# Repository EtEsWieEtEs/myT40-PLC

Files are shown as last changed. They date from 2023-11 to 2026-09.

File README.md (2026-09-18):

# myT40-PLC  (SPS) based on Teensy 4.0 (Version-5)
Hardware for PLC based on Teensy 4.0, covering all my needs. I have to replace my 30 years old PS4-141-MM1 from "Klöcker Moeller", reusing the original case of this model PS4-141-MM1.

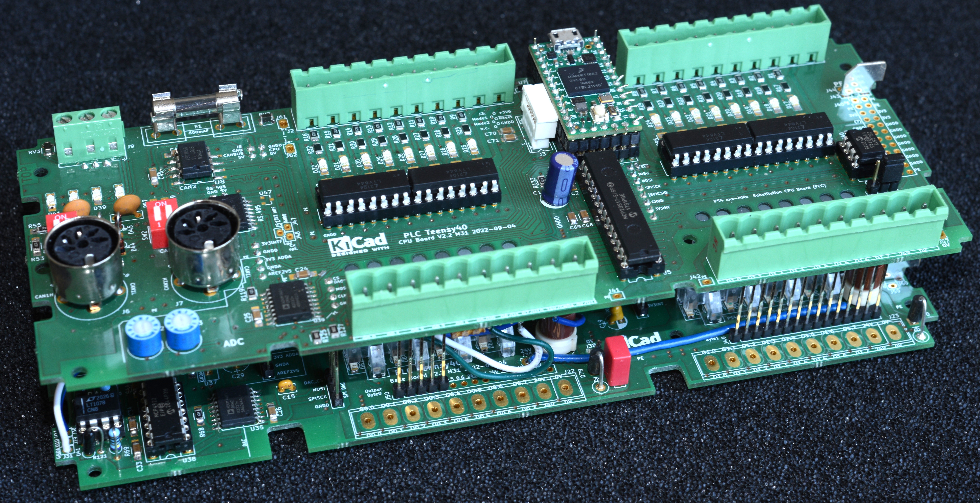
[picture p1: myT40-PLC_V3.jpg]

Picture: Prototype V3

Motivation for a “Mighty 40”
----------------------------
Since the late 1990s, I have been working with four used PS4-141s, one PS4-341, both controllers from Klöckner Moeller, and about two dozen 24V AC surge relays (unfortunately not DC), commonly known as “Eltako,” I planned and developed my “smart home” in the late ’90s and installed it in my new house in 2002. 
The bus systems for building automation that were already on the market at the time were out of the question for me due to licensing issues and costs. 
These control units are networked and seamlessly integrated into my sub-distribution panels—commonly known as “fuse boxes”—on a circuit breaker (C) rail installed at the rear, just like standard circuit breakers. Circuit protection, power, and control are clearly separated in accordance with VDE standards.

Using serial communication, the master controller can be configured during operation using a user-friendly VB program (timer functions, lighting, roller shutters, light level detection, assignment of switches to power outlets such as wall sockets or ceiling outlets for lamps, etc.).

Since these controllers or similar devices are no longer manufactured in this format, the first failures occurred after nearly 30 years of trouble-free operation, and no other manufacturer offers affordable controllers with galvanic isolation(!) in this format anymore, I decided to strip down the PS4-141 housings and develop a new circuit that handles the most important functions and fits into these very housings I have on hand, hereinafter referred to as the “original housing.”

The result is "myT40-PLC", a combination of extention slot of PS4-341 in the housing of an P4S-141.

It is not intended to create a replica of the original, nor is that the goal. Externally, the case has been noticeably modified and fitted with different connectors: the “myT40-PLC”.

Since the circuit itself might also be of interest to others, I designed the main board in two versions for J3: one with an FFC connector, the “FFC” version, for my personal replacement in the original case, and a standard version with a pin header, the “PFS” version, to inspire replicas in any case. The latter is presented here.

This pin header connector "PFS" version offers a 2x DAC option and a 2x ADC option, while allowing the use of all 32 digital I/O channels and providing Sub-D connectors for bus systems in a separate housing. This distinguishes it from the FFC version, which cannot optionally provide all outputs when the DAC and ADC are installed and connected.

A parallel project, myT41-Controller, focuses on a controller unit that provides a graphical interface, Ethernet, CAN and RS485 buses, as well as a serial OTA interface, and allows the myT40 PLC to be controlled, logged, and configured.
With appropriate programming, the myT41C controller can also be used as a protocol converter or logger on the interfaces for entirely different projects.

The software will be documented separately at a later date.
This document describes only the hardware-related port definitions that result from the circuit and are essential for programming.

Attended documents describe the "Final Version V5" as "V3.3 M44", based on experience of 4 prototypes build up in the past 5 years.

The current Version is the final one waiting to be build-up: V5.
I made a lot of changes and enhancements and transfered these features as well to the myT41-Controller.

myT40-PLC      Requirements for my new PLC
------------------------------------------
Even though the new circuit cannot meet all the requirements of the original, I still have a clear idea of what it will be capable of.
The new controller should

1. be installed in my existing original enclosures or any other enclosures,
2. be networked so it can communicate with other devices,
3. ensure isolated potentials for inputs, load circuits, bus systems, ADC/DAC, and controllers; therefore, commercially available Arduino- or Raspberry Pi-based PLCs are out of the question,
4. provide 16 digital inputs and 16 digital outputs as needed, with isolated potentials,
5. support interrupts for input bytes,
6. Provide 4 analog-to-digital converter inputs if required, two of these are fed via built-in setpoint potentiometers,
7. Provide 2 digital-to-analog converter outputs if required,
8. Process analog signals from 0..10V, ADC and DAC, with their own reference potential,
9. Support up to two CAN buses, galvanically isolated, optionally GND, PE shield via capacitor,
10. Provide an RS485 interface for 16 clients, galvanically isolated, bus termination with low-drop diodes or optionally classically with switchable terminating resistor 720/120/720 ,
11. RS485 connection corresponds to the original (V5); the DIN sockets combine CAN1/2 and RS485,
12. be based on a modern, fast processor with sufficient RAM,
13. be supported by an EEPROM/Flash memory,
14. have ICs mounted on sockets wherever possible,
15. support a mode selector switch with 3 modes, including a setting for a cold start via RESET,
16. be able to use the existing RESET button,
17. be able to trigger a RESET via software, including a choice between cold or warm start,
18. ensure local communication via SPI for the interface and function modules,
19. be energy-efficient and operate at 3.3V,
20. be programmed in C or C++,
21. allow communication with a PC or a control unit via CAN, RS485, Ethernet,
22. enable flexible programming,
23. feature a pluggable, wired 3.6V backup lithium battery with its own ADC monitoring,
24. Respond to the 24V AC “Eltako” devices present in the building’s electrical system with 5ms DC pulses (!),
25. Monitor the supply voltages of the CPU and the direct interfaces and, if necessary, perform a warm start or cold start with a reset,     
26. Control the onboard hardware watchdog and/or software watchdog in combination with the operating mode switch, or allow them to function independently.
27. Does not support flexible docking of various original expansion modules; however, a suitable connection panel for SPI and digital I/O is available, though it is incompatible with original expansion modules. Instead, equip the existing 16-channel digital output unit with a new “header board” to make	it usable.
28. No online programming or programming via network, although this might actually be possible.
29. No PWM support on the outputs or counter features on the inputs.
30. External hardware watchdog with adjustable times, including a definable delay on RESET and restart (V5),
31. Buttons for Teensy 4.0 boot/program and on/off (V5),
32. OTA option (V5).
33. F-RAM SPI Option based on SOIC-8

Current developement
---------------------
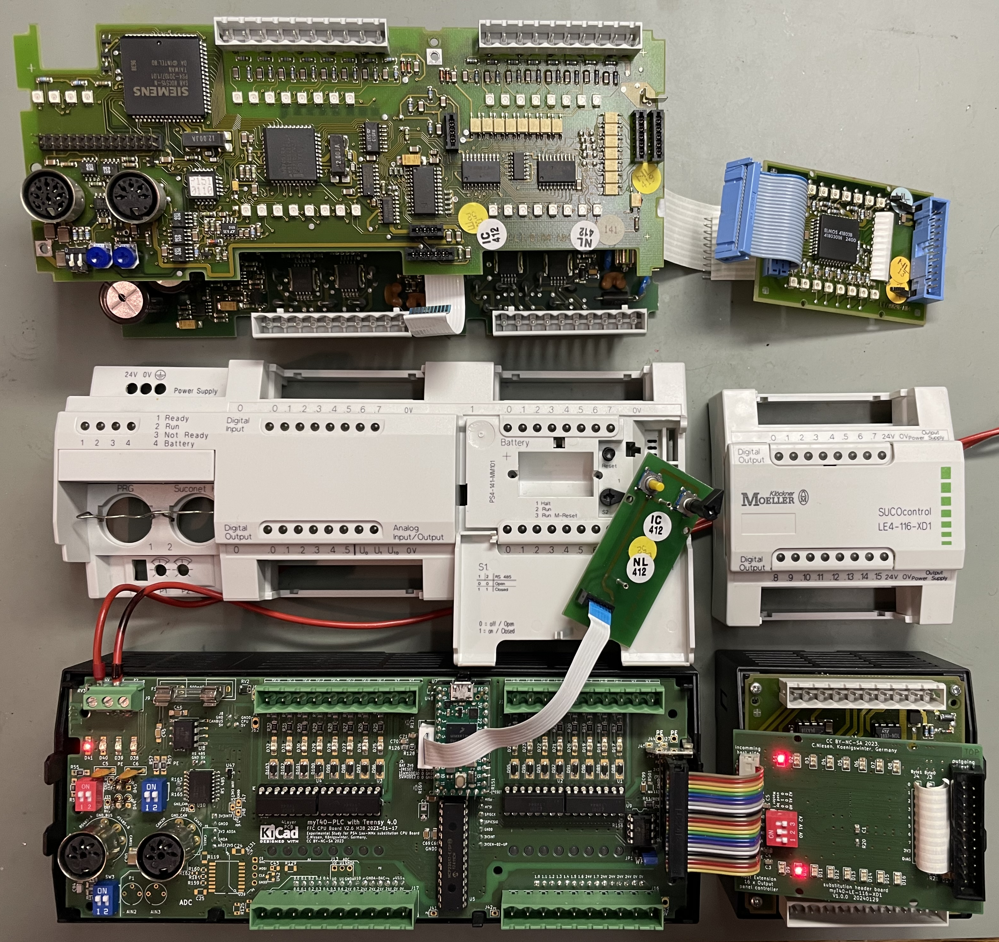
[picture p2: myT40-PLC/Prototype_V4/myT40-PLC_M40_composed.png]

Picture: Prototype V4 below, original defective pcb at top

Now that the Prototype 4 (V4) is working successfully with a 4-layer PCB, I have added an external watchdog and a delay into Version 5.

V5 offers optionally the use of OTA via one of the two serial interfaces instead of a second CAN bus.

Furthermore I think F-RAM is a good alternative for often changed written data to be stored permantly. So V5 provides a place for SOIC-8 alterntive to EEPROM in DIL-8.

However, Version 5 has not yet been built or tested. That is planned for the coming months.

There are some things to do like translation of documentation into English or Spanish, perhaps in next winter.
The current documentation is in German. 
So please be pacient, feel free and be inspired.

Licence
---------------------
This work is licensed under the Creatjve Commons Atuributjon-NonCommercial-ShareAlike 4.0 Internatjonal
License. To view a copy of this license, visit htup://creatjvecommons.org/licenses/by-nc-sa/4.0/ or send a
letuer to Creatjve Commons, PO Box 1866, Mountain View, CA 94042, USA.
This license lets others remix, adapt, and build upon your work non-commercially, as long as they credit you
and license their new creatjons under the identjcal terms.
htup://creatjvecommons.org/licenses/by-nc-sa/4.0/

  Title    myT40-PLC Documentation

  Author   Clemens Niesen, Germany, 2026

  Source   These documents

  Licence  CC-BY-NC-SA

DISCLAIMER
----------

I explicitly state that I make no representations or warranties regarding non-infringement or the absence of other defects with respect to the CC-licensed work.This means that users use the work at their own risk.

Furthermore, I point out that this project and the content of this documentation, as well as associated files, is purely a recreational project and should be understood as a case study for the reader. 

This project, these circuits are not tested or approved by official bodies. Errors can not be excluded despite all care. Whoever reproduces this project does so at his own risk and responsibility. I do not take any responsibility for damages to persons and devices, material, buildings, animals, etc..

Rebuilding is reserved exclusively for experienced people who know exactly what they are doing.  What third-party use of the control with third does and does not, lies apart from the craftsmanship of the construction also with the software, which is also beyond my responsibility. I give no guarantee and take no responsibility for the content of references, links and quotes.

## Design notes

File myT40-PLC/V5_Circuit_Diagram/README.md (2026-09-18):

# myT40-PLC Rev3.3 M44 V5

Die Version-5 (Rev3.3 M44) ist fertig.

Folgende Anpassungen wurden am Prototyp-4 vorgenommen, Ergebnis ist nun die Version-5:
			
2024-02-29	Beschriftungskorrektur FFC 4-Layer, Versionsdatum auf OP-TOP von 2023-01-17 auf 2024-01-17

2024-05-09	M40 Rev.2.8 FFC-4Layer, OP+UP Korrekturen V4 zum Kaltstart: im ausgeschalteten Zustand kein Start möglich ((DOKU FÜR ANPASSUNG VON M38-Platinen))
			- UP: U51 Verpolung von Ub an Pin-3 und Pin-5: Ist= Pin-5:GNDD 0V, Pin-3:Vcc 5V, Soll: Pin-5:Vcc 5V, Pin-3:GNDD, 2 Platinenunterbrechungen und zwei Brücken
			  Man sollte Einzelgatter nicht einfach drehen, und erwarten, dass die Spannungsversorgungsanschlüsse noch die gleiche Orientierung haben...
			- OP: Spannungsteiler R126 und R128 arbeiten nicht im Falle des Systemstarts. Off-Widerstand ist 4080 Ohm von Teensy-Pin-3 (SW_MODE_2)
			  - R126 10k ersetzt durch 220 Ohm SMD 0805  (OP)
			  - R128 16k ersetzt durch Zener-Diode ZF 3,0 Baugröße SOD80(minimelf) ((BZY55B3V0: SMD 0805 zu teuer, wenn man sie als einzige bei mouser bestellt))
			  Damit ist die UinHigh am ODER-Gatter auch größer als 2,3V bei eingesetztem Teensy40
			- RESET ähnlich: RESET=High wird nicht erzeugt, wenn Steuerung startet. Grund: R501||R50=4k76 und Innenwiderstand µC am Teensy40-Pin-4 beträgt 1,341V bei 3,3V Ub PullUp ca. 3258 Ohm. 
			  Damit ist UresetHigh=1,34V zu klein für ODER-Gatter (UinHighMin=2,1V), NE555 wird daher nicht getriggert.
			  - R501 OP) entfällt , da PullUp zu 3V3_INTERFACE , abgeschaltet durch Q2, daher unsinning
			  - R50  10k (UP) ersetzt durch 220 Ohm SMD-0805 , PullUp zu 3V3, erzeugt ein UinHigh am ODER-Gatter von 2,1V mit eingesetztem Teensy40
			  OP: U49 Mit Prototyp-4 muss hier ein Voltage-Translator verwendet werden, Ub=5V, UinA/B 3,3V Level : SN74LV1T32DBVR oder SN74LV1T32DBVRG4
			  UP: Darstellung Modell-Platinen-Aufdruck D51 gedreht, Anode jetzt auf Ub, 
			      D-Symbole in Bedruckung eingezeichnet.
			  OP: Darstellung Modell J3 korrekt gedreht
2024-06-30	Da die CPU beim Start weit über 100mA zieht, fällt die Versorgungsspannung auf 3,4V und U48 löst einen RESET=Low aus. 
			Im Falle von SW_MODE_2=Low für einen Kaltstart beduetet das eine Endlosschleife vor dem Start der CPU. U48 entfällt.
			Aus dem gleichen Grund wird C1, Glättung auf der 3,3VInterface-Schiene entfernt, 100µF sind zu groß.
			C1 bleibt erst einmal ohne Bestückung und damit optional.
	
2024-06-09	M41 Rev.2.9 FFC-4-Layer: OP+UP Verbesserung und Korrekturen von M40 eingebaut: 
			3V3 kommt über weiteren Pin (J34/J36) von UP nach OP, statt aus örtlich permanent vorhandener 5V_CPU_IN mittels Zenerdiode 3V0
			- Damit entfällt die 3V-Zener-Diode D50 von Rev_2.8_M40
			- Der Widerstand R126 wird von 2k7 auf 1k oder 220 Ohm geändert.
			
2024-08-03	M42	Rev.3.0 FFC-4-Layer: OP
			Hardware Watchdog hinzugefügt TPS3431, PullUp Diode D50 nötig, da TPS3431 einen open collector hat, muss PushPull des U49 beschnitten werden.
			Prog und OnOff auf Switches SW4 und SW5 gelegt, am Platinenrand von außen erreichbar
2024-06-10	SMD Testpoints TP1-4 für LED1(WDin), 3V3, TR, Q

2024-11-7	M43	Rev.3.1 FFC-4-Layer: OP
			Aus M39 RS485-Beschaltung übernommen: RS485 Belegung identisch zum Original, CAN1+RS485 auf J7, CAN1+CAN2 auf J6
			Jumper JP6 entscheidet ob auf J7-Pin-2 GND von CAN oder RS485 anliegt, Jumper erreichbar im Schacht
			SW2 von CAN2 und Busabschluss-Dioden RS485 haben Positionen getauscht.
			Leiterbahnführungen überarbeitet, Lage der GND-Potentiale auf den den Signalen gegenüberliegenden Layern korrigiert
			Kompatibilität zu M42 bleibt erhalten
			
2025-04-06	M43 Konvertierung nach KiCad6 und KiCad7
			UP von HomeTeensy40_PFS-4_3.0_M42, kompatibel zu OP M38 und OP M43
			OP von HomeTeensy40_FFC-4_3.0_M42-RS485-Sond als HomeTeensy40_FFC-4_3.0_M42-RS485-Sond_K7
			Diverse Leiterbahn-Optimierungen

2025-05-03	M43	Rev.3.1 FFC-4-Layer: OP
			///TPS3890 Delay bei Kaltstart für Watchdog von 16s, als Idee skizziert
			Watchdog-Zeiten festgelegt: 1.6s, 3,6s, 11s, 20s
			Kompatibilität zu M42 bleibt erhalten

2025-07-08	M43	Rev.3.1 FFC-4-Layer: OP
			///U52 NE555-CMOS Delay bei Kaltstart für Watchdog bei jedem RESET von 1,6-12,7sec, als Idee skizziert
			///U53 Inverter CMOS, invertiert Ausgang NE555 , um eine Einschaltverzögerung zu bekommen.
			///RESET steuert U52, damit beginnt der Delay für den WD bei Kalt- und Warmstart.

2025-08-14	M43	
			Delay bei Kaltstart für Watchdog: U52 kein NE555 und kein TPS3890 sondern ein S-80929CNMC 
			( HIGH-PRECISION VOLTAGE DETECTOR WITH DELAY CIRCUIT (EXTERNAL DELAY TIME SETTING))
			steuert EN_WD am HW-WD an und verzögert dessen Aktivierung, wenn TR_U50 wieder High wurde, bzw bei KaltStart mit C106=3µ3 für 18sec
			U53 Buffer-Inv für LED D123/R175 auf EN_WD  , On wenn EN_WD=Low
			U54 Buffer-Inv für LED D123/R175 auf TR_U50 , On wenn TR_U50=Low
			
2025-10-05	M43 FFC für J3 mit PFS erzeugt. Abschluss als V3.1

2025-12-31	M43 FFC + PFS V3.1
			OP : Vertauschen von CAN1 und CAN2 am Teensy. Das ermöglicht die optionale Nutzung der Seriellen Schnittstelle RX1/TX1 alternativ zu CRX1/CTX1 für ein OTA-Modul
			Dabei steht CAN2 auf beiden DIN-Buchsen zur Verfügung, parallel zu RS485.

2026-05-17	M43 FFC + PFS V3.2 , OP & UP   --> V5
			U40 und R50 auf die OP. U40 mit Reset-Ausgang auf TR-U50, R50 als Pull-UP für RESET.
			Das hat den Vorteil, dass ein Spannungsabfall unter die Schwelle von U40, CPU und Interfaces abschaltet.

FFC only:
========================

2026-05-26	M43 FFC V3.2 , OP & UP   --> V5
			Modifikation der PE-Flächen-Abstände zu anderen Potentialen auf mindestens 1mm in allen Lagen
			OP in PFS noch nicht angepasst.
			LED1 Leiterbahn verlegt, da zu nah an PE
			Alternative zu ISO1050 ist der ADM3050E, der einen vertauschten Anschluss für TXD und RXD hat.
			Um für deren eventuelle Verwendung einen Leiterbahnpatch zu ermöglichen, wurden die Endstücke der CAN1RX/CAN2TX vom inneren Layer 
			IN1 auf B-Layer per Via gelegt. Siehe B-Silk-Markierungen "X" bei "*3" unter der Teensy CPU. Das gleiche ist am ISO1050 für beide
			Busse möglich.
			PE-Optimierung im DIN-Anschluss-Feld

2026-05-31	M43 FFC V3.2 , OP & UP   --> V5
			Komplett-Modifikation Potential-Abstände OP und UP in Version FFC
			J8/J21, J36/J34 neu geteilt und auf mehr Abstand GNDD zu GND_CAN
			J25/J24 geteilt und zu J33/J47 auf mehr Abstand für GNDD und GNDA
			PE und LED1,2,3 Leitungsführung optimiert. Ub_CAN geändert.
			RV4, RV5, RV6 Isolierte GND_*-Potentiale mit 46VAC gegen PE abgesichert
			CANRX/CANTX Leitungen getauscht um PROG- und ONOFF-Switch unter die CPU verlagern zu können, damit Abstand von GNDD-bezogenen
			Potentialen zu PE und 24V-Input vergrößert werden kann.
			Mindest-Abstand überall mindestens 1,1mm.

(2026-07-25)	M43 FFC V3.2 , OP        --> V5
			U55 SOIC-8 Alternativer Foodprint zu DIL-8 von U9, z.B. auch für FM-25er SPI-FM-RAM
			CS für U55 kann durch auftrennen auch separat angesteuert werden (Fädeldraht von anderem ungenutzten CS-Signal).
			Damit waren zwei Speicherbausteine ansprechbar, einer in DIL-8 und ein zweiter mit SOIC-8.

2026-07-25	M44 FFC V3.3 , OP & UP   --> V5
			OP: U55 SOIC-8 Alternativer Foodprint zu DIL-8 von U9, z.B. auch für FM-25er SPI-FM-RAM
			    CS für U55 kann durch auftrennen auch separat angesteuert werden (Fädeldraht von anderem ungenutzten CS-Signal).
			    Damit waren zwei Speicherbausteine ansprechbar, einer in DIL-8 und ein zweiter mit SOIC-8.
			    R172 versetzt, war zu dicht an J3
			UP: Output-LED intern angesteuert. Es entfallen die Bauteile R102-R109, D106-D113, R110-R117, D114-D121
			OP: R173 und D52, beide optional sind entfallen, da eine Kombination mit einer UP V4 nicht mehr möglich ist, wegen der
			    Verschiebung der Potentiale an den Verbindungen zwischen OP und UP.
20260904	M44 PFS V3.3, OP + UP    --> V5 
			Variante PFS bereitgestellt.

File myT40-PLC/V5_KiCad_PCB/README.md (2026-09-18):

KiCad 9.0.7

myT40-PLC Rev3.3 M44 V5 PFS

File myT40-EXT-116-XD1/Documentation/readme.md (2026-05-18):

Modification of existing original local extension unit LE-116-XD1.

Documentation found in document for myT40-PLC chapter 14.

Keep in mind, that this reflects a modification of an original LE-116-XD1 module.
This is the description how to connect this 16-Output module to myT40-PLC using the modified extension slot.
To make this possible, the existing header PCB must be exchanged by this one decribed here.

Original extention modules must not connect to myT40-PLC, due to different and unknown protocol and connectivity.

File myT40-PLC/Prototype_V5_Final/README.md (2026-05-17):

Final Version V5 has not been build yet.

You see here KiCad Views only.

Production is planned for next months.

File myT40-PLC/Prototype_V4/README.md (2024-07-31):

You see here myT40-PLC and a modified 16 channel digital IO fitted to myT40-PLC.

- myT40-PLC V4 below mounted in open original case,
- top part of original case in the middle,
- removed original innards on top

I did not mount the parts for ADC nor DAC, because I won't used it in the role as master-PLC for my home automation project.
Next I will build up 5 other myT40-PLCs in different component compositions.

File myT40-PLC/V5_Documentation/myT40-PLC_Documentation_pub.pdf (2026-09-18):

# myT40-PLC

### Neue PLC im alten Gewand – Eine Studie

Upcycling einer defekten KlöcknerMoeller SPS PS4-1x1

Rev3.3 - *nale Version 5 - PFS/FFC
Ein An1depressivum aus Corona-Zeiten

Clemens Niesen
2020-2026

myT40-PLC | Historie
Version 0.0 | ab Mai 2018 | Gedankenspiele mit Arduino Due
Ausprobieren von KiCad 4.x
Version-0 | 1.12.2020 | Steckbre%-Au&auten mit Teensy 4.0 und 4.1
Version-1 | 22.4.2021 | PLC HT40 | M00 | V1.2.1 (Prototyp1)
Version-2 | 16.01.2022 | PLC HT40 | M16 | V1.5 | (Prototyp2) | (Titelbild¹ )
Version-3 | 04.09.2022 | PLC HT40 | M31 | V2.2 | (Prototyp3)

Projekt umbenannt in myT40-... im August 2023

Version-4 | 23.11.2023 | myT40-PLC | M38 | V2.6 | (Prototyp4)
17.01.2024 | myT40-PLC | Modi4ka5onen & 4-Layer für OP
Version-5 | 31.08.2024 | myT40-PLC | M42 | V3.0 | (Version nal PFS)
Modi4ka5onen OP/UP
External HW-Watchdog
Bu%ons OnO@/Prog
Version-5 | 11.08.2025 | myT40-PLC | M43 | V3.1 | (Version nal FFC+PFS)
FFC-Version: RS485 PS4-like Watchdog-Start-Delay
Update auf KiCad_V9
Version-5 | 31.12.2025 | myT40-PLC | M43 | V3.2 | (Version nal FFC+PFS)
OTA Op5on: CAN1 <-> CAN2 Tausch größere Poten5al-Abstände bei Verbindungen OP ↔ UP
Version-5 | 25.07.2026 | myT40-PLC | M44 | V3.3 | (Version nal FFC+PFS)
UP: Output-LED wieder intern angesteuert Sta5sches F-RAM im SOIC-8
Zuletzt edi5ert am 18.09.2026 | Dokumenta5on der Änderungen,
| | | | | siehe Kapitel 11

### 1 Titel-Foto: Es zeigt die Version V2 für ein beliebiges Gehäuse aus 2022

ii

### Licence

Dieses Werk ist unter einer Crea5ve Commons Lizenz vom Typ „Namensnennung - Nicht-kommerziell -Weitergabe unter gleichen Bedingungen 4.0 Interna)onal“ zugänglich. Um eine Kopie dieser Lizenz einzusehen, konsul5eren Sie h%p://crea5vecommons.org/licenses/by-nc-sa/4.0/ oder wenden Sie sich brieRich an Crea5ve Commons, PosSach 1866, Mountain View, California, 94042, USA.

Title | myT40-PLC Documenta)on
Author | Clemens Niesen, Germany, 2021-2026
Source | This document, and related ones
Licence | CC-BY-NC-SA

This work is licensed under the Crea5ve Commons „A2ribu)on-NonCommercial-ShareAlike 4.0 Interna)onal License“. To view a copy of this license, visit
h%p://crea5vecommons.org/licenses/by-nc-sa/4.0/
or send a le%er to Crea5ve Commons, PO Box 1866, Mountain View, CA 94042, USA.

This license lets others remix, adapt, and build upon your work non-commercially, as long as they credit you and license their new crea5ons under the iden5cal terms. h%p://crea5vecommons.org/licenses/by-nc-sa/4.0/

myT40-PLC C.Niesen CC-BY-NC-SA 2026 | iii

### Ha8ungsausschluss

Ausdrücklich weise ich darauf hin, dass ich keine Zusicherungen oder Garan)en hinsichtlich der Nichtverletzung von Rechten oder des Fehlens anderer Mängel in Bezug auf das CC-lizenzierte Werk gebe. Das bedeutet, dass die Nutzer das Werk auf eigenes Risiko nutzen.

Ferner weise ich darauf hin, dass dieses Projekt und der Inhalt dieser Dokumenta)on, sowie zugehöriger Dateien ein reines Freizeitprojekt und für den Leser als Fallstudie zu verstehen ist. Dieses Projekt, diese Schaltungen sind nicht durch o=zielle Stellen geprü> oder abgenommen. Fehler sind trotz aller Umsicht nicht auszuschließen. Wer dieses Projekt nachbaut, tut dies auf eigene Gefahr und Verantwortung. Für Schäden an Personen und Geräten, Material, Gebäuden, Tieren, etc. übernehme ich keinerlei Verantwortung. Der Nachbau ist ausschließlich versierten Menschen, die genau wissen was sie tun, vorbehalten. Was eine Verwendung der Steuerung bei Dri2en tut und was nicht, liegt neben der handwerklichen Ausführung des AuAaus auch an der So>ware, die sich ebenfalls meiner Verantwortung entzieht.

Ich gebe keine Gewähr und übernehme keine Verantwortung für den Inhalt von Verweisen, Links und Zitaten.

### DISCLAIMER

I explicitly state that I make no representa5ons or warran5es regarding non-infringement or the absence of other defects
with | respect | to | the | CC-licensed | work.This | means | that | users | use | the | work | at | their | own | risk.
Furthermore, I point out that this project and the content of this documenta5on, as well as associated 4les, is purely a recrea5onal project and should be understood as a case study for the reader. This project, these circuits are not tested or approved by oTcial bodies. Errors can not be excluded despite all care. Whoever reproduces this project does so at his own risk and responsibility. I do not take any responsibility for damages to persons and devices, material, buildings, animals, etc.. Rebuilding is reserved exclusively for experienced people who know exactly what they are doing. What third-party use of the control with third does and does not, lies apart from the craUsmanship of the construc5on also with the soUware, which is also beyond my responsibility. I give no guarantee and take no responsibility for the content of references, links and quotes.

Dieses Projekt widme ich meinem alten Freund Norbert Schulz aus Berlin Kreuzberg. Wir haben zusammen in den 70ern in Berlin-Tiergarten am Canis die Schulbank gedrückt.
Er hat mir zu meinen ersten Elektronik-Erfahrungen verholfen und eine bis heute anhaltende Begeisterung für dieses Thema geweckt.
Leider haben wir uns in den 80ern aus den Augen verloren.

Clemens Niesen

iv | myT40-PLC C.Niesen CC-BY-NC-SA 2026

## Inhalt

myT40-PLC C.Niesen CC-BY-NC-SA 2026 | v

vi | myT40-PLC C.Niesen CC-BY-NC-SA 2026

### 9.9 Berechnung Netzwerk digitale Ausgänge | 59 9.10 Berechnung Netzwerk Analoge Eingänge | 60 9.11 Hinweis Eingangs-Terminals „0V“ | 60 9.12 SPI-Serien-Widerstände | 60 9.13 Bezug DIN-5 Pol -Buchse | 60

### 10 So>ware myT40-PLC | 61

### 10.1 Prinzipieller Programmablauf und Kon4gura5on | 61

### 10.1.1 Port-De4ni5on der myT40-PLC | 62

### 11 Release Notes der Publika)on | 63

### 11.1 myT40-PLC | 63

11.1.1 V2.6 M36 Version-4 (PFS) erstmalig publiziert im August 2023 | 63 11.1.2 V2.6 M37 Version-4 (PFS) 23.11.2023 | 63 11.1.3 V2.6 M38 Version-4 (PFS) 17.01.2024 Pre-Final Prototype, produziert | 63 11.1.4 V3.0 M42 Version-5 (PFS+FFC) 03.08.2024 | 64 11.1.5 V3.2 M43 Version-5 (FFC) 17.05.2026 4nal version V5 | 64 11.1.6 V3.3 M44 Version-5 25.07.2026 4nal version V5 | 64

### 12 Stückliste Rev3.3 M44 V5, Variante PFS, Vollbestückung | 65

### 13 Erweiterungsmodul für 16 Ausgänge | 77

### 13.1 Die Schaltung des myT40-116-XD1 | 77 13.2 Schaltplan Lokale Erweiterung myT40-116-XD1 | 78 13.3 Pla5nenlayout myT40-116-XD1 | 79

### 14 Verwendete So>ware für dieses Projekt | 82

### 14.1 KiCad | 82 14.2 Arduino | 82 14.3 Teensyduino | 82 14.4 MicrosoU Visual Studio Code (VSC) | 83

### 14.4.1 VSC-Extension „C/C++ for Visual Studio Code“ | 83 14.4.2 VSC-Extension „C++ Intellisense“ | 83 14.4.3 VSC-Extension „German Language Pack for Visual Studio Code“ | 83 14.4.4 VSC-Extension „GitLens — Git supercharged“ | 83 14.4.5 VSC-Extension „PlaSormIO IDE“ alias PIO | 83

### 14.5 PIO - PlaSom IDE für Teensy | 83 14.6 PIO Libraries für Teensy / Arduino | 83

### 14.6.1 MCP_DAC by Rob Tillaart V 0.1.6 | 83 14.6.2 Mcp320x by Patrick Rogalla 1.4.2 | 83 14.6.3 GUIslice by Calvin Hass 0.16.0 / 0.17.x | 83 14.6.4 Hotboards_eeprom by Hotboards MX | 84 14.6.5 ACAN_T4 by Pierre Molinaro | 84 14.6.6 Teensy 4.x | 84

### 15 Datenaustausch myT41C-Controller mit myT40-PLC-Nodes | 85

myT40-PLC C.Niesen CC-BY-NC-SA 2026 | vii

## Abbildungsverzeichnis

Abbildung 3: Die Variante OP-PFS mit Pfostenstecker 2x4 Pin-Header für J3, einige Bauteile hier nicht

Abbildung 6: Prinzipschaltbild Kaltstart, Reset-Logik und Hardware-Watchdog mit Delay (ab V5 M43)

x | myT40-PLC C.Niesen CC-BY-NC-SA 2026

Abbildung 42: Final Prototype-5 Rev3.3 M44 V5: OP Layer : TOP, IN1, IN2 | 43
Abbildung 43: Alterna5ve Status-LED Verdrahtung FFC/PFS Rev-3.3 M44 V5 | 49
Abbildung 44: Ground für RS485- oder CAN-Bus | 53
Abbildung 45: Extension-Slot | 53
Abbildung 46: myT40-LE-116-XD1 Erweiterung für myT40 16 Digital Out, 500mA 24V | 78
Abbildung 47: myT40-116-XD1 Oberseite | 79
Abbildung 48: myT40-116-XD1 Unterseite | 79
Abbildung 49: Prototyp-V2 M16 in Eigenbaugehäuse aus 5mm Plexiglas | 104
Abbildung 50: Prototyp-V2 M16, Seitenansicht | 104
Abbildung 51: Die fer5g zusammengesteckten Pla5nen Rev2.2 M31, Prototyp-3, bestückt mit
ADC+DAC und 5 Ausgängen auf Byte-0, sowie drei Status-LED und 5 Ausgängen auf Byte-0 | 111
Abbildung 52: myT40-PLC Rev2.6 M38 V4 FFC Oberpla5ne Oberseite | 112
Abbildung 53: myT40-PLC Rev2.6 M38 V4 FFC Oberpla5ne Unterseite | 113
Abbildung 54: Prototyp-V4Rev2.8 M38 mit allen weiteren Korrekturen bis M40 und lau@ähigem
Kaltstart, sowie einer modi4zierten lokalen Erweiterung, beides im Originalgehäuse | 118
Abbildung 55: myT40-PLC Rev3.3 M44 V5 PFS Oberpla5ne Oberseite | 119
Abbildung 56: myT40-PLC Rev3.3 M44 V5 PFS Oberpla5ne Unterseite | 119
Abbildung 57: myT40-PLC Rev3.3 M44 V5 FFC Oberpla5ne Oberseite | 120
Abbildung 58: myT40-PLC Rev3.3 M44 V5 FFC Oberpla5ne Unterseite | 120
Abbildung 59: myT40-PLC Rev3.3 M44 V5 Unterpla5ne Oberseite | 121
Abbildung 60: myT40-PLC Rev3.3 M44 V5 Unterpla5ne Unterseite | 121
Abbildung 61: myT41C V1 Schaltplan | 123
Abbildung 62: myT41C Contoller V1 Rev1.0.2: Störungen auf T_IRQ, aufgestecktes Display nicht
dargestellt | 124
Abbildung 63: myT41C V1 : Einbau R-C-Glied in T_IRQ-Leitung | 124
Abbildung 64: myT41C Rev1.0.2 V1 Unterseite bestückt | 125
Abbildung 65: myT41C Rev1.0.2 V1, Unterseite THT unbestückt | 125
Abbildung 66: myT41C V2 Schaltplan Rev3.1 M10 , CPU und Peripherie | 126
Abbildung 67: myT41C V2 Schaltplan Rev3.1 M10 , Watchdog , Delay , Abschaltung | 127
Abbildung 68: myT41C Rev3.1 M10 , Oberseite ohne Display | 128
Abbildung 69: myT41C Rev3.1 M10 , Unterseite ohne THT Bestückung | 129
Abbildung 70: myT41C Rev3.1 M10 , Unterseite bestückt | 129
myT40-PLC C.Niesen CC-BY-NC-SA 2026 | xi

xii | myT40-PLC C.Niesen CC-BY-NC-SA 2026

myT40-PLC Documenta5on

## 1 Mo1va1on für einen „mighty 40“

Seit Ende der 90er Jahre habe ich mit vier gebrauchten PS4-141, einer PS4-341, beide Steuerungen der Fa. Klöckner Moeller, und rund zwei Dutzend 24V-AC-Stromstoß-Relais (nicht DC²
), landläu4g „Eltako“ genannt, mein „Smart-Home“ Ende der 90er geplant, entwickelt und 2002 in meinem Neubau installiert. Damals schon am Markt be4ndliche Installa5ons-Bus-Systeme kamen für mich wegen Lizenzen und Kosten nicht in Frage.

Diese Steuerungen sind vernetzt und in meinen Unterverteilungen, landläu4g „Sicherungskästen“ genannt, auf einer nach hinten verlegten Automaten-(C-)Schiene nahtlos wie normale Sicherungsautomaten
eingebaut. | Leitungsschutz, | Leistung | und | Steuerung | sind | VDE-konform | sauber | getrennt.
Mi%els serieller Kommunika5on kann der Master der Steuerungen mit einem komfortablen VB-Programm im laufenden Betrieb parametriert werden (ZeitschalSunk5onen, Licht, Rollladen, Helligkeitsauswertung, Zuordnung von Schaltern zu Verbrauchsstellen, wie Steckdosen oder Deckenauslässe für Lampen, etc).

Da diese Steuerungen oder vergleichbare Geräte in diesem Format nicht mehr gebaut werden, es nach fast 30 Jahren problemlosen Betriebes erste Ausfälle gab und auch kein anderer Hersteller bezahlbare Steuerungen mit Poten5al-Trennungen(!) in diesem Format mehr anbietet, habe ich beschlossen, die PS4-141er- Gehäuse zu entkernen und eine neue Schaltung zu entwickeln, die die wich5gsten Funk5onen übernimmt und in eben diesen, mir vorliegenden Gehäusen ihren Platz 4ndet, im weiteren Verlauf „Originalgehäuse“ genannt. Ein Nachbau des Originals ist nicht gewollt und auch nicht der Anspruch. Von außen wurde das Gehäuse erkennbar modi4ziert und mit anderen Anschlüssen versehen: der „myT40-PLC“.

Weil die reine Schaltung vielleicht auch für Dri%e interessant sein könnte, habe ich die Oberpla5ne in zwei Versionen für J3, eine mit FFC-Stecker, Version „FFC“, für meinen privaten Ersatz im PS4-Originalgehäuse und eine freie Version mit Pfostenstecker „PFS“ zur Anregung für Nachbauten in beliebigen Gehäusen konzipiert. Letztere soll hier vorgestellt werden.

Diese „Pfostenstecker“-PFS-Version bietet 2*DAC-Op5on und 2*ADC-Op5on und erlaubt gleichzei5g alle 32 digitalen I/O nutzen zu können, sowie die Möglichkeit Sub-D-Buchsen für die Bus-Systeme in einem anderen Gehäuse bereitzustellen. Darin unterscheidet sie sich von der FFC-Version, die op5onal nicht alle Ausgänge bereitstellen kann, wenn DAC und ADC bestückt und angeschlossen sind.

Dieses Projekt hat mich während der Corona-Pandemie mo5viert und über Wasser gehalten. Bis heute.

C.Niesen, Juni 2026

Anmerkung
Ein Parallelprojekt myT40C beschäUigt sich mit einer Controller-Einheit, die ein gra4sches Interface, Ethernet, CAN- und RS485-Bus, sowie ein serielle OTA-Interface bereitstellt und es erlaubt, die myT40-PLC zu steuern, zu protokollieren und zu parametrieren.

Der Controller myT41C lässt sich durch entsprechende Programmierung auch als Protokollkonverter oder Logger auf den Interfaces für ganz andere Projekte verwenden.

Die SoUware wird später separat dokumen5ert.
In diesem Dokument werden nur die hardwarenahen Port-De4ni5onen beschrieben, die sich aus der Schaltung ergeben und für eine Programmierung wesentlich sind.

2 AC-Eltakos haben den Vorteil, dass man die Steuerung wieder enSernen und alle Licht-Taster mit einem 24V Klingeltrafo betreiben kann. In der Tat habe ich alle Schalter/Taster separat in die Unterverteilungen verdrahtet.

myT40-PLC C.Niesen CC-BY-NC-SA 2026 | 1

myT40-PLC Anforderungen an die neue SPS

## 2 myT40-PLC Anforderungen an die neue SPS

Auch wenn die neue Schaltung nicht alle Funk5onen des Originals erfüllen kann, habe ich folgende Anforderungen de4niert.

Die neue Steuerung soll

1) in den meinen vorhandenen Originalgehäusen und beliebigen anderen eingebaut werden,
2) vernetzt sein, um mit weiteren Geräten kommunizieren zu können,
3) getrennte Poten5ale für Eingänge, Last-Stromkreise, Bussysteme, ADC/DAC und Controller gewährleisten, daher kommen erhältliche PLC auf Arduino- oder Raspberry-PI Basis nicht in Frage,
4) bei Bedarf 16 digitale Eingänge und 16 digitale Ausgänge bereitstellen, Poten5al-getrennt,
5) InterrupSähigkeit der Eingangsbytes,
6) bei Bedarf 4 Analog-Digital-Konverter Eingänge,
davon 2 über eingebaute Sollwert-Poten5ometer zugeführt,
7) bei Bedarf 2 Digital-Analog-Konverter Ausgänge bereitstellen,
8) analoge Signale von 0..10V verarbeiten, ADC und DAC, mit eigenem Bezugspoten5al,
9) bis zu zwei CAN-Busse bedienen, Poten5al-getrennt, op5onal GND, PE Schirm via Kondensator,
10) eine RS485-Schni%stelle für 16 Clients vorsehen, Poten5al-getrennt, Busabschluss mit Low-Drop-Dioden oder op5onal klassisch mit zuschaltbarem Abschlusswiderstand 720/120/720 Ω,
11) RS485-Anschluss entspricht dem Original (V5), die DIN-Buchsen kombinieren CAN1/2 und RS485,
12) auf einem modernen schnellen Prozessor mit hinreichend RAM basieren,
13) von einem EEPROM/Flash unterstützt werden,
14) soweit möglich ICs auf Sockeln mon5ert haben,
15) den Betriebsarten-Schalter mit 3 Modi unterstützen, eine Stellung für Kaltstart durch RESET,
16) den vorhandenen RESET-Taster nutzen können,
17) einen RESET per SoUware auslösen können, HW-Vorgabe Kalt- oder Warmstart,
18) für die Interface- und Funk5ons-Bausteine die lokale Kommunika5on mit SPI sicherstellen,
19) Strom sparend mit 3,3V betrieben werden,
20) in C, C++ programmiert werden,
21) Kommunika5on mit einem PC oder einer Bedieneinheit via CAN, RS485, Ethernet erlauben,
22) Rexible Programmierung ermöglichen,
23) steckbare, bedrahtete 3V6 Backup-Lithium Ba%erie, mit eigenem ADC-Monitoring,
24) die in der Hausinstalla5on vorhandenen 24V AC-„Eltako“ mit 5ms-DC-Impulsen (!) ansprechen,
25) Versorgungsspannungen der CPU und der direkten Interfaces überwachen und ggf. mit einem Reset einen Warmstart oder Kaltstart ausführen, BOR (Brownout Reset),
26) Onboard-Hardware-Watchdog und/oder SoUware Watchdog in Kombina5on mit Betriebsarten-Schalter steuern, oder agieren lassen können.
27) Verzicht auf Rexibles Andocken von diversen Original-Erweiterungsmodulen, aber ein passendes Anschlussfeld für SPI und Digital-I/O ist vorhanden, jedoch inkompa5bel zu Originalerweiterungsmodulen. Sta% dessen für vorhandene 16-fach Digital-Ausgabe-Einheit mit neuer „Kopfpla5ne“ versehen und nutzbar machen.
28) Verzicht auf Online-Programmierung und Programmierung über Netzwerk, obwohl das vielleicht sogar per OTA möglich wäre.
29) Verzicht auf PWM Unterstützung an den Ausgängen oder Counter-EigenschaUen an den Eingängen.
30) ext. Hardware Watchdog mit einstellbaren Zeiten, inklusive de4nierbarem Delay bei RESET/Restart
31) Bu%ons für Teensy 4.0 Boot/Prog und On/O@ (V5),
32) OTA Op5on (V5).
33) F-RAM per SPI bereitstellen, Alterna5v oder zusätzlich zum EEPROM

### 2 myT40-PLC C.Niesen CC-BY-NC-SA 2026

myT40-PLC Documenta5on

## 3 Die Hardware

### 3.1 Allgemeiner Überblick

Das Originalgehäuse einer PS4-141 enthält zwei beidsei5g bestückte Pla5nen. Ausgangs-Poten5ale und deren Terminals sowie Spannungsversorgungen sind auf der unteren Pla5ne angeordnet, ebenso der DAC. Die Ausgangsklemmen werden über eine 30mm hohe „stacked“ Variante der normalen Kontaktleiste auf die Höhe der oberen Pla5ne in passende Ausbrüche verlegt.

Das Original der oberen Pla5ne enthält die CPU, RAM und Interface-Bausteine, sowie Optokoppler für Einund Ausgänge, die Fassung für das Memory-Modul und alle weiteren Anschlüsse.

Diese Konstruk5on habe ich in Ermangelung von Spezialbauteilen, wie den 30mm stacked Terminals, oder den VN330SP³
Ausgangstreibern nicht übernommen. Auch habe ich bis zur Version-3 auf die Verwendung von 4-Lagen-Mul5layer-Pla5nen verzichtet und versucht mit 2 Lagen auszukommen, allerdings auf Kosten der Signaltreue⁴
, ab V4 besitzt die OP mit 4 Lagen eine bessere GND/PE De4ni5on. Ein weiteres Problem ist die Bescha@ung der 5-Pol-DIN-Winkel-Stecker des Originals in ihrer kompakten Form, sie sind am freien Markt nicht zu 4nden.

Meine Konstruk5on enthält auf der oberen Pla5ne (OP) das CPU-Modul Teensy-4.0, die Optokoppler und die Terminals für die Eingänge, den ADC und seinen Isolator, die lokale Erweiterungssteckleiste, zwei ISO CAN-Busse und einen RS485-Bus mit Isolator, sowie ein EEPROM, externem Watchdog plus Delay. Es gibt noch einen ungenutzten Connector für Teensy-4.0 spezi4sche Signale (OnO@,Programm, 3V3 und 0V GNDD). Version-5 (V5) legt „On/O@“ und „Programm“ auf zwei am Pla5nenrand verbaute ver5kale Taster.

Außerdem lässt sich über J3 eine Ba%erie (3,6V Lithium oder 3V-Knopfzelle), der RESET-Taster und der Mode-Wahlschalter anschließen. Die Oberpla5ne gibt es mit diesem J3 in zwei Varianten, einmal mit FFC 6pol RM1.25mm für den Einbau in meine Originalgehäuse, und einmal für Pfostenstecker (PFS) als 8-Pin-Header 2x4 RM2,54mm für den Einbau in beliebige andere Gehäuse.

Auf der oberen Pla5ne (OP) sitzen die Ausgangs-Terminals, die mit der unteren Pla5ne über eine weitere nach unten gerichtete Steckverbindung verbunden sind, sowie ein Reset-Generator (POR). Dieser dient als Power-On-Reset für den RS485-Baustein und verhindert ungewollten Betrieb am Bus während der Einschaltphase. Hier be4ndet sich auch der externe Hardware-Watchdog mit seinem Delay-IC.

Auf der Unterseite der Oberpla5ne be4ndet sich zudem eine Kaltstart-Logik, verknüpU mit SW_MODE_2 (Originalgehäuse Betriebsarten-Mode-Schalter in Posi5on-0) und dem Reset-Signal zur CPU und den Interface-Bausteinen. Die Spannungsversorgungen und andere Verbindungen werden über Stapelleisten-Buchsen zwischen den Pla5nen übertragen. Hier be4ndet sich auch ein 3V3-Monitor mit RESET als BOR.

Auf der Unterpla5ne (UP) werden die Ausgänge über Stapelleisten auf die Oberpla5ne (OP) geführt. Diese werden auf der UP eingelötet, nachdem der untere Pin-Spreader soweit nach innen verschoben wurde, dass die resul5erende Länge mit ihrem Gegenstück für das Originalgehäuse einen Abstand der beiden Pla5nen zueinander von 29mm erlaubt. Es be4nden sich dort die Leistungsschalter der digitalen Ausgänge, alle Spannungsversorgungsbauteile, der DAC mit Isolator, der Interfacebaustein zur Ansteuerung der Ausgänge und die zugehörigen Optokoppler nebst Kontroll-LEDs der Ausgänge.

Da die LED der Ausgänge auf der unteren Pla5ne sitzen, wird ihr Licht durch passende Lichtleiter bis zu den Bohrungen in der darüberliegenden Oberpla5ne geleitet und dort von den im Originalgehäuse vorhandenen Gehäuse-Lichtleitern bis nach außen sichtbar gemacht.

3 Die aktuelle Version ist „VN330SP-E“ ist z.B. bei Mouser lieferbar, bei ADC-Bestückung sind jedoch nur 5 Powerswitches nö5g.

4 Prototyp-4 V(2.8) und die Finale Version (V2.9) nutzen oben eine 4-Lagen-Multlayer-Pla5ne, unten 2-Layer.

myT40-PLC C.Niesen CC-BY-NC-SA 2026 | 3

Die Hardware

Die Bestückung basiert zu großen Teilen auf SMD-Bauteilen. Daher ist ein HeißluUlötgerät und die Verwendung von Lötpaste mit No-Clean und geringer Schmelztemperatur unerlässlich, denn es werden sowohl Pads ohne „*_Handsoldering“ genutzt, als auch einige Bauteile in „0805“-Größe. Ab V2.5 kommen noch „0603“-er Serienwiderstände treibersei5g auf den SPI-Leitungen und Entkoppelkondensatoren dazu. Wo es noch möglich oder sinnvoll ist, werden bedrahtete Elemente verbaut und ICs gesockelt. Da beide Pla5nenseiten mit SMD-Bauteilen bestückt sind, muss man sich entscheiden, welche Seite man im ReRow-Ofen „backen“ möchte.

Weil strickt auf Poten5altrennung geachtet wird, stellt die untere Pla5ne (UP) insgesamt 7, teils von einander isolierte Spannungspoten5ale bereit.

Weitere vier Poten5ale sind die je Eingangs- und Ausgangsbyte getrennten 0V und 24V Poten5ale, deren Quellen von außen zugeführt werden, sowie die separate 24V Versorgungsspannung der Steuerung für CPU und Interfaces. In der Regel werden deren GND(D)...-Poten5ale außerhalb der SPS an einem einzelnen Sternpunkt zusammengeführt, aber getrennte Verwendung ist ebenfalls möglich, solange die Poten5aldi@erenz zu den Leiterbahnabständen passt (i.d.R. <50V).

Verbaut man die Pla5nen (OP-PFS + UP) in einem alterna5ven Gehäuse, kann die Verbindung für die Ausgänge zwischen den Pla5nen auch enSallen. Die Unterpla5ne hält dafür im gleichen Raster und Abstand Bohrungen und Lötpads für vergleichbare winkelige Terminals bereit. In diesem Fall kann auf der Oberpla5ne das Terminal für Out-Byte-1 enSallen, auf dem Terminal von Out-Byte-0 liegen dann nur noch die Signale für ADC und DAC mit eigenem GNDA als Bezugspoten5al an.

Mehr zu den Varianten im Kapitel 8.1 ab Seite 44.

Die Oberpla5ne in der Variante PFS (OP-PFS) stellt einen 2x4 RM2.54mm Pfostenstecker sta% des 6-poligen FFC in der Oberpla5nenvariante (OP-FFC) für das Originalgehäuse bereit, und bietet damit zusätzlich beide SW_MODE_x - Eingänge gleichzei5g auf Low setzen zu können. Gegenüber dem Originalgehäuse kann man dann damit eine Betriebsart mehr kodieren.

Die Planung des Layouts und der Bauteilanordnung auf den Pla5nen wird durch meine private Verwendung von „Originalgehäusen“ vorgegeben und schlägt sich daher 1:1 in der zweiten Variante mit Pfostenstecker (PFS) für J3 nieder, in welcher ein paar Bauteile um J3 herum anders geroutet werden.

Daher sitzen alle LEDs, die DIN-Buchsen, die Terminals, der Erweiterungsheader, die PE-Fahnen, die Analog-Sollwert-Po5s und der op5onale RS485-Busabschluss genau an den durch das Originalgehäuse vorgegebenen Stellen.

Man kann beliebige Blöcke unbestückt lassen, wie entweder CAN-Bus-1/-2 oder RS485, DAC und ADC, alles nebst zugehöriger Versorgungsspannungserzeugung, den Erweiterungsheader, sogar die DIN-Buchsen, die bei einem beliebigen Gehäuse nur noch als Lötstelle für Kabel auf Sub-D-Buchsen dienen mögen. Wer den Kaltstart, Watchdog, WD-Delay oder die Reset-erzeugenden Spannungsüberwachungen nicht mag, kann auch diese unbestückt lassen. Die SoUware dahinter ist in jedem Fall individuell.

Und wer meint, ohne die aufwändigen Eingangsschutzbeschaltungen auskommen zu können, kann auch hier sparen.
SW_MODE_1/2 ermöglicht per SoUware die De4ni5on verschiedenen Verhaltens beim Booten (z.B. OTA-Update) und nach Anlaufen der Steuerung die Umschaltung auf Kalt/Warmstart bei RESET (manuell oder per SoUware).
Die Hardware unterscheidet hier im Betrieb zwischen Warm- und Kalt-Start, siehe Kapitel 4.1.5.

### 4 myT40-PLC C.Niesen CC-BY-NC-SA 2026

myT40-PLC Documenta5on

### 3.2 Poten1ale

Die benö5gten Poten5ale bei Vollausbau sind folgende:

- Versorgungsspannung Steuerung 24V, 0V, PE, 100mA-180mA
- daraus direkt erzeugt:
- 5V, 0V GNDD für das CPU-Modul Teensy 4.0
- und daraus
- 3.3V, 0V GNDD für Interface-Ansteuerung mit Spannungsüberwachung
- daraus jeweils galvanisch getrennt erzeugt:
- | 5V und 0V_RS485 | für RS485-Bus
- | 5V und 0V_CAN | für CAN-Bus 1 und 2
- | 15V und 0V_GNDA | für Analog-Sek5on, ADC und DAC
- daraus erzeugt
- | 3,3V und 0V_GNDA | für DAC und ADC Converter
- | 2,5V und 0V_GNDA | Referenz-Spannung DAC und ADC
- 0..10V am DAC-Ausgang
- Eingangspoten5al Eingangsbyte-0 mit 24V, 0V
- Eingangspoten5al Eingangsbyte-1 mit 24V, 0V
- Ausgangspoten5al Ausgangsbyte-0 mit 24V, 0V, maximal 5..8*500mA
- Ausgangspoten5al Ausgangsbyte-1 mit 24V, 0V, maximal 8*500mA

Die Versorgungsspannung der CPU wird direkt aus 24V an den Versorgungsspannungs-Anschlussklemmen J9 der PLC ohne galvanische Trennung erzeugt. Daher sollte zum Erhalt der Reinheit der Versorgungsspannung der CPU ein gutes (lineares), eigenes 24V/0,5..1A Netzteil verwendet werden, 0V-PLC (GNDD) kann bei Bedarf mit 0V der Eingänge und 0V der Ausgänge auf gleiches Poten5al an einem gemeinsamen Sternpunkt (!) außerhalb der SPS bei den Spannungsquellen zusammengeführt werden. Der gemeinsame Sternpunkt dient der Minimierung von Störsignalen. An diesem Sternpunkt wird VDE-konform auch zentral der PE angeschlossen.

Am Versorgungsspannungs-Eingang J9 der Steuerung 4ltert eine Drossel L1 höherfrequente Anteile, und Varistoren RN1-3 bieten Schutz gegen Transienten.

Bei Anschluss nicht-ohmscher Lasten an den Ausgängen, müssen deren Spannungs- und Stromspitzen zusätzlich durch Freilaufdioden, RC-Glieder oder Varistoren, direkt am jeweiligen Verbraucher eliminiert werden, u.a. auch zur Vermeidung von Störübertragung auf parallel verlaufender Verkabelung.

Für die Leistungsseite ist ein maximaler Ausgangstrom von 500mA je Ausgang wie beim Original möglich. Aus Sicherheitsgründen sollte dieses zweite Netzteil Kurzschluss- und Überlast-sicher ausgelegt sein. Dieses Netzteil versorgt sowohl die Eingänge, als auch die Ausgänge.

Die Aus- und Eingänge sind gegen Verpolung der Versorgungs- bzw. Eingangsspannungen geschützt.

Bei gemeinsamer Speisung sind die 0V-Anschlüsse der beiden Ausgangs- und Eingangs-Bytes zusammenzuschalten. Das kann auch intern durch eine Kabel-Brücke mit 1,5mm² realisiert werden. Sofern keine ADC/DAC-Op5on verbaut ist, emp4ehlt sich eine externe Brücke.

Die Möglichkeit der internen Poten5altrennung der beiden Ausgangsbytes für 0V und 24V geht in jedem Fall verloren, wenn auf dem Terminal des ersten Ausgangsbytes (Byte-0) op5onal die Eingänge des ADC, und/oder die Ausgänge des DAC bestückt werden. In diesem Fall stehen maximal drei Ausgänge, Bit-5 bis
-Bit7 | und | der | 0V/24V | Speise-Eingang | für | die | Schaltausgänge | nicht | zur | Verfügung.
myT40-PLC C.Niesen CC-BY-NC-SA 2026 | 5

Die Hardware

Am Anschluss „0.5/0.6“ be4nden sich „U0/U1“ (ADC), für den DAC belegt „U10“ den „0.7“, „U11“ liegt auf „0V“ und auf „24V“ ist mit dem analogen Ground GNDA belegt.

„0V“ und „24V“ für Ausgangs-Byte-0 Bits0..5 müssen somit intern auf UP gebrückt werden.

Details dazu im Kapitel 8.1.2 „5+8 Ausgänge, 2x8 Eingänge, mit ADC , mit DAC“ auf Seite 45.

Op5onal lassen sich in diesem Fall die LED der nicht nutzbaren Ausgänge Bit-5 bis Bit-7 als separate Statusanzeigen nutzen, idealerweise durch eine andere LED-Farbe, wie orange sta% rot.

Details dazu, wie die Anpassung der Bestückung, im Anhang 9.1 Op5onale Nutzung von Q0.5, Q0.6 und Q0.7 als Status-LED auf Seite 49.

Ich habe auf rote LED zurückgegri@en, weil diese mit nur 2mA oder 3mA immer noch intensiv leuchten aber deutlich weniger Strom verbrauchen. Werden hier Änderungen vorgenommen, muss das Eingangs-Netzwerk zwingend neu berechnet werden, siehe Kapitel 9.8.

### 3.3 Abkürzungen

Hier eine Liste häu4g verwendeter Abkürzungen.

OP | Obere Pla5ne
UP | Untere Pla5ne
FFC | Oberpla5ne mit J3 als FFC-Anschluss, gedacht für den Einbau in Originalgehäuse. Version 3.3 M44 mit Originaler Posi5on RS485 und Watchdog mit Start-Delay
PFS | Oberpla5ne mit J3 in Version mit Pfostenstecker,gedacht für Nachbauten in beliebigen Gehäusen. Version 3.3 M44 mit Originaler Posi5on RS485 und Watchdog mit Start-Delay
Mnn | nn mit zweistelliger Zahl, fasst die Veränderungen der jeweiligen Entwicklungsphasen von Prototyp zu Prototyp zusammen.
TOP | Engl. Kennzeichnung auf jeder Pla5ne für „Oberseite“ für Pla5nen-Hersteller
BOT | Engl. Kennzeichnung auf jeder Pla5ne für „Unterseite“ für Pla5nen-Hersteller

### 6 myT40-PLC C.Niesen CC-BY-NC-SA 2026

myT40-PLC Documenta5on

## 4 Die Hardware - AuBau der Oberpla1ne (OP)

### 4.1 Komponenten der oberen Pla1ne „OP“

Die obere Pla5ne „OP“, trägt die Komponenten der CPU, die Terminals, das Netzwerk der digitalen Eingänge, die Interfaces und ihre Bausteine, sowie den ADC mit 4 Kanälen und den externen Watchdog und Delay. Seit Version-4 (M38) ist die Oberpla5ne ist eine Mul5-Layer-Pla5ne mit 4 Layern.

### 4.1.1 CPU

Das CPU-Modul ist ein Teensy 4.0. Es ist ausreichend Speicher vorhanden, ebenso alle denkbaren Interfaces, wie 2*SPI, I2C, 3*CAN, 5*RX/TX, analoge und digitale Pins. Um es vorwegzunehmen: Mein Entwurf nutzt kein PWM, da alle PLC-Aus-/Eingänge an einem Mul5plexer per SPI-Bus hängen.

Ein o@ensichtlich weiterer Nachteil sei nicht verschwiegen: einen Standard-Teensy 4.0 kann man nicht hardware-debuggen. Das erschwert die Entwicklung einer passenden SoUware. Da es bislang keine Alterna5ve gibt, die so kompakt und leistungsfähig ist, wird dieser Nachteil in Kauf genommen.

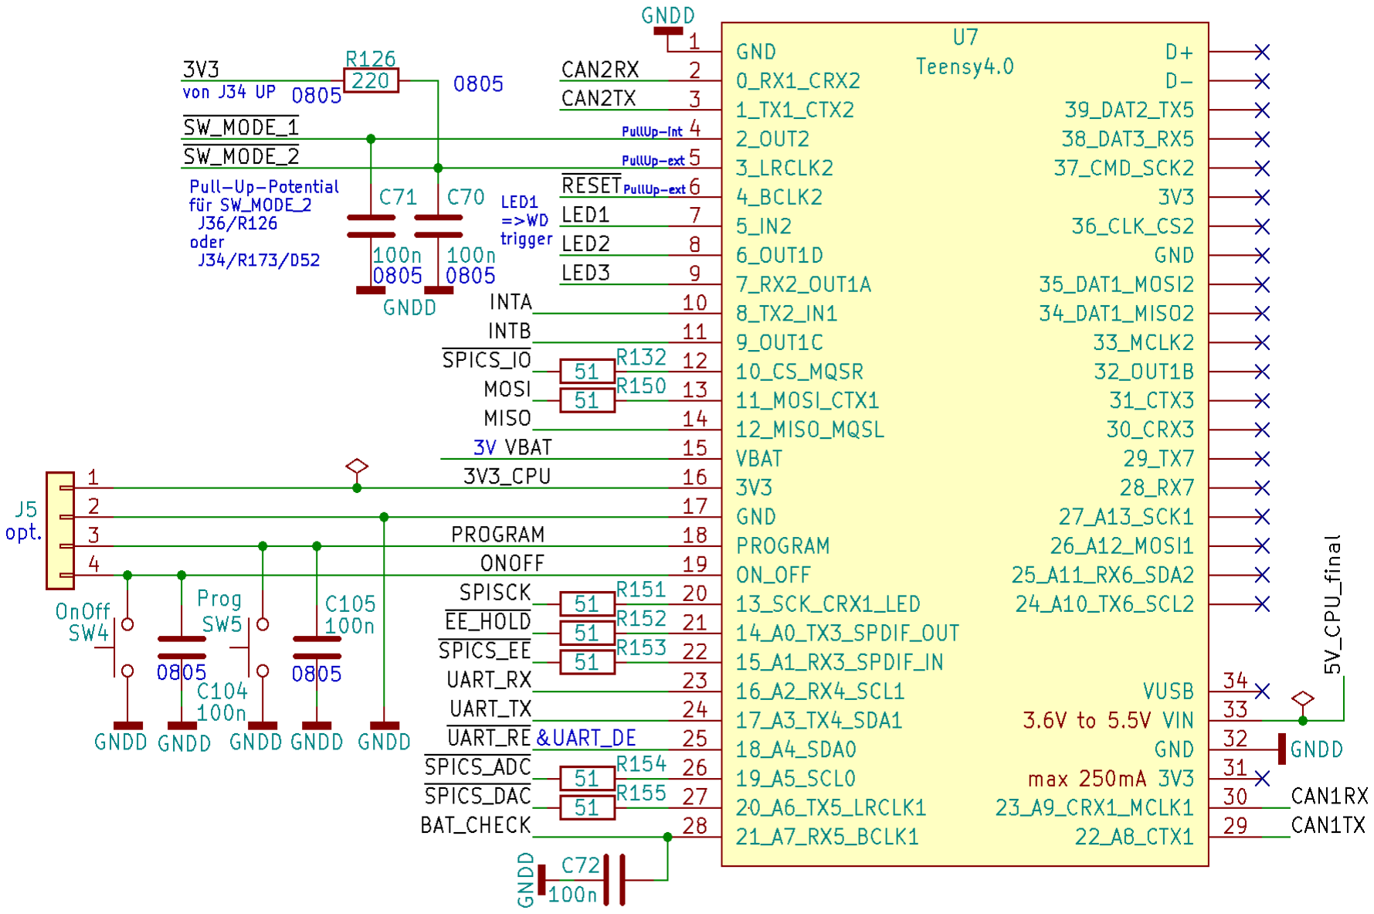
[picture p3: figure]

Das CPU-Modul besitzt eine eigene, abschaltbare 5V Versorgung (5V_CPU_4nal), die sich mit der separaten 3,3V (3V3_INT) für alle Peripheriebausteine den gemeinsamen Ground GNDD teilt.

Ab V2.5 sind die Serienwiderstände von 51Ω, Baugröße 0603, in allen SPI- und Select-Leitungen, jeweils auf der Treiberseite, hinzugekommen. Damit bleibt das Rechtecksignal beim Empfänger etwas sauberer, d.h. freier von Oberwellen. Das Internet gibt AuskunU mit: „Wie hoch muss der SPI-Leiterbahn-Widerstandswert sein?“ Oder: „Gibt es eine Anforderung für den SPI-Leiterbahn-Widerstandswert?“. Damit diese leichter gegen einen anderen Wert getauscht werden können, sind die meisten gut zugänglich eingebaut.

myT40-PLC C.Niesen CC-BY-NC-SA 2026 | 7

Abbildung 1: CPU mit allen Signalen

Die Hardware - Au&au der Oberpla5ne (OP)

Das CPU-Modul wertet auch die Stellung des Betriebsmodus-Schalters des Originalgehäuses an J3 in FFC-Variante aus : SW_MODE_2 /_1 = „0|1“, „1|1“, „1|0“ (Posi5onen: Oben, Mi%e, Unten). In einem Alterna5vgehäuse mit 8-poligem Pfostenstecker J3 (Variante „PFS“) ist auch die Kombina5on „0| 0“ z.B. per Jumper möglich (beide SW_MODE_X per Jumper auf Low, s.u.).

Der RESET-Taster ist im Originalgehäuse ebenfalls angeschlossen. Normalerweise als Eingang am CPU-Modul mit Interrupterkennung geschaltet, kann der zugehörige CPU-PIN per SoUware auch als ak5ver Ausgang einen RESET für die Interfacebausteine erzeugen, ein externer Pull-Up (R50 auf UP) zieht ihn gegen 3.3V (3V3). Daher muss der an der Reset-Leitung liegende Reset-Generator in der Variante ADM-803x mit open collector verwendet werden. Das ermöglicht einen durch SoUware ini5ierten Warm-/Kaltstart.

R126 ist rela5v klein für einen PullUp Widerstand. Benö5gt wird ein Minimalpegel von 2.1V für „High“ an SW_MODE_2 in der Kaltstart-Phase. Ein interner rela&v niedriger Widerstand am Teensy-Pin macht externe 220 Ohm nö&g. Warum der interne Widerstand so gering ist, ist noch unklar. Der Pin ist mit „INPUT“ ini5alisiert.

Erst wenn die CPU gebootet hat und das Setup den Eingang 4 (Pin-6) auf internen Pull-Up kon4guriert, liegt hier ein de4nierter Pegel an. Die Kaltstartlogik kann jedoch die 5V für die CPU unterbrechen. Daher muss SW_MODE_2 zwingend mit einem externen Pull-Up >= 2.1V erreichen können. Zum Kaltstart siehe auch Kapitel 4.1.5.

Ab M42 wird auch die 3V3 Spannung vor Q2 auf der OP über J36 zur Verfügung gestellt. Diese 3,3V (3V3) sind als Pull-Up auf SW_MODE_2 nö5g, damit die Kaltstartlogik beim Booten nicht in einer Endlosschleife verharrt.

Seit Version-5 versorgt J36 mit 3V3 auch den HW-Watchdog nebst Delay auf der OP. Mit V5 ist die Spannungsüberwachung U40 für 3V3 auf die Oberpla5ne verschoben worden.

### 4.1.2 Teensy 4.0 USB Spannungsversorgung unterbrechen

Nach einer ersten Test-Programmierung eines frischen Teensy 4.0 muss die Versorgungsspannungsbrücke auf der Teensy-Pla)ne zwischen VIN und VUSB vor Anlöten der Pin-Header und vor dem Einsetzen in die Schaltung unterbrochen werden. Andernfalls speist die USB-Verbindung vom programmierenden Rechner den Teensy in der Schaltung. Das hat mindestens den unerwünschten E@ekt eines nicht funk5onierenden Kaltstarts. Sicherheitshalber sollte vor dem Cut der Teensy einmal zur Probe programmiert werden. Die Teensy-Dokumenta5on gibt dazu detailliert Hinweise.

Anmerkung: Solange die Speisung der CPU durch den USB-Anschluss gewährleistet bleibt, können die drei Status-LED (4.1.8) auch dann genutzt werden, wenn keine Versorgungsspannung an J9 angeschlossen ist.

Verzichtet man auf den Kaltstart und überbrückt Q1 und Q2, stehen auch die 3,3V als „3V3“ dauerhaU für die Interfaces bereit.

Wie dem auch sei, es wird empfohlen, diese Verbindung aufzutrennen.

### 8 myT40-PLC C.Niesen CC-BY-NC-SA 2026

myT40-PLC Documenta5on

### 4.1.3 Pin-Header J3 an CPU in FFC-Variante für Originalgehäuse

Wird die CPU mit 3V aus einer 3,6V Lithium Ba%erie gepu@ert, muss deren Spannung mit D33 (1N4448 SMD oder 1N4007 SMD) um 0,6V auf 3V reduziert werden. Sie dient auch zum Schutz vor Verpolung.

Mit Ba%erie ist der dauerhaUe Betrieb der Real-Time-Clock des Teensy4.0 (RTC) gewährleistet. R51 (680k) begrenzt den Teensy-Stromhunger am A7-Eingang (BAT_CHK) und R123 (680k) sorgt für de4nierten Pegel ohne Ba%erie. D33 reduziert die 3V6 auf zulässige 3V und bietet gleich noch einen Verpolungsschutz. Diese Lösung wurde gewählt, weil das Originalgehäuse einen von außen zugänglichen Slot für 3,6V-Lötdraht-Li5um-Ba%erien besitzt.

Die Nutzung von SW4 OnOP setzt den Einsatz einer Ba%erie voraus.

J5 ist op5onal an der Unterseite der OP und führt die Teensy spezi4schen Signale “Programm” und “OnO@”, sowie 3,3V und 0V GNDD heraus. Siehe Kapitel 9.7. Ab M42 (V5) werden die Signale für Prog und OnOP an den Pla5nenrand geführt und erlauben die Bestückung mit horizontalen Tastern SW4 und SW5. Dafür benö5gt das (Original-) Gehäuse entsprechende Ö@nungen.

* C1 ha%e ursprünglich 100µF/6V3 und sorgte damit in der Kaltstartphase für einen kurzzei5gen Einbruch der Versorgungsspannung, welcher von der Spannungsüberwachung U40 für die 3.3V-Schiene auf der UP mit einem RESET quihert wurde. Das führte in eine Endloschleife von Restarts. Daher wird C1 derzeit nicht bestückt, nur falls erforderlich mit einem sehr niedrigen Wert von evt. 1µF.

Aus dem gleichen Grund wurde eine separate 5V-Spannungsüberwachung enSernt, die verbliebene U40 auf der OP reicht aus, da die 3V3 aus den 5V erzeugt werden.

J36 (OP), auf UP mit J34 verbunden, liefert 3V3 vor Q2 an die OP, damit SW_MODE_2 auch in der Kaltstart-Phase einen validen Pull-Up erhält. Zudem wird der Hardwarewatchdog und sein Delay-Timer mit diesen 3V3 betrieben.

myT40-PLC C.Niesen CC-BY-NC-SA 2026 | 9

Abbildung 2: Variante FFC für das Originalgehäuse

Die Hardware - Au&au der Oberpla5ne (OP)

### 4.1.4 Pin-Header J3 an CPU in Variante PFS für beliebige Gehäuse

Für J3 gibt es die Oberpla5ne (OP) in einer Variante mit einem 2x4 Pin-Header RM2,54 für Pfostenstecker. Diese Variante ist zur freien Verwendung in beliebigen Gehäusen gedacht.

Bei dieser Verwendung lassen sich alle 16 Ausgänge, sowie alle ADC-Eingänge und alle DAC-Ausgänge nutzen. Ein für diesen Fall verwendetes Gehäuse stellt entweder zusätzliche Terminals für die analogen Signale bereit, oder nutzt die Einbaumöglichkeit der Ausgangsterminals direkt auf der Unterpla5ne. Hier
kann | auch | die | Diode | D33 | enSallen, | eine | 3V | Knopfzelle | verwendet | wird.
Mit dem EnSall von D33 enSällt aber auch der Verpolungs-Schutz. Es emp4ehlt sich eine Diode mit geringem Uf, bzw. Spannungsabfall in Durchlassrichtung, zu verwenden.

In dieser Variante können außerdem alle vier Kombina5onen der SW_Mode_1/2 in der SoUware genutzt werden.

Mit der Bestückung von Terminals für die Ausgänge auf der unteren Pla5ne UP kann das Ausgangsterminal „Byte-0“ auf der OP seine Anschlüsse für ADC/DAC bereitstellen, während das Terminal für Byte-1 auf der oberen Pla5ne (OP) ganz enSallen kann. Siehe Varianten im Kapitel 8.2 , Seite 46.

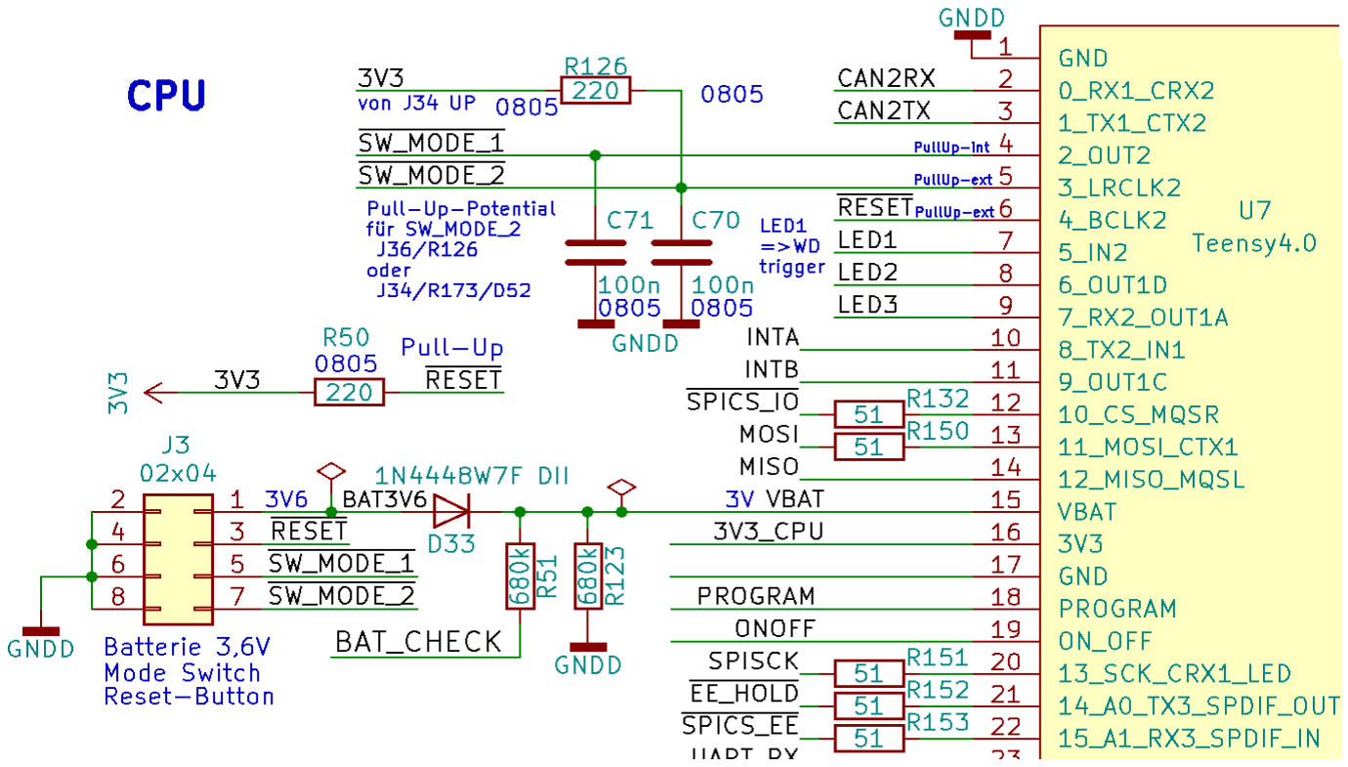
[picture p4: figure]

Allgemein gilt: SW_MODE_1 wird per SoUwarekon4gura5on des Pins 4 (2_Out2) des Teensy4.0-Moduls auf Pull-Up-intern eingestellt. SW_MODE_2 muss dagegen auf Pull-Up-extern eingestellt werden, weil an dieser Leitung auch die Kaltstart-Logik hängt, die mit SW_MODE_2=Low ak5viert und bei zusätzlichen RESET=Low ausgelöst wird. Eine Kon4gura5on des Teensy 4.0 Pins 5 (3_LRCLK2) als Ausgang mit internem Pull-Up ist nicht möglich, weil die Kon4gura5on per SoUware erst nach dem Booten beginnt. Liegt nicht wenigstens eine Leitung von beiden auf High, bleibt die CPU ohne Versorgungsspannung.

Per SoUware lässt sich ein Kaltstart auslösen, wenn SW_MODE_2 Low ist und der RESET-Eingang, normalerweise als Interrupt-Eingang kon4guriert, temporär als Ausgang mit „OUTPUT_OPENDRAIN“ geschaltet und auf Low gesetzt wird. Der zugehörige Pull-Up R50 sitzt seit V5 auf der OP. Ein manueller Kaltstart wird per RESET-Bu%on an J3 ausgelöst. Mit SW_MODE_2=High ist ein soUwaresei5ger Warmstart

### 10 myT40-PLC C.Niesen CC-BY-NC-SA 2026

Abbildung 3: Die Variante OP-PFS mit Pfostenstecker 2x4 Pin-Header für J3, einige Bauteile hier nicht dargestellt.

myT40-PLC Documenta5on

per Interrupt realisierbar. Mit jedem RESET=Low werden auch die Interface-Bausteine zurückgesetzt und müssen neu ini5alisiert werden, insbesondere bei Warmstart. Der Kaltstart bootet komple% neu.

### 4.1.5 Reset und Kaltstart

Für myT40 wurde eine Kaltstartop5on vorgesehen, die manuell, bei Spannungsüberwachungsfehlern, durch den externen HW-Watchdog (s.u.) oder per SoUware, in Abhängigkeit von SW_MODE_2, durch einen RESET ausgelöst werden kann.

Die 3,3V der Interfacebausteine, erzeugt aus der 5V-Versorgungsspannung der CPU, wird von einem Reset-Generator ADM-803R (U40) auf OP überwacht. Er zieht die Reset-Leitung auf Low, setzt damit die Peripherie zurück und signalisiert der CPU per Interrupt diesen Umstand, falls diese noch reagieren kann. Mit dem RESET werden die Ein- und Ausgangs-Bausteine auf Standard-Input gesetzt.

Der Kaltstart

Das Gate von Q1 liegt per Pull-Up R124 auf Source-Poten5al, somit sperrt der P-Kanal-MOSFET. Nach Anlegen der Versorgungsspannung liegt der Ausgang Q des NE555 (U50) auf Low. Q1 leitet und die CPU bootet. U40 (UP) hält seinen RESET-Ausgang für 240ms auf Low.

In die Kaltstart-Logik greiU der Mode-Switch_2 (z.B. Originalgehäuse) ein. In Posi5on-1 ist SW_MODE_1=Low, in Posi5on-2 beide High, in Posi5on-3 ist SW_MODE_2=Low.

Der Kaltstart wird bei RESET=Low ausgelöst, wenn SW_MODE_2 ebenfalls Low ist. Das OR-Ga%er U49 legt dann seinen Ausgang auf Low und triggert (TR) damit U50 (NE555), der im monostabilen Modus läuU. Der Ausgang von U50 Ausgang, normalerweise Low, wird für R133*C76=T=2,5sec High. Q1 trennt damit die CPU von ihrer 5V-Versorgungsspannung und mit Q2 die Peripherie von 3,3Vint. Solange der Trigger-Eingang TR von U50 Low ist, bleibt der Ausgang Q von U50 High. Wenn der Eingang TR wieder High ist, läuU noch die Zeit T ab. Danach schaltet U50 den Ausgang Q wieder Low, Q1 leitet wieder und die CPU bootet neu und die Peripherie wird mit 3,3Vint versorgt. Dem Reset unterliegen auch die Interfacebausteine für Ein- und Ausgänge. Bei einem Reset werden alle Ausgänge abgeschaltet, die MCP23S17 werden auf Standard-Input kon4guriert. Ist die 3,3Vint aus der 5V-Versorgungsspannung zu niedrig hält U40 den RESET aufrecht, im SW_Mode_2=Low bootet die CPU dann nicht mehr, solange das Problem mit der Versorgungsspannung besteht. Für andere Kombina5onen von SW_MODE_X muss RESET per SoUware im Setup auf Low geprüU werden (Warmstart).

Per SoUware lässt sich der RESET-Eingang der CPU Input-4 (Pin-6) temporär als Ausgang im Modus openCollector auf Low schalten und ein Kaltstart auf SW_MODE_2 per Programm erzwingen, oder Warmstart bei anderen Modi, je nach SoUware.

myT40-PLC C.Niesen CC-BY-NC-SA 2026 | 11

Abbildung 4: Schaltung für den Kaltstart

Die Hardware - Au&au der Oberpla5ne (OP)

Für das OR-Gate U49 ist unbedingt die Level-ShiU-Variante auf 5V zu wählen, da die High-Pegel von RESET und SW_MODE_2 bei etwa 2,1V liegen (3,3V Betriebsspannung CPU).

Im Testbetrieb von V3 wurde deutlich, dass neben der Abschaltung der CPU-Spannung zusätzlich auch die 3,3V Interface-Versorgungsspannung mit Q2 auf der UP abgeschaltet werden muss, sonst wird der Teensy4.0 nicht vollständig spannungsfrei geschaltet.

Die Kombina5on D50 und R128 können enSallen, wenn der externe HW-Watchdog U48, s.u., nicht bestückt wird. D50 muss dann durch einen Null-Ohm-Widerstand bzw. Brücke ersetzt werden.

### 4.1.6 Hardware Watchdog

Der externe Watchdog ist notwendig, weil die SoUware in manchen Fehlerfällen den Teensy4.0 in den Bootmodus versetzt. Der Teensy4.0-interne HW- , oder auch der SW-Watchdog, funk5oniert dann nicht mehr.

Im Rahmen der Anpassungen von Prototyp V4 auf die 4nale Version V5 wurden viele Signale vom TOP-Layer der OP auf den IN1-Layer verlegt. Der gewonnene Platz auf der OP wird nun von den Bauteilen des externen Hardware-Watchdogs U48 genutzt. Verwendet wird ein TPS3431, dessen WDO-Pin als Stromsenke mit Open-Collector (OC) ausgeprägt ist. Daher wird R128 als Pull-Up in die nun geteilte Triggerleitung für den NE555 eingefügt. Weil U49 über einen Push-Pull-Ausgang verfügt, muss dieser OCkompa5bel umgestaltet werden. D50 trennt den Push-Anteil der 5V vom U49-Ausgang für den Trigger-Eingang des NE555 ab und simuliert so einen OC-Ausgang für U49. Der TPS3431 wird dagegen mit 3,3V über J36 versorgt, weil das WDI-Signal direkt von der CPU kommt (LED1).

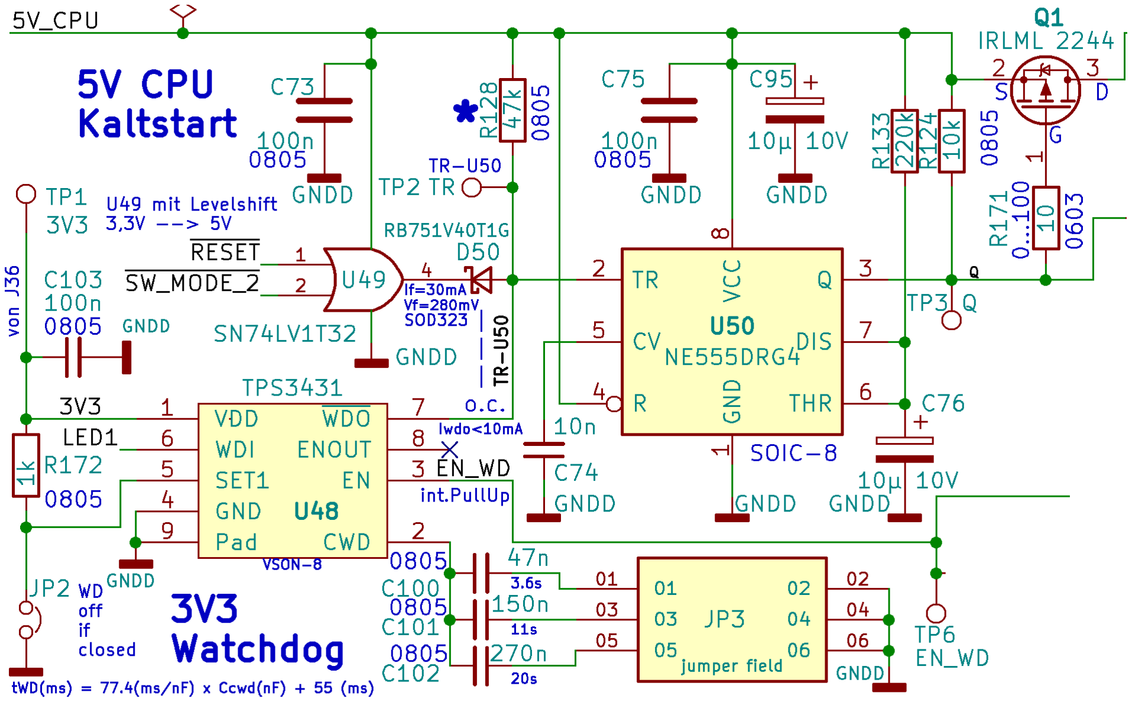
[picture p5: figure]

Der Ausgang WDO kann einen Strom von maximal 10mA aufnehmen.

Der HW-Watchdog wird bei o@enem Jumper JP2 ak5viert. Seine Timeouts lassen sich per JP3 auf 3.6 sec, 11sec, 20sec oder Summen davon einstellen. Bleiben alle Jumper o@en, greiU ein Timeout von 1600ms. C100, C101, C102 bes5mmen mit JP3 den Timeout.

### 12 myT40-PLC C.Niesen CC-BY-NC-SA 2026

Abbildung 5: Kaltstart mit Hardware Watchdog (PFS M43)

myT40-PLC Documenta5on

Der CPU-Ausgang zur Ansteuerung von LED1 ist als Heartbeat fest verdrahtet. Er stellt das periodische Timer-Reset-Signal für den HW-Watchdog am Pin WDI bereit. Bleibt die periodische, fallende Flanke aus, wird mi%els NE555 ein Kaltstart ausgelöst, unabhängig von SW_MODE_2 oder RESET.

Hier noch einmal zur Verdeutlichung das Prinzip-Schaltbild der Komponenten für den Kaltstart und die RESET-Logik:

Alle weiteren notwendigen Bauteile sind der Übersichtlichkeit wegen weggelassen. Die einzelnen Komponenten verteilen sich auf der OP und UP. Bei inak5vem MonoRop des NE555 (U50) sorgt ein Q=Low an den Gates für leitende Q1 und Q2.

Ist der NE555-Ausgang Q=High, stehen an den beiden Gates von Q1 und Q2 +5V an, die Gates sind gegenüber ihren Source-Anschlüssen nicht mehr nega5v, beide sperren und schalten CPU und Interfaces ab.
Sollte die Versorgungsspannung 3V3 wider Erwarten unter 2,93V fallen, wird TR-U50 durch U40 ausgelöst und die Versorgungsspannung für CPU und Interfaces abgeschaltet. In der Versionen V3 und V4 zog U40 RESET auf Low, was sich als nicht prak5kabel herausgestellt hat.
myT40-PLC C.Niesen CC-BY-NC-SA 2026 | 13

Abbildung 6: Prinzipschaltbild Kaltstart, Reset-Logik und Hardware-Watchdog mit Delay (ab V5 M43)

Die Hardware - Au&au der Oberpla5ne (OP)

### 4.1.7 Hardware Watchdog-Delay

Im Unterschied zu V4 ist die Version V5 mit M44 um einen Delay bei Startup erweitert. Ein S-80929CNMC (U52) prüU die Versorgungsspannung von 3V3_INT (Q2 leitet) und startet nach Überschreiten von 2,9V ein internes Zeitglied (Tdelay=5,7ms/nF*C[nF]), de4niert von C106. Nach Ablauf der durch C106 de4nierten Zeit schaltet der Ausgang OUT von U52 auf High und gibt über den EN-Eingang den WatchDog U48 frei.

Mit C106=2µ2 wird der Watchdog bei einem Kaltstart erst nach 12sec ak5viert. Die Delay-Time entspricht ungefähr 5,7msec je nF für C106. Nach dieser Zeit geht der Reset-Ausgang von U52 auf High und steuert den EN-Eingang des Watchdog U48 an und schaltet diesen frei. U52 wird durch 3V3int versorgt und angesteuert und damit ist bei jedem Kaltstart ein Delay garan5ert. Bei einem Warmstart läuU auch der Watchdog ohne Delay durch.

R176 als Pull-Up für EN_WD ist op5onal, da U48 einen internen Pull-Up an EN besitzt.

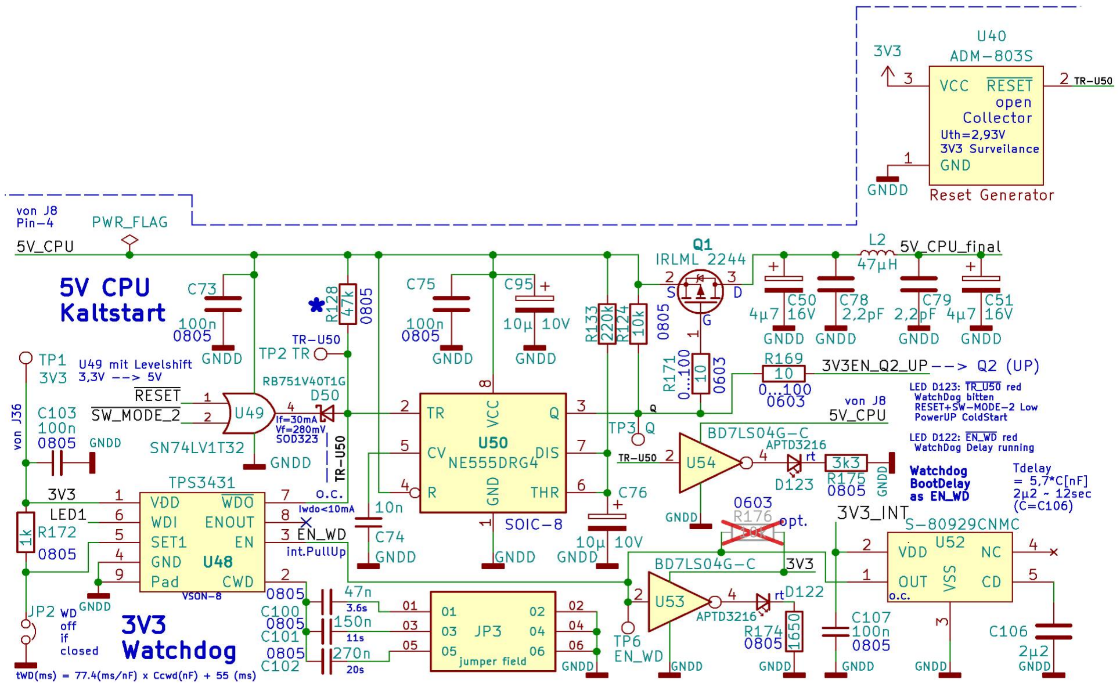
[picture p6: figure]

LED D123 zeigt den vorhandenen Trigger (TR_50=Low) für NE555 (U50) in rot an. Solange die LED leuchtet sind die Versorgungsspannungen der CPU und der Interfaces abgeschaltet.

LED D122 zeigt einen nicht vorhandenen EN_WD in rot an. Solange die LED leuchtet ist der Watchdog gesperrt und WDO ist hochohmig, und durch den Pull-Up R128 High, solange U49 nicht Low (RESET=Low bei SW_MODE_2=Low) ist.

C106 sollte einen geringen Leckstrom haben, da er von U52 mit 100nA geladen wird. Elektrolyt-Kondensatoren sind damit ungeeignet.

In Abb.7 sieht man auch U40, der die Spannungsversorgung für CPU und Interfaces vor Q1 und Q2 überwacht und bei Unterschreitung den Trigger von U50 auf Low zieht und damit CPU und Interfaces abschaltet. LED D40 (LED1) zeigt den WDI an, LED D41 (3V3_INT) zeigt vorhandene CPU und Interface-Versorgungsspannung nach Q1 und Q2 an.

### 14 myT40-PLC C.Niesen CC-BY-NC-SA 2026

Abbildung 7: Kaltstart mit Hardware Watchdog und Start-Delay (M43)

myT40-PLC Documenta5on

### 4.1.8 Status LED

Von der CPU werden 3 Status-LEDs angesteuert. LED1, LED2, LED3 sind frei programmierbar.

Allerdings ist zu beachten, dass LED1 das WDI-Signal für den Hardware-Watchdog generieren muss, die fallende Flanke setzt seinen internen Counter zurück. Bleibt die Flanke aus, werden die CPU und alle Interfaces abgeschaltet, sofern JP2 o@en ist (Watchdog U48 ak5viert).

D41 ist dauerhaU mit 3V3int der Betriebsspannung der Interfaces verbunden. Liegt hier Spannung an, ist die CPU auch versorgt (5V_CPU_Final).

### 4.1.9 EEPROM

Das EEPROM 25LC512 im DIL-8 Gehäuse ist gesockelt und ermöglicht einen einfachen Austausch. Andere Speichergrößen oder Flash sind denkbar. Die Kommunika5on erfolgt über den SPI-Bus. Mit JP1 kann ein Schreibschutz ak5viert werden.

HOLD liegt per Pull-Up auf High und muss passend bei Bedarf angesteuert werden.

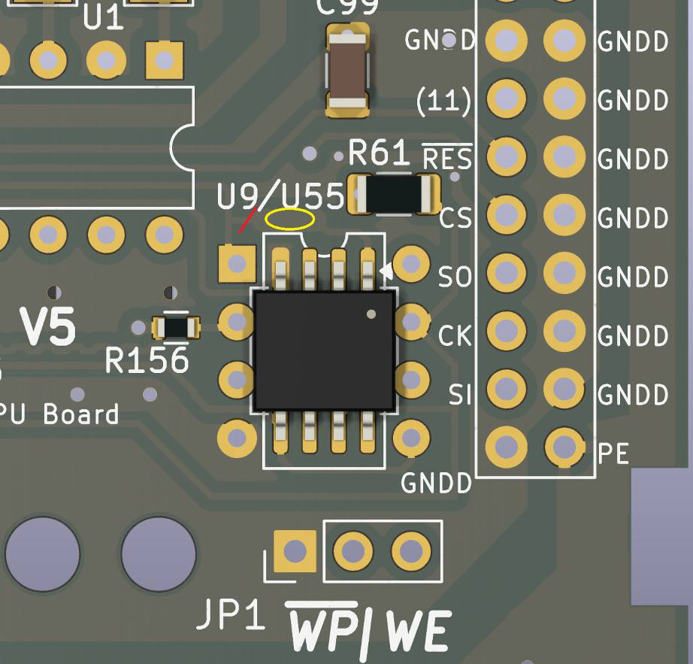
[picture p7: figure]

### 4.1.10 Alterna1ves Gehäuse EEPROM

Sta% eines DIL-8 EEPROM (U9) kann auch eines mit SOIC-8-Gehäuse (U55) verbaut werden. Für U55 muss C108 sta% C9 verwendet werden.

In diesem Format werden ebenfalls F-RAM-Bausteine mit SPI Pin-kompa5bel angeboten.

Wird z.B. ein DAC oder ADC nicht bestückt, kann man unterhalb der „9“ von U9 die Select-Leitung durchtrennen und per Fädeldraht (gelbe Markierung unter „U55“) eine freie Select-Leitung anlöten. Das ermöglicht sowohl ein EEPROM im DIL-8, als auch ein F-RAM oder zweites EEPROM parallel nutzen. JP1 „WP/WE“ ist nur für U9 verwendbar.

myT40-PLC C.Niesen CC-BY-NC-SA 2026 | 15

Abbildung 8: PLC Status LED

Abbildung 9: EEPROM

Abbildung 10: U55: Alterna&ves oder zusätzliches EEPROM oder F-RAM

Die Hardware - Au&au der Oberpla5ne (OP)

### 4.1.11 CAN-Bus und Busverbindungen

Die beiden Schni%stellenbausteine ISO1050DUB gewährleisten Isola5on und sind als DIL-8-SMD aufgelötet und mit HeißluU leicht zu tauschen. Die Terminierung wird über jeweils zuschaltbare Abschlusswiderstände gewährleistet und ist zur Signalverbesserung in einer gespli%eten Variante realisiert.

PE für den Schirm wird auf das Gehäuse der 5-Pol-DIN-Buchsen per 220n/250V geführt. CAN1 ist auf beiden DIN-Buchsen J6 und J7 verfügbar, CAN2 nur auf J6.

JP6 stellt wahlweise GND_CAN oder GND_RS485 an DIN-5-Pin-2 für J7 bereit. J6 ist an Pin-2 immer mit GND_CAN belegt. J28 führt GND_CAN und J37 führt GND_RS485.

Ende 2025 wurde die gesamte Kaltstart-Logik mit Watchdog und Delay auch für den myT41Controller übernommen und gleichzei5g eine Integra5onsmöglichkeit für OTA via HC-05 gescha@en. Damit das gleiche evt. auch für die myT40PLC möglich werden kann, wurde für V5 CAN1 und CAN2 vertauscht, damit CAN2 nicht an beiden DIN-5-Buchsen enSällt. Jetzt steht CAN1 an beiden Buchsen bereit und CAN2 könnte zugunsten einer Ansteuerung eines HC-05-Moduls enSallen, da der CRX2/CTX2 an den gleichen Pins auch RX1/TX1 bereitstellt. Diese Anpassung wurde für beide Varianten FFC und PFS umgesetzt.

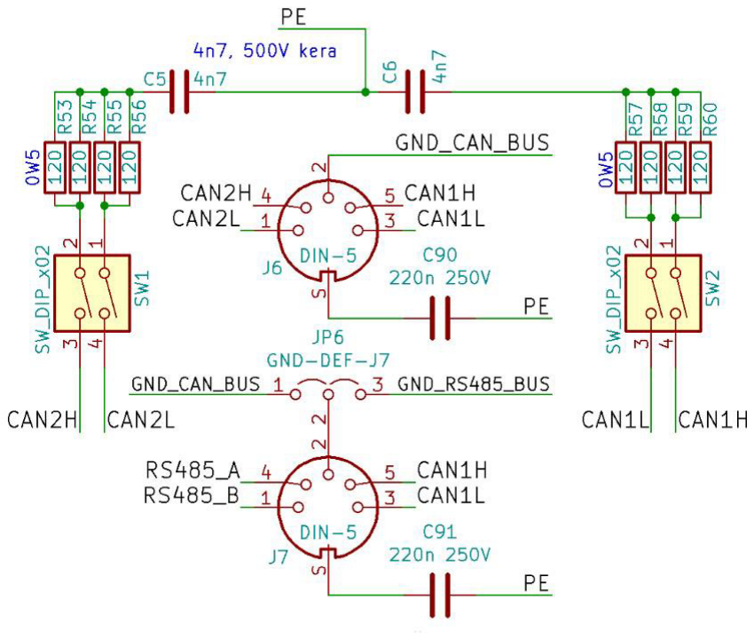
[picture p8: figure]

Dem CAN-Bus wurde Vorrang eingeräumt, weil es zwei Jahre lang keine isolierenden RS485-Bausteine zu kaufen⁵ gab. Zudem unterstützt die CAN-Hardware etwas intelligenter die Kommunika5on. Stehen mehr als zwei zu verbindende Steuerungen zu weit auseinander, kann die mi%lere über den zweiten CAN-Bus als Repeater arbeiten. Der Interface-Baustein für CAN-1 ist auf der Unterseite der OP platziert, der für CAN-2 be4ndet sich auf der Oberseite der OP.

Mit V5 wurde die Belegung für RS485 dem Original angelehnt, was sie Integra5on in meine bestehende Verkabelung vereinfacht. Ground für RS485 oder CAN kann mit JP6 an DIN-Buchse J7-Pin2 per Jumper de4niert werden.

5 Eine Bestellung bei einem namhaUen Distributor von Anfang 2021 war im März 2022 abermals auf August 2023 verschoben worden, im Februar 2023 dann doch schon eingetro@en. Man muss also auch warten können.

### 16 myT40-PLC C.Niesen CC-BY-NC-SA 2026

Abbildung 12: Busabschluss FFC M43

Abbildung 11: ISO CAN Bus

myT40-PLC Documenta5on

### 4.1.12 Verbindungen der Spannungsversorgung von UP zu OP

J8 stellt von der UP kommend die 5V für die
CPU vor der Kaltstartlogik bereit, ebenso
die poten5alfreie Spannung für die beiden
CAN-Busse.
J11 überträgt von der UP die potentalfreie Spannung für den RS485-Bus.
J25 übernimmt von der UP 3V3_INT, von der CPU abgeleitet, für Interfaces und die potentalfreie Spannung für DAC/ADC, sowie deren Referenzspannung 2V5.

J36 (OP) nimmt von J34 (UP) die 5V_CPU und 3.3V entgegen, siehe Kapitel 4.1.3 und 4.1.4.

### 4.1.13 RS485-Bus

Der Schni%stellenbaustein ADM2483xRW gewährleistet Poten5altrennung zwischen RS485-Bus und CPU. Er steht nur als SMD-Baustein zur Verfügung und war leider auf dem Markt lange Zeit nicht verfügbar. Die Terminierung wird über 0,25V-
Sho%ky-Dioden | dauerhaU
realisiert. Die Grundidee dazu ist in
einem Ar5kel beschrieben : “Trim the fat o@ RS-485 designs“, verö@entlicht auf „EE|Times“. Hintergrund ist die Vermeidung dauerhaUer Verlustleistung an den Terminierungs-Widerständen. Die Terminierung mit den Dioden D44-D47 ist dauerhaU auf jedem Busteilnehmer ak5v. Allerdings ist die Foreward Voltage Vf kri5sch, diese sollte so klein wie irgend möglich sein. Für eine BAT46 liegt sie bei sehr niedrigen 0,25V.

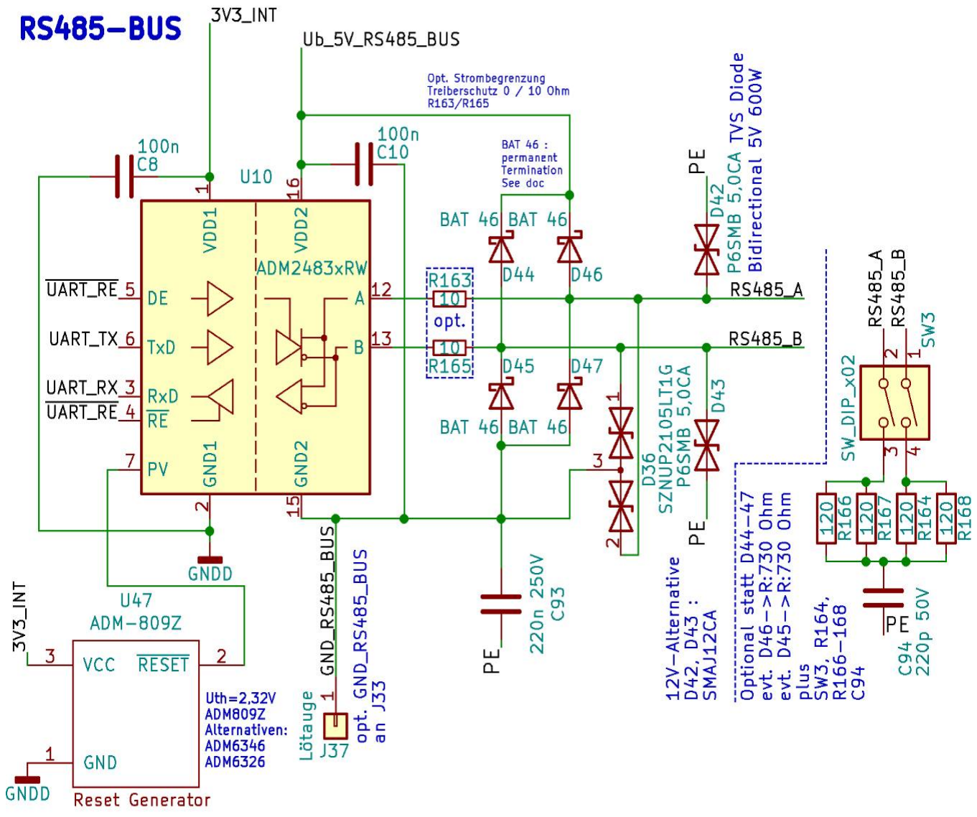
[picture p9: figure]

Der RS485-Bus liegt nur auf einer der beiden 5-Pol-DIN-Buchsen J7
an, | und | entspricht | so
näherungsweise dem Original.

Der ADM809Z hat hier die Funk5on eines Power-On-Reset für den RS485-Baustein und verhindert empfangene Signale in der Einschaltphase. Im Gegensatz zu ADM803* hat der ADM809 keinen Open-
Collector. | D42, | D43 | leiten | Überspannungen | >>5V | von | den | Bus-Leitung | nach | PE | ab.
RS485 mit 12V ist nicht vorgesehen.

D36 begrenzt die Spannungen von A und B gegen GND_RS485.

myT40-PLC C.Niesen CC-BY-NC-SA 2026 | 17

Abbildung 14: RS485 Bus

Abbildung 13: Versorgungsspannungen von UP nach OP

Die Hardware - Au&au der Oberpla5ne (OP)

Seit Version V4 kann man alterna5v an Stelle des Diodenabschlusses D44-D47 einen 120Ω Widerstand per DIP-Switch zuschalten. Die Dioden D44-D47 können dann enSallen. Da 120Ω mit 1% leichter zu bescha@en sind, werden die zwei 60Ω für die spli%ed Variante durch Parallelschaltung erreicht. Zusätzliche 720Ω Widerstände von A oder B auf die Versorgungsspannung Ub_5V_RS485_BUS und GND_RS485_BUS sind nicht vorgesehen. Hier wäre der 4xe Einsatz von 720 Ohm an Stelle der D45/D46 als THT-Bauteil möglich.

J37 liefert op5onal GND_RS485-Poten5al. J28 liefert op5onal GND_CAN-Poten5al.

### 4.1.14 Analog Digital Converter ADC

Der ADC MCP3204 ist ein Standard-ADC mit 4 Kanälen und 12 Bit AuRösung im DIL-14 Gehäuse, der von einem Schni%stellenbaustein ADuM1401xRW zur Ansteuerung von der CPU isoliert wird. Die Kommunika5on erfolgt über den SPI-Bus mit maximal 1,3 MHz TakSrequenz.

Es steht eine Referenzspannungen von 2,5V bereit. Das Eingangsnetzwerk schützt gegen Überspannung bis 30V und hält am ADC die Spannung zwischen 0V und 10V.

Zwei der vier Analog-Eingänge liegen auf dem Terminal vom Ausgangsbyte-0. Die beiden anderen sind mit je einem Poten5ometer zur Sollwert-Eingabe verdrahtet.

Die analogen Eingänge J13 der analogen Baugruppe werden an Stelle der digitalen Ausgänge Q0.5, Q0.6, Q0.7 im Ausgangsbyte-0 auf die Terminal-Anschlüsse J14 der OP verdrahtet, siehe Kapitel 4.1.19. In diesem Fall besitzen das Ausgangsbyte-1 und die restlichen Ausgangs-Bits vom Ausgangsbyte-0 durch eine intern notwendige Kabelbrücke das gleiche 0V-Poten5al, weil die „24V“ und „0V“ der Ausgänge auf dem Terminal Byte-0 von GNDA und einem Analogausgang genutzt werden. Auf der OP stehen für die „24V“- und „0V“-Poten5albrücken passende Lötpads zur Versorgung der Ausgangsbits Q0.0 bis Q0.4 bereit.

C43 und C77 halten störende HF-Signale vom Eingang fern.

Das Eingangsnetzwerk R129/R125 und R130/R127 viertelt die maximale Eingangsspannung von 10V auf 2,5V, die der Referenz-spannung AREF_2V5 entspricht. Der DC Eingangswiderstand beträgt 120kΩ. Man kann jede andere Kombina5on 3/1 mit geringer Toleranz verwenden.

U42 und U43 sind Präzisions-Referenzen und begrenzen die ADC Eingangsspannung wirksam auf 2,5V, bzw. minus 0,4V bei Verpolung.

### 18 myT40-PLC C.Niesen CC-BY-NC-SA 2026

Abbildung 15: Analog Digital Converter

myT40-PLC Documenta5on

In der SoUware ist zu berücksich5gen, dass die SPI-CLK-Frequenz für diesen ADC maximal 1,3MHz betragen darf, sonst werden die resul5erenden Werte verfälscht.

Der DAC be4ndet sich auf der Unterpla5ne und wird dort besprochen.

### 4.1.15 Digitale Eingänge

Die digitalen Eingänge sind gegen Überspannung geschützt, eine „P6SMB5,0CA“ begrenzt die Eingangsspannung an jedem Eingang bipolar. Das Widerstandsnetzwerk betreibt den Optokoppler LTV-488 mit der in Serie liegenden 3mm LED bei 3mA.

Das Eingangsnetzwerk schützt vor Spannungen bis etwa 50V. Die größte Verlustleistung fällt am ersten Serienwiderstand R1...R16 an, dieser ist mit 500mW zu bemessen, 250mW sind für Eingangsspannungen nur wenig höher als 24V nicht ausreichend.

Die Dioden D88...D103 schützen die LED vor nega5ver Eingangsspannung und heben zusammen mit dem Widerstand von 1100Ω bei 3mA und der LED und dem Optokoppler den Spannungspegel bei Überspannung am Eingang (ab ca. 28V) über UBR=6,4V...7V der Schutzdiode P6SMB5.0CA, die daraulin leitend wird.

Bei weiter steigender Eingangsspannung bleibt der Strom durch den Optokoppler konstant, erzeugt aber einen steigenden Spannungsabfall an R1...R16. Bis 50V reicht deren 500mW zulässige Verlustleistung aus.

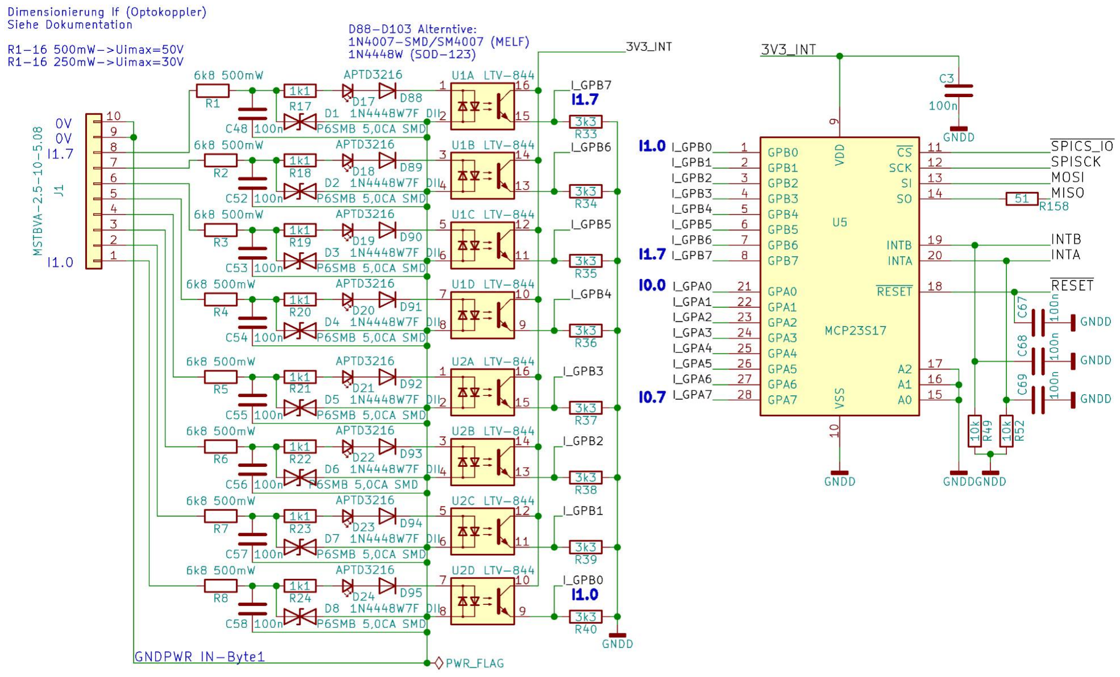
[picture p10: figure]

Die Optokoppler geben die Signale an einen IO-Expander MCP23S17 weiter. Der Anschluss an die CPU erfolgt per SPI-Bus. Per SoUware werden die Eingänge zyklisch abgetastet oder wahlweise ihre Zustände per Interrupt gelesen.

Je Byte ist ein separater Interrupt-Ausgang vorhanden. Beide werden dem CPU-Modul bereitgestellt.

Die Dioden D88-D103 können mit 1N4007 SMD (MELF) oder kleineren 1N 4448W7F DII (SOD-123) bestückt werden. Das Eingangsnetzwerk ist im Anhang detailliert beschrieben (Kapitel 9.8, Seite 57).

myT40-PLC C.Niesen CC-BY-NC-SA 2026 | 19

Abbildung 16: Eingänge für Byte-1

Die Hardware - Au&au der Oberpla5ne (OP)

### 4.1.16 Digitale Eingänge Terminals

Passend zu meinem Original werden die Terminal-Steckbuchsen für J1 , J2 (Eingänge) und
J16 | und | J17 | (Ausgänge) | verwendet.
Beide Eingangsbytes können mit separatem Poten5al beschaltet werden, die 0V-Anschlüsse von Byte-0 sind isoliert von denen des Byte-1.

Bei Bedarf kann intern auf der Pla5ne 0V und 24V zwischen Byte0 und Byte1 verbunden werden.

In myT40-PLC sind die Eingangs-Pins 9 und 10 beide mit 0V ihres Bytes verbunden, im Original ist der Pin-9 unbeschaltet.

### 4.1.17 Versorgungsspannung der CPU und Peripherie-Bausteine

Das Versorgungsspannungs-Terminal J9 nimmt 0V, 24V und PE für die Versorgung von CPU und Interfaces entgegen. Die Anschlüsse werden unmi%elbar auf die untere Pla5ne durchgereicht.

PE ist auf beiden Pla5nen als zusätzliche Abtrennung zwischen den Poten5alen der Steuerung und den Einbzw. Ausgängen verlegt. Im Originalgehäuse stellen Flachstecker-Messer eine Verbindung zwischen PE der Pla5nen und der Automatenschiene her. In anderen
Gehäusen kann mit einem Flachstecker die PE-Verbindung nach außen hergestellt werden. Als interne⁶
Alterna5ve schließt eine Lötbrücke (auf OP und UP) die PE-Verbindung zum Versorgungsspannungsterminal J9 (OP: J61 <-> J62, UP: J63 <-> J64).

Es darf entweder nur die externe oder nur die interne Alterna)ve verwendet werden, um PE-Ausgleichsströme über die Pla)ne und den daraus resul)erenden Störungen zu vermeiden!

Auf der Unterseite der oberen Pla5ne be4nden sich exakt
über den Sandwich-Pin-Leisten der unteren Pla5ne
entsprechende Pin-Buchsen. So kann die obere Pla5ne
einfach auf die untere aufgesteckt werden. Das gilt für alle Verbindungen ab V2 mit Ausnahme der DAC-Signale. Diese werden per abgeschirmtem Kabel mit OP verbunden. Der Schirm sollte wie üblicherweise nur einsei5g an PE (J41 OP) aufgelegt werden. F1 und RV1...RV3 schützen nur CPU und Interfacebausteine sowie das EEPROM.

6 Im Falle der Ausgänge steht damit nur eine Steckverbindung von der UP über J9 zu PE zur Verfügung. Besser ist immer der Anschluss per Flachstecker J44 im beliebigen Gehäuse oder J45 im Originalgehäuse.

### 20 myT40-PLC C.Niesen CC-BY-NC-SA 2026

Abbildung 18: Versorgungsspannung CPU und Peripherie

Abbildung 17: Eingänge Byte-0

myT40-PLC Documenta5on

### 4.1.18 Terminals Digitale Ausgänge

Auf der Oberpla5ne sitzen die beiden Terminals J16 und J17 für die digitalen Ausgänge. Bei Bedarf werden auf J14/J17 die Eingänge des ADC, sowie den Ausgänge des DAC, nebst eigenem analogen Ground GNDA beschaltet.

Die ADC-Eingänge stehen an J13
bereit und werden direkt auf der
Oberpla5ne | nach | J14 | gepatcht
(6,7,8), während die Signale des DAC von der Unterpla5ne über Kabel und den Pfostenstecker J14 an die Oberpla5ne J14(9,10..13,14..15) angeschlossen werden.

Die Ausgänge der UP werden über 15-polige Stapelleisten J49 und J50 auf 15-polige Buchsen J12 und J14 der OP verbunden. Da jeder Ausgang 500mA schalten können soll, gibt es 5 Pins, die „24V“ führen. Zusätzlich verwende ich die vergoldeten Varianten der Stapelleisten. Dagegen genügen zwei Pins für „0V“ als Bezugspoten5al für Optokoppler und BSP-452.

Werden die Signale und Poten5ale der ADC (U0/U1/GNDA) und DAC (U10 /U11/GNDA) auf J14 aufgelegt, reduziert sich die Anzahl der digitalen Ausgänge im Byte-0 von 8 auf 5, und zusätzlich wird eine
Zusammenlegung | von | „0V“ | bzw. | „24V“ | der | Digitalausgang-Bytes | notwendig.
Dafür gibt es Lötaugen: J32—J35 (24V) und J38—J39 (0V).

Details siehe Kapitel 8.1 „Verdrahtung möglicher Varianten zur Nutzung wie im Originalgehäuse, V5 M44 (FFC)“ Seite 44. Die Stapelleiste von J50 (UP) auf J14 (OP) für das Ausgangsbyte-0 verkürzt sich in diesem Falle auf 5 Pins.

### 4.1.19 Verbindung der ADC-Signale auf Ausgangs-Terminal Byte-0

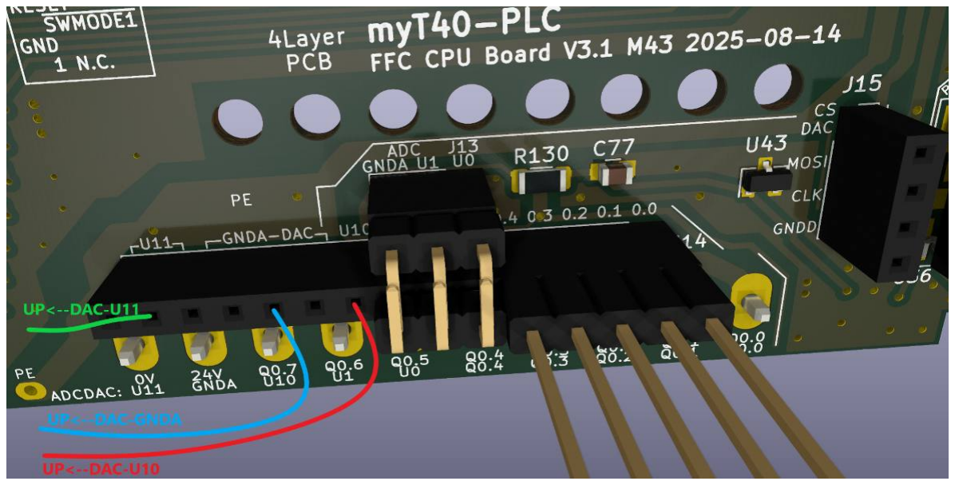
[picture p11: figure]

Zum Patchen der ADC-Signale von J13
auf J14 bieten sich zwei 90°-Pinheader
im Raster 2,54 mit je 3 Pins an. Damit
werden U0/U1/GNDA auf J14 gelegt. Der DAC stellt per Kabel seine Ausgänge auf J14 von der UP kommend bereit. Der Schirm wird einsei5g auf PE gelegt.
Die Poten5ale 0V und 24V der
verbleibenden | digitalen | Ausgänge
werden von Byte1 auf Byte0 gebrückt.

Am Terminal Byte-0 können so
folgende Signale anliegen:
Mit ADC/DAC: | Q0, Q1, Q2, Q3, Q4, ADC-U0, ADC-U1, DAC-U10, GNDA 0V, DAC-U11 (von oben)
Ohne ADC/DAC: | Q0, Q1, Q2, Q3, Q4, Q5 | , Q6 | , Q7 | , 24V | , 0V | (von oben)
myT40-PLC C.Niesen CC-BY-NC-SA 2026 | 21

Abbildung 21: ADC+DAC Patch auf Ausgangs Terminal Byte-0 von unten gesehen

Abbildung 20:
Terminal Ausgang Byte-1 Abbildung 19: Terminal Ausgang Byte-0

Die Hardware - Au&au der Oberpla5ne (OP)

### 4.1.20 Verbindung der SPI-Signale von OP zu UP

Der SPI-Bus reicht vom Extension-Port über das EEPROM zur CPU mit S5chleitungen zu den Expandern von OP zu UP (J4,J19), und auf UP weiter zum DAC (UP) mit Überleitung zum ADC auf OP (J15, J26).

Ab V4 leitet der Pin-8 von J4 das Steuersignal an Q2 zur Abschaltung der 3,3V-Versorgungsspannung der Interfacebausteine zur UP durch.

### 4.1.21 Der op1onale Port für Lokale Erweiterung

Diese S5Uleiste J40 (RM 2,54mm) erlaubt im Originalgehäuse den Anschluss einer lokalen Erweiterung.
Aktuell ist nur das CS-Signal für die digitalen Ein/Ausgänge aufgelegt, sowie alle SPI relevanten Signale. Zusätzlich sind 3,3V und 0V GND, RESET, sowie PE auf dem Terminal vorhanden.

Die Erweiterungen werden über die Adress-Eingänge A0, A1, A2 der MCP23S17 lokal auf eine bes5mmte Adresse gelegt. Adresse 0 und 1 sind genutzt, 2-7 sind noch frei. Zwei Pins (7/11) des Erweiterungsterminals sind nicht verdrahtet. Die Anpassung der lokalen Erweiterungen, siehe Kapitel 13 . Original-lokale Erweiterungen sind nicht verwendbar!

Sollten Erweiterungen gebaut und angeschlossen werden, ist darauf zu achten, dass jeder SPI-Treiber unmi%elbar an seinem Ausgang für MISO einen Serienwiderstand , z.B. 51 Ohm, erhält.

Eine originale lokale 16-fach digitale Ausgangserweiterung kann nach einem passenden Umbau für myT40-PLC verwendet werden. Dazu wird die Kopfpla5ne für die Kommunika5on gegen eine neue Pla5ne ausgetauscht. Diese wird in Kapitel 13 auf Seite 77 beschrieben. Pin7 und Pin11 sind auf dieser Pla5ne als Reserve (z.B. SPI-Chip-Selec5on) durchgeleitet.

### 22 myT40-PLC C.Niesen CC-BY-NC-SA 2026

Abbildung | 22: | SPI | Verbindungen
zwischen oberer und unterer Pla&ne

Abbildung 23: Exten&on Port op&onal

### 4.2 Schaltplan Oberpla1ne (OP) Variante PFS und FFC

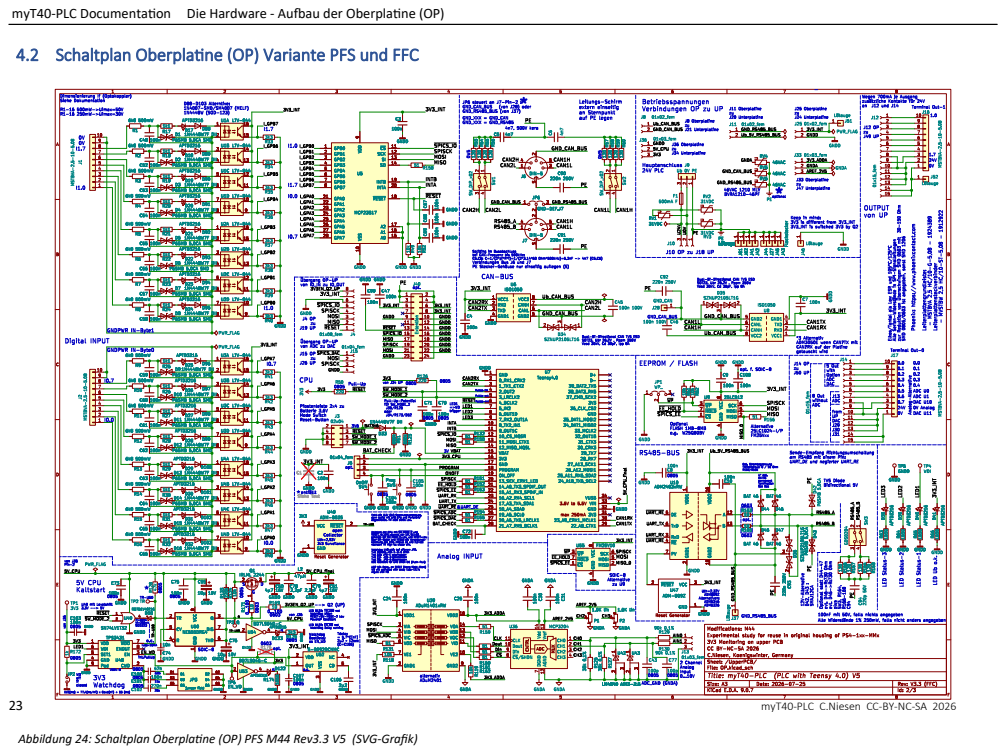
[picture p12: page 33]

myT40-PLC Documenta5on Die Hardware - Au&au der Oberpla5ne (OP)

23 myT40-PLC C.Niesen CC-BY-NC-SA 2026

Abbildung 24: Schaltplan Oberpla&ne (OP) PFS M44 Rev3.3 V5 (SVG-GraEk)

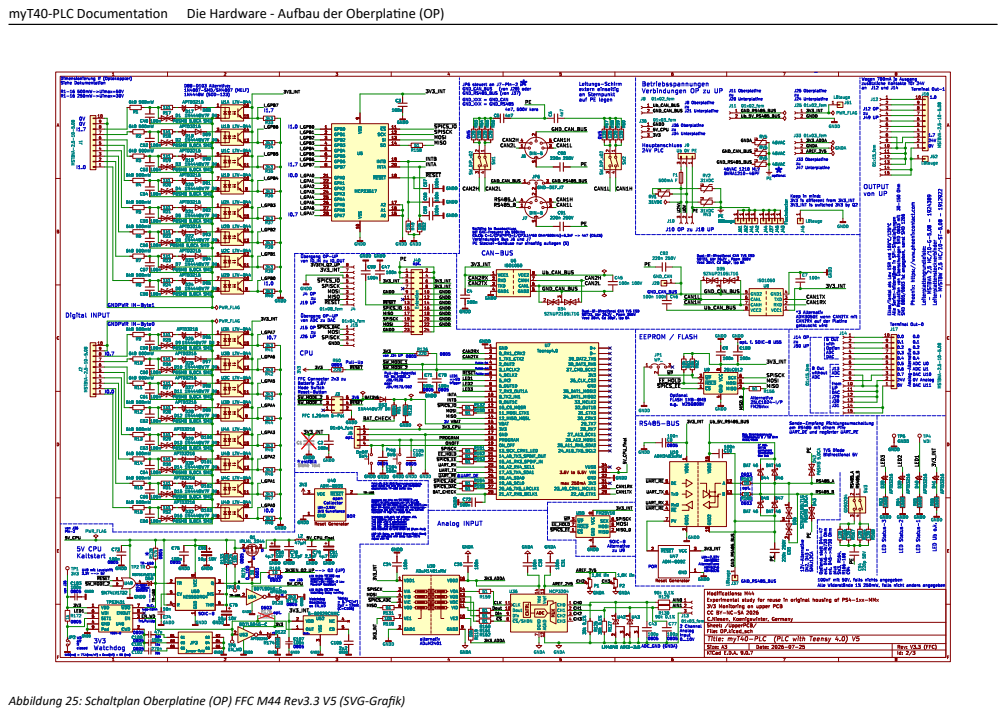
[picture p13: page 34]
myT40-PLC Documenta5on; Die Hardware - Au&au der Oberpla5ne (OP)

24 myT40-PLC C.Niesen CC-BY-NC-SA 2026 Abbildung 25: Schaltplan Oberpla&ne (OP) FFC M44 Rev3.3 V5 (SVG-GraEk)

myT40-PLC Documenta5on

## 5 Die Hardware - AuBau der Unterpla1ne (UP)

Die untere Pla5ne (UP) ist so konzipiert, dass sie mit der Oberpla5ne in das Originalgehäuse passt. Wie die Oberpla5ne enthält sie passend übereinander liegende 3,05mm Bohrungen für Abstandsbolzen zur Montage in einem beliebigen anderen Gehäuse oder Modulträger.

Die UP stellt alle Versorgungsspannungen bereit und versorgt damit beide Varianten FFC und PFS der OP über Stapelleisten. Der Abstand der Oberpla5ne zur Unterpla5ne beträgt 29 mm im Originalgehäuse. In einem Alterna5vgehäuse ist der Abstand freier gestaltbar.

Die Unterpla5ne ist eine Mul5-Layer-Pla5ne mit 2 Layern.

### 5.1 Komponenten der unteren Pla1ne (UP): Base-Modul

### 5.1.1 Digitale Ausgänge

Die Ausgänge sind bipolar gegen Überspannung geschützt, je eine P6KE33CA begrenzt die Spannung auf ca. 33V an jedem Ausgang und am Versorgungsspannungseingang „24V“.

Als Treiber wird je Ausgang der Baustein BSP-452 verwendet. Er kann maximal 700mA schalten, ist überspannungsfest und kurzschlusssicher und verfügt über eine interne Freilaufdiode. Er verträgt maximal 40V. Die Alterna5ve BTS4141N verträgt eine noch etwas höhere Spannung.

Auf Grund der kleinen KühlRäche=KupferRäche auf der Pla5ne, sollte ein dauerhaUer Strom 500mA nicht übersteigen, das entspricht der Spezi4ka5on des Originals.

Trotz aller Schutzmaßnahmen innerhalb des BSP-452 gilt grundsätzlich:

Jeder nicht-ohmsche Verbraucher muss vor Ort (!) seine eigene passende Schutzbeschaltung besitzen, denn
Störungen und Spannungsspitzen | sollen | dort eliminiert werden, wo sie auUreten!
Zwar sind die Eingänge von myT40-PLC doppelt geschützt, aber die zu steuernden Elemente beeinRussen u.U. andere Geräte über parallel liegende Verkabelung, S5chwort EMV(Elektromagne5sche Verträglichkeit).

Die 24V werden von außen über die Terminals getrennt je Byte hereingeführt, auch das 0V Bezugspoten5al ist je Byte vorgesehen, op5onal kann intern beides auf der UP gebrückt werden:

0V: J38 – J39 , 24V: J35 - J32

Nur wenn ADC oder/und DAC vorhanden und in ein Originalgehäuse eingebaut sind, enSällt diese Trennung, da dann intern in jedem Fall gebrückt werden muss. Mehr dazu unten in Kapitel 8.1.

Die 24V-Schiene ist je Ausgangsbyte mit 4A bis 5,6A mi%elträgen Kleinstsicherungen abgesichert. Bei Einsatz mit ADC und/oder DAC wird die Absicherung für das Ausgangsbyte-0 auf 2,0 bis 3,15A träge reduziert.

Natürlich hä%e ich auch den VN330 aus dem Original in seiner neusten Variante verwenden können. Für eine ADC/DAC-Variante im Originalgehäuse von Byte-0 mit 5 Ausgängen bedient dieser Baustein nur 4 Ausgänge. Der 5. wäre dann abweichend mit BTS4141 oder BSP452 zu bestücken. Das Original bietet in dieser Variante nur einen DAC und hat damit Platz für 6 digitale Ausgänge, weshalb dann „nur“ 2 Linien eines zweiten VN330 ungenutzt blieben.

Mit der Möglichkeit aus ungenutzten Ausgängen wenigstens Status-LEDs zu machen, ist mein Ansatz Rexibler, auch was Reparaturen angeht, siehe Kapitel 22.3.5.

myT40-PLC C.Niesen CC-BY-NC-SA 2026 | 25

Die Hardware - Au&au der Unterpla5ne (UP)

Die Ausgänge werden in einem Originalgehäuse über Stapelleisten auf die Unterseite der Oberpla5ne verbunden. Ausgangs-Byte-1:

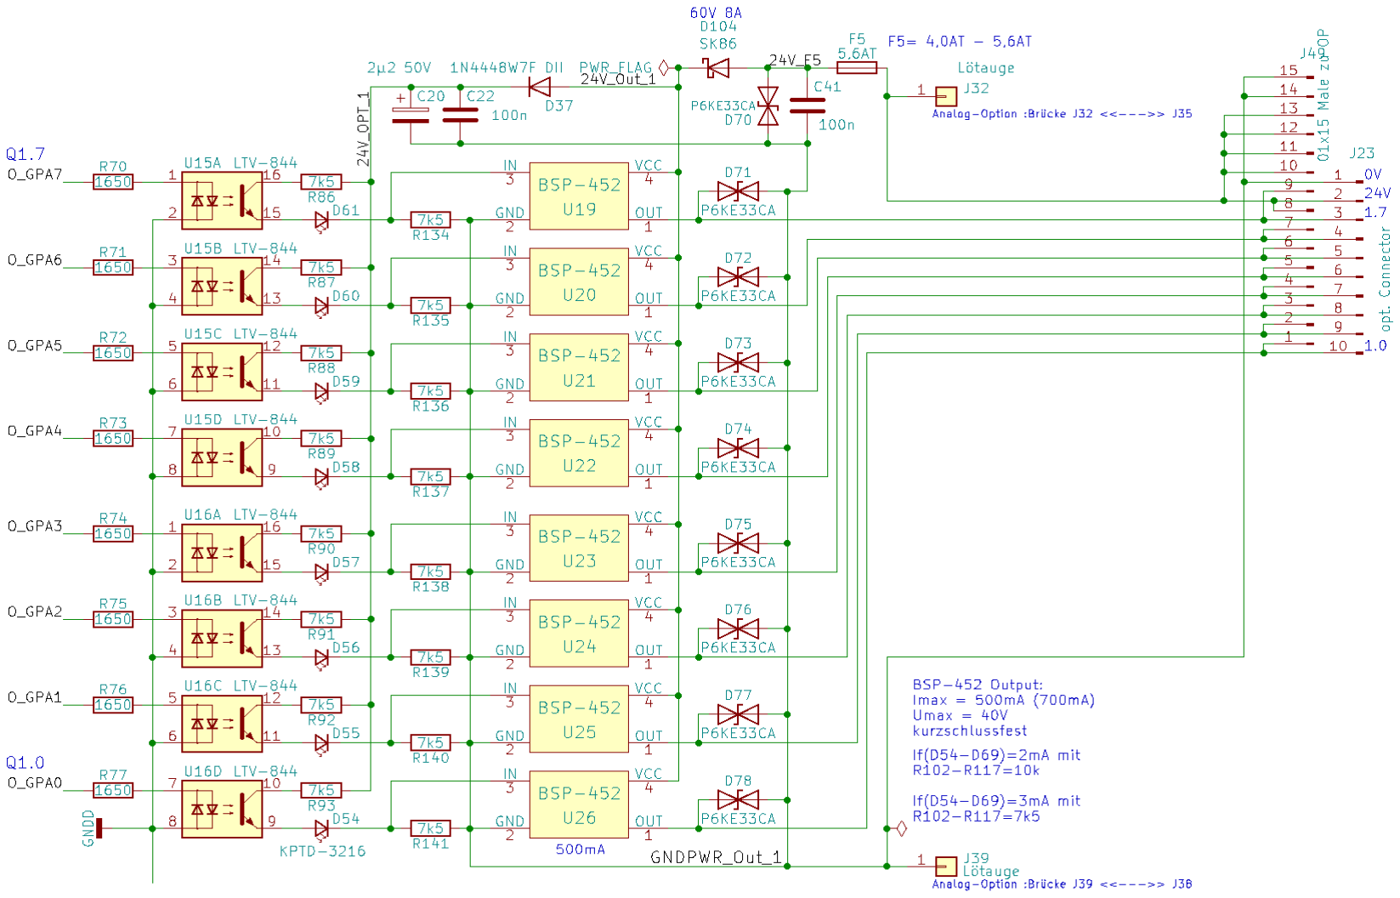
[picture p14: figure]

Bei Verwendung eines alterna5ven Gehäuses besteht die Möglichkeit vorhandene Lötpads der Unterpla5ne direkt für abgewinkelte Terminals zu verwenden : J22 und J23, siehe Abbildung 29 auf Seite 27. Dadurch werden die Anschlüsse des Ausgangs-Terminals Byte-0 auf der Oberpla5ne frei für die analogen Signale und deren Bezugspoten5al GNDA und es enSallen J49/J50 auf der UP und J12/J14 auf der OP.

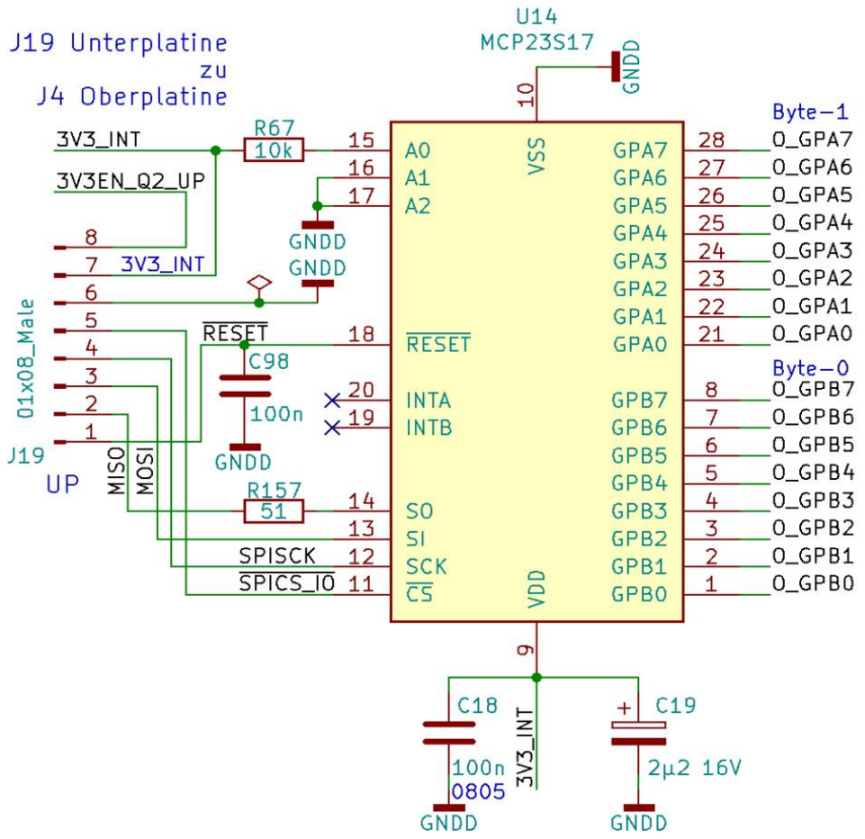
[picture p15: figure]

Die | Entkopplung | zwischen | dem | IO-Expander
MCP23S17 und den Ausgangstreibern wird mit
LTV-488 Optokopplern im DIL-14 Gehäuse realisiert.
Alle Optokoppler sind gesockelt.
Der Anschluss des MCP23S17 an die CPU erfolgt per SPI-Bus.

Die LED der Ausgänge werden mit 3mA betrieben. Die verwendeten Lichtleiter ragen bis in die passenden Bohrungen der Oberpla5ne hinein. Dort dürfen sie maximal 2mm herausragen, wenn das Licht von den Lichtleitern des Originalgehäuses entgegengenommen wird.

Mit V4 kommt über J19 das Steuersignal für Q2 (3V3EN_Q2_UP) auf der UP an. Q2 schaltet die Spannungsversorgung 3V3_INT aller Interfacebausteine bei Kaltstart ab, siehe Kapitel 4.1.5, Seite 11.

### 26 myT40-PLC C.Niesen CC-BY-NC-SA 2026

Abbildung 26: Schaltplan Ausgangs-Byte-1

Abbildung 27: Ansteuerung der Ausgangsbytes

myT40-PLC Documenta5on

Bei Originalgehäuse emp4ehlt sich wegen der mehrfachen op5schen Übergänge die LED mit 3mA zu treiben. Wem das zu hell ist: Dimensionierung der Widerstände siehe Schaltplan oben.
In der SoUware ist zu beachten⁷
: Ab V2.0 liegen Byte-0 auf GPB0-7, und Byte-1 auf GPA0-7.

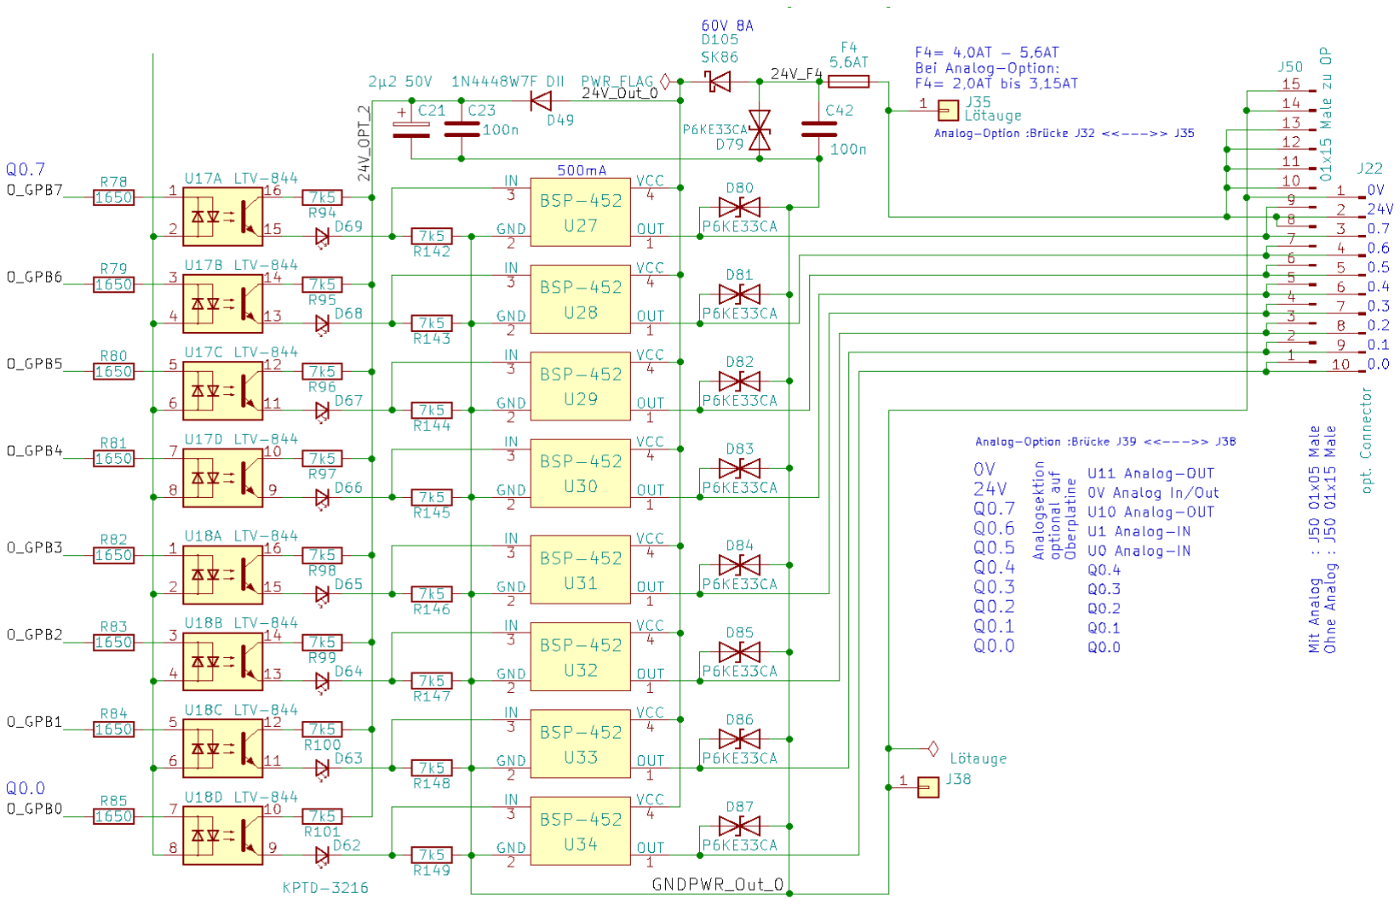
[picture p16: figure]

D49 und D37 entkoppeln mit C20 und C21 die Versorgungsspannung für die Optokoppler von Störungen auf der lastsei5gen Einspeisung für die Ausgänge.
Alterna5v kann man sta% BSP-452 auch BTS-4141N verwenden. Letzterer bietet eine etwas höhere Spannungsfes5gkeit.

Mit ADC und DAC lassen sich op5onal die LED der nicht nutzbaren Ausgänge im Byte-0, Bit-5 bis Bit-7 als separate Statusanzeigen nutzen. Idealerweise durch eine andere LED-Farbe, wie orange, sta% rot. Details dazu im Anhang 9.1 Op5onale Nutzung von Q0.5, Q0.6 und Q0.7 als Status-LED auf Seite 49.

Ich habe mit für die BSP/BTS entschieden, weil sie mehrere Schutzschaltungen schon mitbringen.

7 Bei den Prototypen-1 und -2 war das noch umgekehrt.

myT40-PLC C.Niesen CC-BY-NC-SA 2026 | 27

Abbildung 29: Op&on Digitale Ausgänge mit Terminals auf der UP

Abbildung 28: Schaltplan Ausgangsbyte-0

Die Hardware - Au&au der Unterpla5ne (UP)

### 5.1.2 Digital-Analog-Converter DAC

Die Abweichung zu meinem Original: Es stehen zwei DAC 0..10V Ausgänge poten5algetrennt zur Verfügung.

Der DAC wird mit einem MCP4922 realisiert. Der Isola5onsbaustein ist ein ADuM1401xRW. Er leitet die SPI-Signale MOSI und CLK sowie den CS an den DAC durch.

Der DAC arbeitet mit einer Referenzspannung von 2,5V. Das Ausgangssignal wird über einen Opera5onsverstärker mit dem Spannungsteiler 4:1 auf Spannungen auf 0V-10V angehoben.

Das erfordert eine Mindestspannung von 12 V für die Spannungsversorgung des Opera5onsverstärkers.

Die Ausgänge werden mit verlöteten und abgeschirmten Kabeln (J29,J30,J31) bzw. Pinheader im Raster 2,54mm auf der unteren Pla5ne mit Steckern auf der oberen Pla5ne mit J14 verbunden. Dafür enSallen passend die Pins der Stapelleiste J50 für die Durchschaltung der Ausgangspannung „24V“ und „0V“, sowie weitere (Q0.5, Q0.6, Q0.7) zu Gunsten des DAC (und ADC).

Die Leiterbahnen der Signale MOSI und CLK werden vom ADC (OP) kommend per Stapelleiste J15 zum DAC (UP) auf J26 als letzte OP-UP-Brücke der SPI-Ke%e heruntergereicht.

Man könnte natürlich U35 durch einen einzelnen Optokoppler für SPICS_DAC ersetzen und die anderen SPI-Signale hinter U39 von der OP abgreifen. Das ist aber nicht so schön. Mal braucht man DAC , mal ADC.

### 28 myT40-PLC C.Niesen CC-BY-NC-SA 2026

Abbildung 30: Digital Analog Converter

myT40-PLC Documenta5on

### 5.1.3 Spannungsversorgung

Die Eingangsspannung an J9 wird von der Oberpla5ne an die Unterpla5ne mit Sandwich-Pinleiste auf J18 übertragen.

Die Versorgungsspannung für die CPU von 5V wird aus den 24V Eingangsspannung direkt erzeugt. Der dafür verwendete Baustein LC78-03-1.0 ist ist für Eingangsspannungen von bis zu 42V ausgelegt. Eine 1.5KE30CA,(D51 s.u.) alterna5v 1.5KE33CA / 1.5KE36CA begrenzt die Eingangsversorgungsspannung hinter der 500mA Sicherung (F1 auf der OP)).

Aus den 5V (U46) für die CPU werden 3,3V (U13) für die Peripherie-Bausteine bereitgestellt.

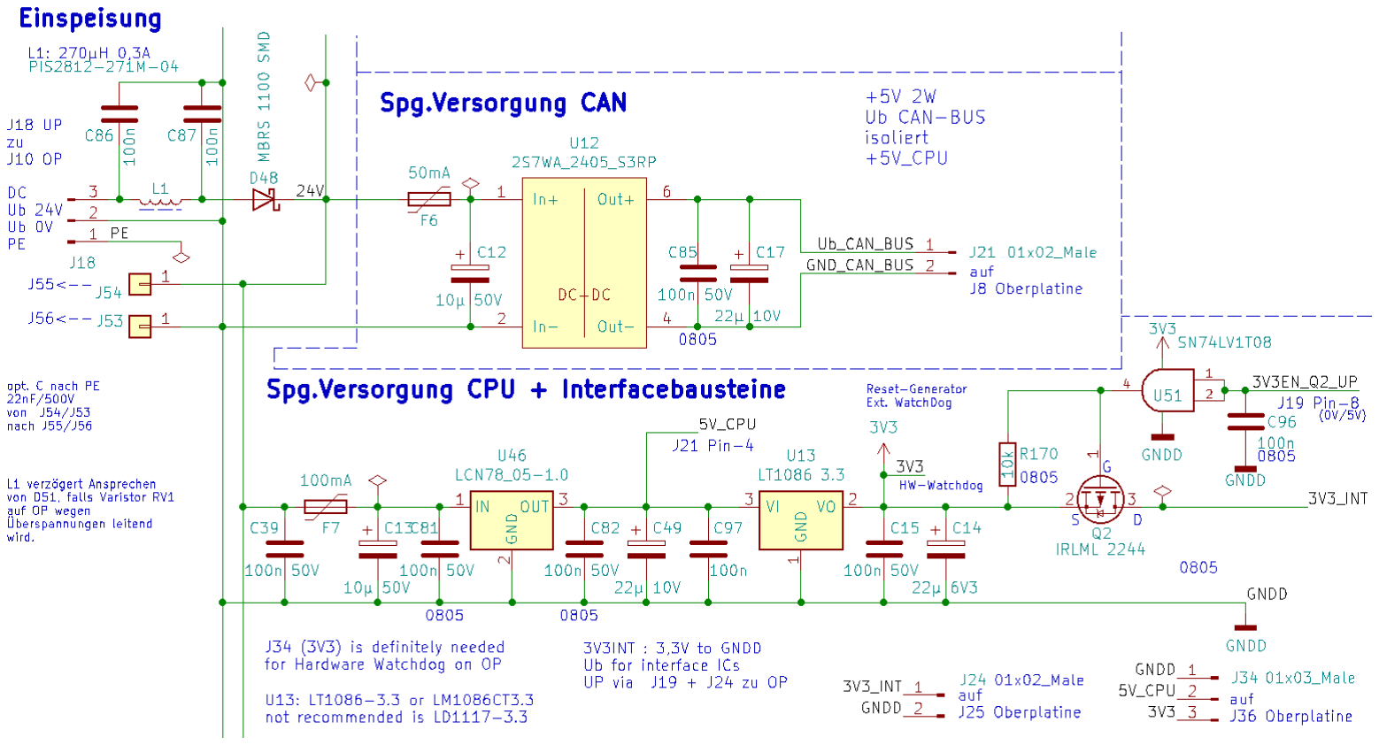
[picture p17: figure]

Seit V4 wird auch die Interface-Spannungsversorgung 3V3_INT zusammen mit der 5V-CPU-Spannung 5V_CPU_FINAL abgeschaltet. Auf der OP wird 3V3 ohne Unterbrechung für den Pull-Up von SW_MODE_2 und den Watchdog mit Delay benö5gt. J34 stellt daher 3V3 auch auf der OP bereit.

Es ha%e sich gezeigt, dass über die mit 3,3V versorgen Signalleitungen der Interfacebausteine eine Teilspeisespannung von 2V am 5V-CPU-Modulpin Teensy4.0 ansteht, wenn Q1 die 5V abschaltet. Diese 2V waren belastbar, an einem 470-Ohm Widerstand Rossen knapp 3mA.

Damit diese Form der Rückspeisung unterbleibt, müssen auch die 3,3V der Interfaces abgeschaltet werden. Dadurch wird auch der von der CPU getriggerte Kaltstart möglich (automa5scher Neustart ab V4).

C96 enSernt Störanteile im Signal, mit R169 auf der OP entsteht ein Tiefpass.

Der Reset-Generator U40 für die Interface-Versorgungsspannung ist mit V5 auf die OP verlegt worden. Das gilt auch für den Pull-Up der RESET-Leitung R50, der nun auf 220 Ohm reduziert wurde, weil spannungslose Eingänge am Teensy mit einem PullUp von 10k nur zu 1,8V führte, was nicht einem High am ODER-Ga%er U49 entspricht.

Da das Signal „3V3EN_Q2_UP“ entweder 0V bzw. 3V3 betragen kann, könnte man zur Absicherung der 3,3V eine 3,6V-Zenerdiode vom Q2-Source gegen GNDD vorsehen, da für Q2 gilt : -12V <= Ugs <= 12V. Ich habe mich für eine saubere Lösung entschieden, die mit U51 ein UND-Ga%er ein LevelshiU realisiert.

myT40-PLC C.Niesen CC-BY-NC-SA 2026 | 29

Abbildung 31: Spannungsversorgung CPU + Peripherie und CAN Busse

Die Hardware - Au&au der Unterpla5ne (UP)

Die zweite Spannungsversorgung für die CAN-Bus-Bausteine wird von einem isolierten DC-DC-Wandler erzeugt. Damit sind die alle Poten5ale des CAN-Busses vom Rest der Steuerung separiert.

Das gleiche gilt für die dri%e Spannungsversorgung des RS485-Busses. Auch diese ist vom Rest der Steuerung isoliert.

Und schließlich ist auch die vierte Versorgungsspannung des ADC und DAC poten5algetrennt. Damit werden in gewissen Grenzen poten5alfreie Messungen möglich. Die Poten5al-Di@erenz zu PE und anderen auf jeweilige GNDx bezogene Poten5ale ist durch die Leiterbahnabstände limi5ert und sollte angenommene 50V nicht überschreiten.

Für den ADC/DAC werden zunächst 15V für den DAC bereitgestellt, aus denen dann die Referenzspannungen 2,5V und die 3,3V für die Schni%stellenbausteine (Isola5on SPI-Bus) und ADC bzw. DAC erzeugt werden.

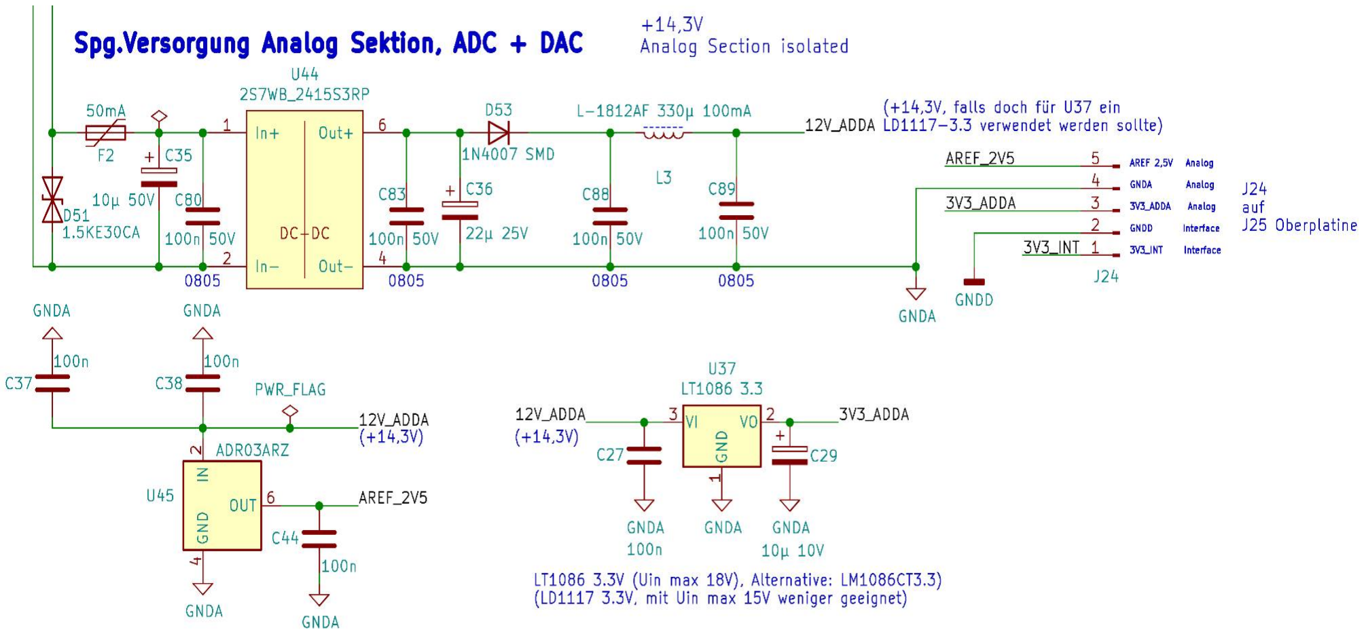
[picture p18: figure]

Wenn man für U37 sta% LT1086 einen LD1117 verwenden möchte, muss eine Diode D53 die Spannung etwas absenken, da dieser maximal 15V Eingangsspannung verträgt. Für U44 eine 12V-Variante einzubauen, hilU nicht weiter, weil 12V die Minimalspannung für den Opera5onsverstärker hinter dem DAC ist, damit dieser noch die vollen 10V an seinem Ausgang bereitstellen kann. Empfohlen wird daher ein LT1086-3V3. D53 kann dann durch eine Brücke ersetzt werden. Alle Spannungswandler sind nach seit V3 mit PPTC reversiblen FSMD-Sicherungen abgesichert. Sie helfen den Aufwand und Kosten für Reparaturen nach missglückten Experimenten zu reduzieren.

### 30 myT40-PLC C.Niesen CC-BY-NC-SA 2026

Abbildung 33: Spannungsversorgung ADC und DAC

Abbildung 32: Spannungsversorgung RS485

### 5.2 Schaltplan Unterpla1ne

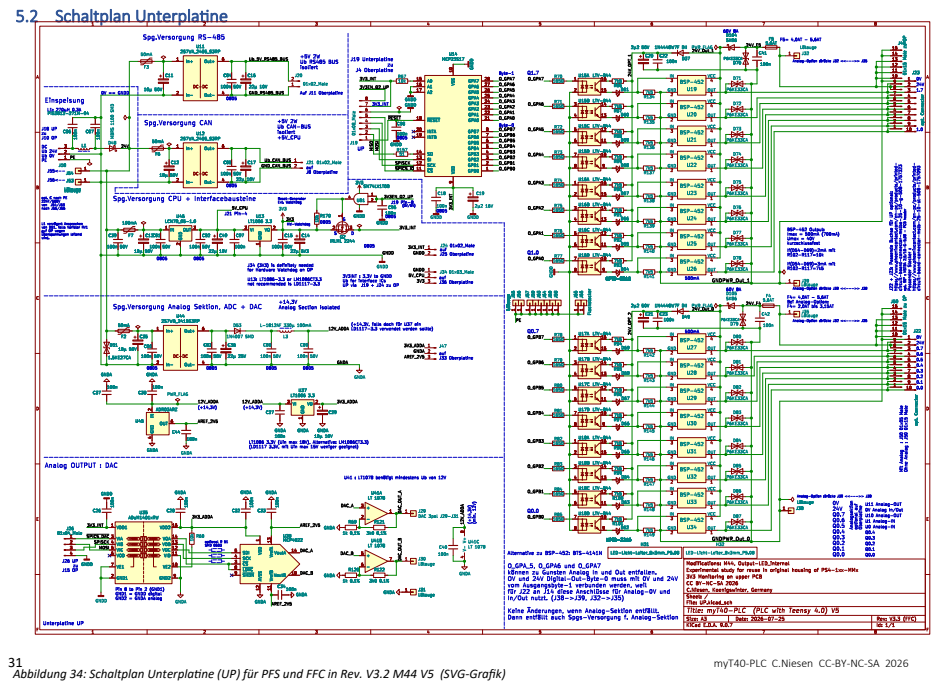
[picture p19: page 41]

31 myT40-PLC C.Niesen CC-BY-NC-SA 2026
Abbildung 34: Schaltplan Unterpla&ne (UP) für PFS und FFC in Rev. V3.2 M44 V5 (SVG-GraEk)

### 32 myT40-PLC C.Niesen CC-BY-NC-SA 2026

## 6 Layout Details

### 6.1 OP UP : PE

myT40-PLC Documenta5on

PE Poten5al auf den äußeren Layern.

PE trennt die Poten5ale der Steuerung von den Poten5alen der Ein- und Ausgangs-Bytes, auf TOP und BOT-Seite der Pla5nen. Gleiches gilt für die Busse CAN und RS485. Links OP, rechts UP.

### 6.2 OP : ADC

Der Analogteil wird mit GNDA und PE von GNDD und anderen Signalen abgeschirmt. GNDA ist für den ADC sternförmig verlegt.

Im Bereich des ADC bilden die beiden inneren Layer der 4-lagigen OP-Pla5ne seit V4 GNDA vollRächig ab.

### 6.3 UP : DAC

Auch auf der UP grenzen GNDD, PE und GNDA andere Signale ab. GNDA ist für den DAC ebenfalls sternförmig angeordnet.

myT40-PLC C.Niesen CC-BY-NC-SA 2026 | 33

Layout Details

### 6.4 Weitere Details im Pla1nen Design

0V und 24V sind je Ein- und je Ausgangs-Byte getrennt. 0V der Ausgänge werden bei Bedarf extern oder intern gebrückt.

Werden analoge Anteile der Schaltung in ein Original-Gehäuse eingebaut, enSällt die Trennung der 0V für die Ausgangs-Bytes, da ein Teil der Ausgangs-Terminals (Q0.5, Q0.6, Q0.7,0V,24V) für die analogen Poten5ale benö5gt wird. Daher müssen passende Brücken die dann fehlenden Verbindungen für 0V und 24V intern auf der UP herstellen. Siehe „5+8 Ausgänge, 2x8 Eingänge, mit ADC , mit DAC“ , Kapitel 8.1.2, Seite 45.

Die Eingangs-Bytes lassen sich nur außerhalb der Pla5nen über die Terminals brücken. Dafür gibt es an jedem Eingangsterminal je zwei 0V-Klemmen. Hier liegt ein Unterschied zur Original-SPS vor, welche den Pin-9 an jedem Byte unbeschaltet lässt.

Die Pads (Pin-4 , 24V) für die Treiber BSP-452 der Ausgänge liegen zu Kühlungszwecken auf einer breiteren 24V-Schiene.

Alle Bus-Signale sind auf gleiche Längen getrimmt. Das gilt sowohl für CANxH, CANxL, RS485-A und-B, als auch die von der CPU abgehenden Signale für die Busse, wie MOSI, MISO, und CLK und CS. Die Phasenkorrektur blieb unberücksich5gt. Ab V2 ist nur noch eine kurze S5chleitungen von OP zu UP vorgesehen, was einen durchgehenden SPI-Bus ermöglicht und die Qualität des Signals verbessert.

Entkoppelkondensatoren liegen an den Spannungsversorgungspins der IC so dicht wie möglich an. Alle 100nF Entkoppelkondensatoren sind für 50V vorgesehen, mit Ausnahme der Kondensatoren C45 und C46 auf der Spannungsversorgung des CAN-Busses auf der Busseite, diese sind bis 100V spannungsfest. Die keramischen 4n7 Schirmkondensatoren C5 und C6 zwischen PE und den CAN-Bus Abschlusswiderständen weisen eine Spannungsfes5gkeit von 500V, beim Schirm gegen PE 250V auf.

Das Originalgehäuse verfügt über integrierte PE-Klemmleiter, die mit der Befes5gungsklammer auf der Automatenschiene (Montageschiene) elektrisch verbunden sind. Seit Version V2.0 besitzen OP und UP dafür an der passenden Stelle Lötpads für einzulötende Kontaktstreifen, für teils gekürzte oder ungekürzte 6,3mm Flachstecker-Messer zum Einlöten in die Pla5ne.

Nur wenn keine geerdete Automatenschiene verwendet wird oder die Flachstecker nicht eingesetzt oder verwendet werden, sollten die PE-Brücken J61-J62 (OP) und J63-J64 (UP) eingesetzt werden. Ein DurchRuss von Ausgleichsströmen auf dem PE-Leiter durch die Steuerung muss vermieden werden.

Mit der 4-lagigen Oberpla5ne Pla5ne (OP) seit V4 liegen auf dem Layer IN1 alle Bussignale und sons5gen weitläu4gen Querverbindungen. Der Innenlayer IN2 stellt bis auf einen kleinen Bereich GND, GNDA, GND_CAN, GND_RS485 und PE zur Verfügung. Das gilt auch für Bereiche ohne Busverbindungen auf Layer IN1, auch hier liegen GND*-Poten5ale.

Die Umschichtung der Bussignale auf IN1 hat den notwendigen Platz in Version-5 (M43) für den Hardware-Watchdog nebst Delay auf dem TOP-Layer gescha@en.

### 34 myT40-PLC C.Niesen CC-BY-NC-SA 2026

myT40-PLC Documenta5on

## 7 Ansichten der Pla1nen

Auf den folgenden Seiten sind in Ermangelung einiger 3D-Modelle teils nicht ganz vollständige Ansichten der Pla5nen abgebildet. Die Serie wird durch Fotogra4en der bislang entstandenen Prototypen ergänzt.

### 7.1 Die untere Pla1ne – Base Board

Die Unterpla5ne ist hier mit zwei verschieden möglichen op5onalen Terminals abgebildet. Rechts sind zwei mögliche Flachsteckeranschlüsse für die PE-Schienen-Verbindung im Originalgehäuse zu sehen. In einem Alterna5vgehäuse kann einer von beiden mit dem passenden Stecker auf PE gelegt werden. Alterna5v läßt sich eine PE-Brücke J63—J64 am oberen Rand, links von der Mi%e erkennbar, einsetzen. Das gleiche gilt für die Oberpla5ne. Siehe auch unten Abschni% 8.3. Die PE-Verbindung erfolgt dann über Das Terminal J9.

Man erkennt die beiden möglichen Anschlussfahnen für den PE. Die obere kann ungekürzt im Originalgehäuse verwendet werden, während die untere dafür gekürzt werden müsste.

In anderen Gehäusen ist die Verwendung beliebig.

Empfohlen wird die Verwendung der Flachstecker für Ober- und Unterpla5ne für eine sichere PE-Verbindung. Die PE-Brücken J61-J62 (OP) und J63—J64 (UP) sollten dann o@en bleiben, damit Ausgleichsströme über die Pla5ne unterbunden werden. PE an J9 (Versorgungsspannung 24V+, 0V, PE) sollte in jedem Fall angeschlossen werden.

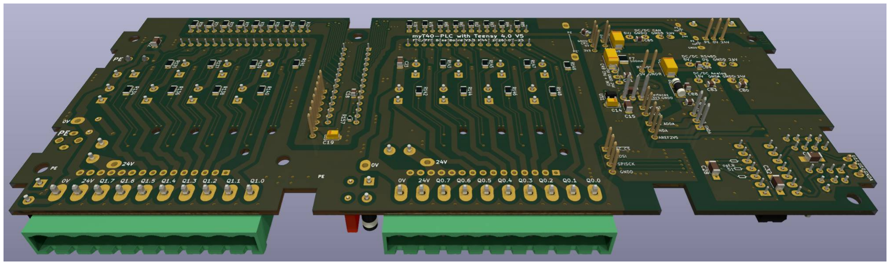
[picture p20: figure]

Die untere Pla5ne ist in beiden J3- Varianten, FFC und PFS, einsetzbar.

Alle PE-Kabel, die an der Steuerung angeschlossen werden, sollten an einem zentralen PE-Sternpunkt elektrisch verbunden werden. Das gilt auch für den einsei5g an PE aufzulegenden Schirm der Busleitungen an J6 und J7, falls vorhanden.

myT40-PLC C.Niesen CC-BY-NC-SA 2026 | 35

Abbildung 35: Unterpla&ne (UP) Oberseite , Beispiel mit op&onalen Terminals

Abbildung 36: Unterpla&ne (UP) Unterseite, Ein Beispiel

### 7.2 Die obere Pla1ne – CPU Board FFC

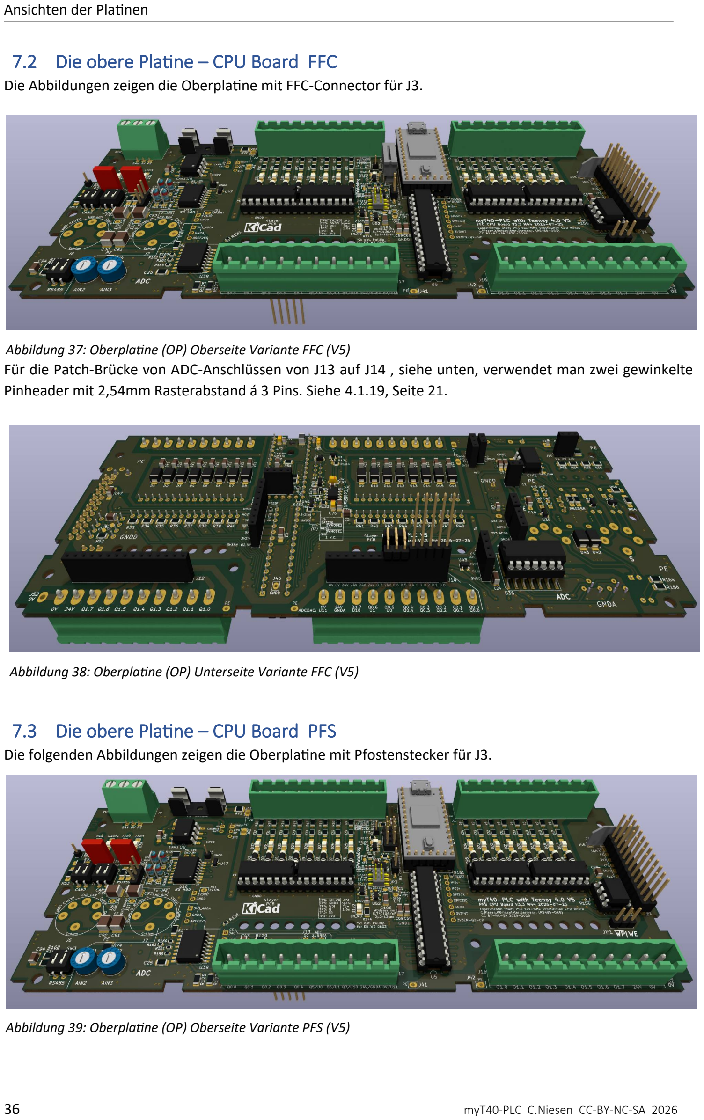
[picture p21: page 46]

Ansichten der Pla5nen

Die Abbildungen zeigen die Oberpla5ne mit FFC-Connector für J3.

Für die Patch-Brücke von ADC-Anschlüssen von J13 auf J14 , siehe unten, verwendet man zwei gewinkelte Pinheader mit 2,54mm Rasterabstand á 3 Pins. Siehe 4.1.19, Seite 21.

### 7.3 Die obere Pla1ne – CPU Board PFS

Die folgenden Abbildungen zeigen die Oberpla5ne mit Pfostenstecker für J3.

### 36 myT40-PLC C.Niesen CC-BY-NC-SA 2026

Abbildung 39: Oberpla&ne (OP) Oberseite Variante PFS (V5)

Abbildung 37: Oberpla&ne (OP) Oberseite Variante FFC (V5)

Abbildung 38: Oberpla&ne (OP) Unterseite Variante FFC (V5)

myT40-PLC Documenta5on

### 7.4 Allgemeine Informa1onen

Die Abmessungen aller Pla5nen beträgt 208mm x 80mm. Einige Bauteile stehen über den Pla5nenrand hinaus.

Bei der Wahl der Varianten für die Kommunika5onsbausteine und Isolator-ICs genügt die langsame Variante. Der SPI-Bus wird mit 1Mhz betrieben. Limi5erender Faktor sind hier der ADC und der DAC.

Aufgrund des Rou5ngs mit vielen Vias für die SPI/RS485/CAN-Signale und deren GNDx ist bei der Verwendung von schnellen ICs auf Grund der steileren Flanken eher mit EMV-Problemen zu rechnen als mit langsameren Bausteinen. Der EMV-E@ekt bei schnellen Bausteinen tri% auch bei niedrigen Takt-Frequenzen auf, wie sie hier genutzt werden, denn je schneller der Baustein, desto steiler die Signal-Flanken.

Für größere Bandbreiten und TakSrequenzen sind die SPI- und CAN-Signale samt ihren GNDx auf separaten Layern zu verlegen. Das wäre Teil eines zukünUigen Redesigns.

Aktuell reicht die Bandbreite aus, um in einer Millisekunde alle Eingänge zu lesen, die Daten innerhalb von wenigen Millisekunden zu verarbeiten und alle Ausgänge in einer weiteren Millisekunde zu setzen. Einen Schal5mpuls für 24V AC-“Eltakos“ mit exakt 5ms Länge lässt sich interruptgesteuert problemlos erzeugen, ebenso die Kommunika5on mit dem Controller und den benachbarten Steuerungen.

myT40-PLC C.Niesen CC-BY-NC-SA 2026 | 37

Abbildung 40: Oberpla&ne (OP) Unterseite Variante PFS (V5)

Ansichten der Pla5nen

### 38 myT40-PLC C.Niesen CC-BY-NC-SA 2026

### 7.5 Ansicht Oberpla1ne Variante OP-FFC für ein Originalgehäuse Rev3.3 M44 (V5)

myT40-PLC Documenta5on | Ansichten der Pla5nen

### 39 myT40-PLC C.Niesen CC-BY-NC-SA 2026

### 7.6 Ansicht der Oberpla1ne Variante OP-PFS für beliebige Gehäuse Rev3.3 M44 (V5)

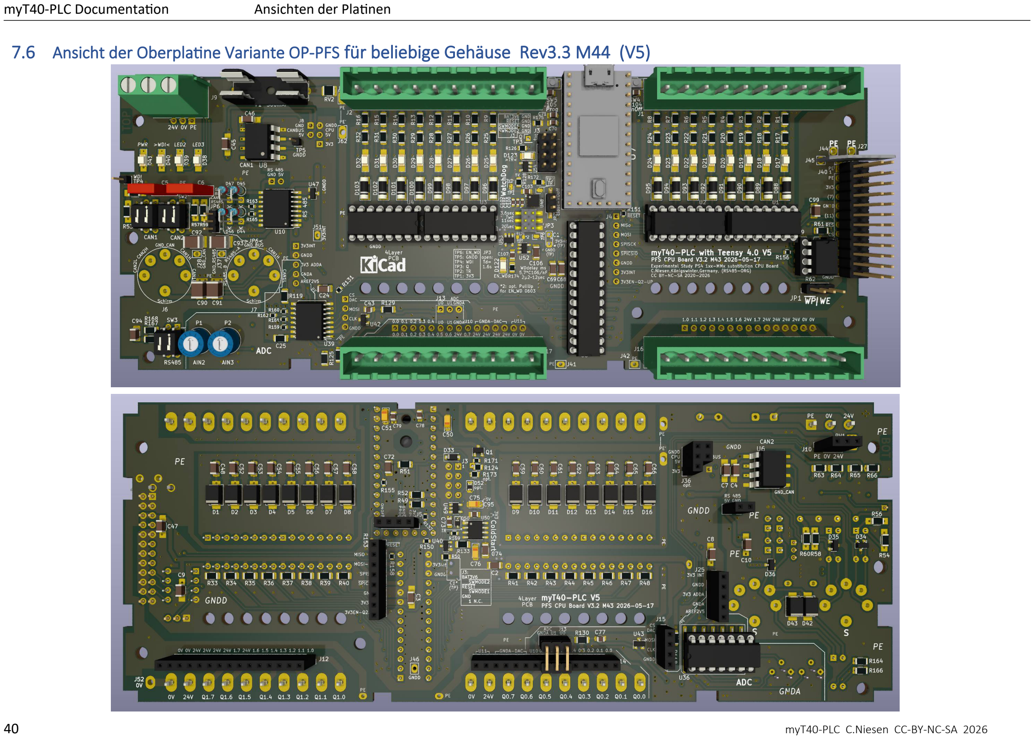
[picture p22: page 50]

myT40-PLC Documenta5on | Ansichten der Pla5nen

### 40 myT40-PLC C.Niesen CC-BY-NC-SA 2026

### 7.7 Ansicht Unterpla1ne für FFC und PFS V3.3 M44 (V5)

myT40-PLC Documenta5on | Ansichten der Pla5nen

### 41 myT40-PLC C.Niesen CC-BY-NC-SA 2026

myT40-PLC Documenta5on | Ansichten der Pla5nen

7.8

### 42 myT40-PLC C.Niesen CC-BY-NC-SA 2026

### 7.9 Pla1nen Layer Rev3.3 M44 V5 PFS

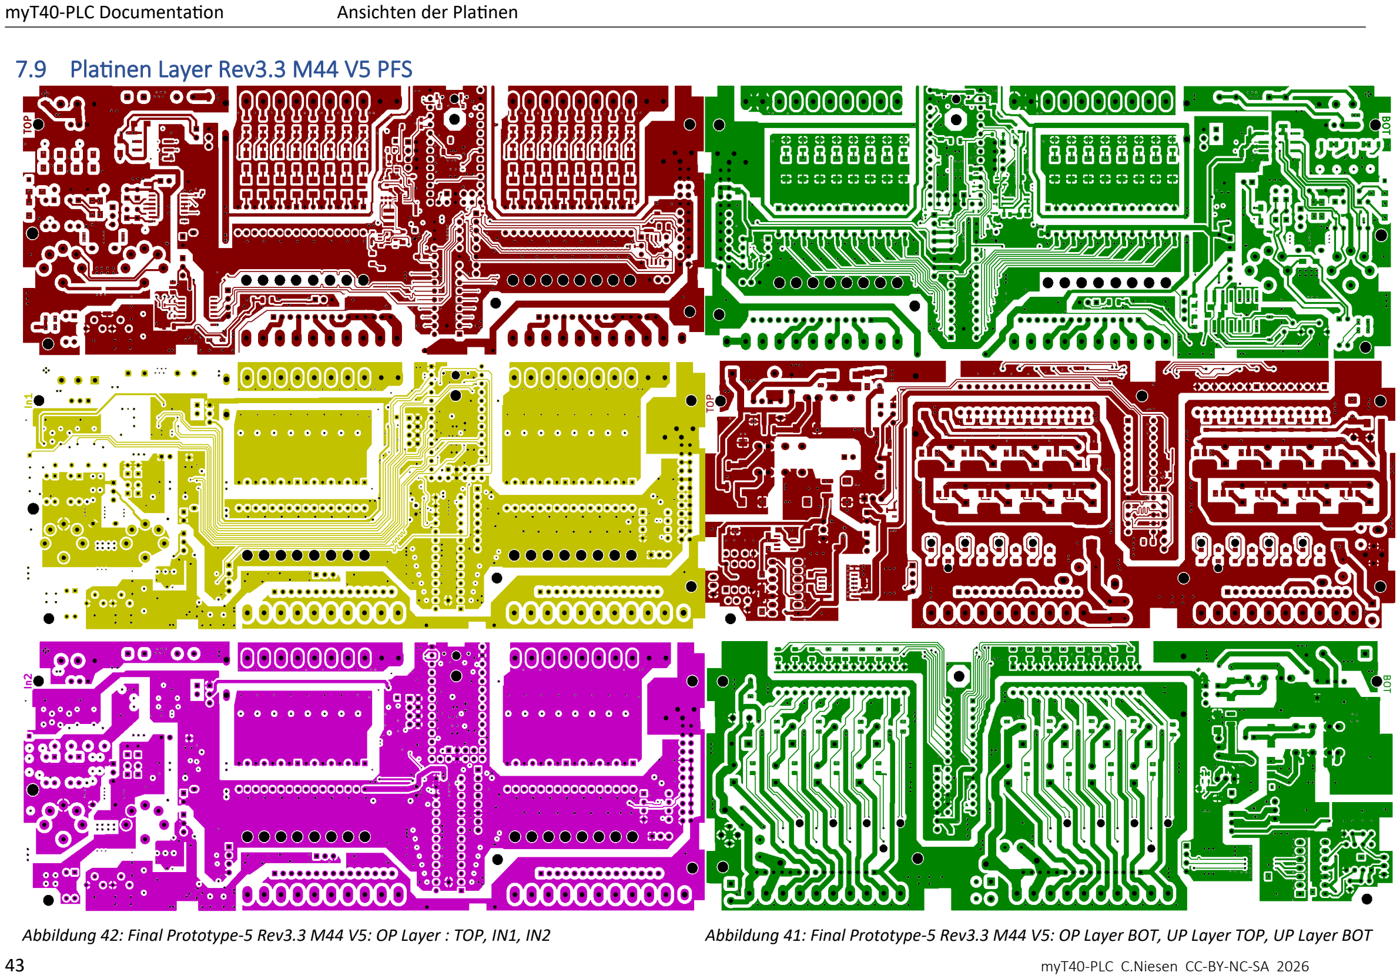
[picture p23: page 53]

myT40-PLC Documenta5on | Ansichten der Pla5nen

### 43 myT40-PLC C.Niesen CC-BY-NC-SA 2026

Abbildung 42: Final Prototype-5 Rev3.3 M44 V5: OP Layer : TOP, IN1, IN2 | Abbildung 41: Final Prototype-5 Rev3.3 M44 V5: OP Layer BOT, UP Layer TOP, UP Layer BOT

myT40-PLC Documenta5on Varianten zur Nutzung über alle Versionen

## 8 Varianten zur Nutzung über alle Versionen

### 8.1 Verdrahtung möglicher Varianten zur Nutzung wie im Originalgehäuse, V5 M44 (FFC)

### 8.1.1 2x8 Ausgänge, 2x8 Eingänge, kein ADC , kein DAC

Wenn man auf die Analoge Seite verzichten kann,
wird das Ausgangsterminal Byte-0 frei für alle 8
digitalen Ausgänge.

Es gibt Lötpads für die Brücken von 0V und 24V, die man bei Bedarf bestücken oder weglassen kann.

Wird die 24V Brücke eingelötet, muss auch die Brücke für 0V eingebaut werden.

Alterna5v und op5onal kann die 0V-Brücke auch ohne die 24V Brücke verwendet werden.

Die orange markierten Bereiche zeigen die Stellen, an denen Bauteile für die analoge Sek5on vorgesehen sind, sie enSallen in dieser Variante. Hier nicht zu sehen: die analoge Sek5on trägt auch auf der Unterseite der Pla5ne noch ein paar Bauteile, die ebenfalls enSallen können.

Zu beachten: In dieser Bestückung sind auf der die beiden in den runden, weißen Sockeln sitzenden Sicherungen mit jeweils 4 bis 5,6 A zu besetzen.
Ohne | Analog-Sek5on | kann | die | minimale
Versorgungsspannung an J9 von 18V auf 7-9V abgesenkt werden.

Zur Darstellung: die oben dargestellte Pla5ne ist
von unten zu sehen, die untere von oben, @ Seiten.

### 44 myT40-PLC C.Niesen CC-BY-NC-SA 2026

myT40-PLC Documenta5on Varianten zur Nutzung über alle Versionen

### 8.1.2 5+8 Ausgänge, 2x8 Eingänge, mit ADC , mit DAC

Diese Variante kommt dem Original am nächsten,
stellt zusätzlich einen zweiten DAC-Ausgang
bereit.

Hier enSallen die Anschlüsse am Byte-0 „Q0.5“, „Q0.6“, „Q0.7“,“24V“und „0V“.

Daher enSällt die Bestückung der betre@enden Ausgänge.

Wenn man sie dennoch bestückt, könnten die Leuchtdioden dieser Ausgänge noch als Status-Meldungen genutzt werden, s.o.

Die Stapelleisten werden für Byte-0 nur 5-polig
von | UP | zu | OP | eingebaut.
ADC wird im Raster 2,54/5,08 verbunden, DAC wird per einsei5g über PE abgeschirmtem Kabel z.B. per Stecker auf die Pinheader-Buchsen der Unterseite der OP gesteckt.

Zu beachten: in dieser Bestückung sind die auf
den | beiden | weißen | Sockeln | sitzenden
Sicherungen unterschiedlich zu besetzen: Byte-0 mit 2 bis 4A, Byte-1 mit 4 bis 5,6A.

Beide Brücken für „0V“ und „24V“ müssen in dieser Variante verlegt werden, damit enSällt in dieser Variante die Poten5altrennung von Ausgangsbyte-0 und Ausgangsbyte-1.

### 45 myT40-PLC C.Niesen CC-BY-NC-SA 2026

myT40-PLC Documenta5on Varianten zur Nutzung über alle Versionen

### 8.2 Verdrahtung möglicher Varianten zur Nutzung in einem beliebigen Gehäuse , V5 M44 PFS

### 8.2.1 OP für ADC und DAC auf 5-Pol Terminal, 2x8 In auf OP + 2x8 Out auf UP

Der Einsatz in einem beliebigen Gehäuse erlaubt
nicht nur alle Ein- und Ausgänge, digital und
analog zu verwenden, sondern auch mit der
Verwendung der Variante OP-PFS Jumper für alle 4 Kombina5onen von SW_MODE_x zu nutzen. Ferner wird man von der Verwendung der DIN-Buchsen befreit und kann für CAN und RS-485 die üblicherweise zu verwendenden Sub-D-Verbinder nutzen.
Auf | der | Unterpla5ne | können | Terminals
eingelötet werden, welches im rechten Winkel zur Pla5ne passende Stecker am Gehäuse zugänglich machen. Siehe Schaltplan.

Da meine ersten beiden Prototypen noch nicht in das Originalgehäuse passen, habe ich Gehäuse aus „Plexiglas GS“- Pla%en angefer5gt, Boden-, Ober- und die langen Seitenteile aus 4mm Material, die kleinen Seitenteile benö5gen eine Dicke, die die Gesamtbreite des Originals nicht überschreitet, dann passen die Steuerungen auch immer noch in eine Unterverteilung auf die Automatenschiene.

Beide Sicherungen mit 4 bis 5,6A.

Die Brücken sind op5onal.

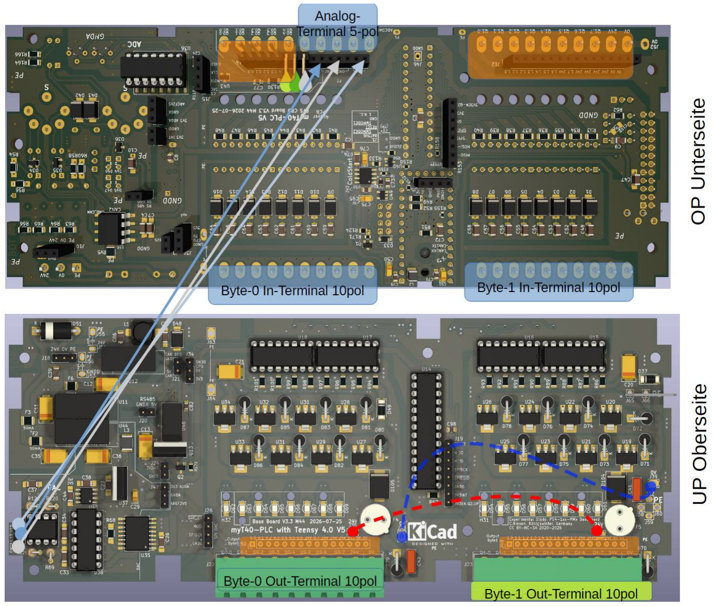
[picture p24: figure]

### 46 myT40-PLC C.Niesen CC-BY-NC-SA 2026

myT40-PLC Documenta5on Varianten zur Nutzung über alle Versionen

### 8.2.2 ADC und DAC auf 5-Pol Terminal, 2x8 In und 8 Out auf OP, 8 Out auf UP

Hier eine Mischbestückung für beliebige Gehäuse, die nur das Byte-0 auf direkten Zugang von der UP auf einen Wickelstecker legt, während das Byte-1 auf der OP zugänglich ist.

Beide Sicherungen mit 4 bis 5,6A.

Brücken op5onal.

### 47 myT40-PLC C.Niesen CC-BY-NC-SA 2026

myT40-PLC Documenta5on Varianten zur Nutzung über alle Versionen

### 8.3 PE Anschluss ab V2.6/3.0/3.1

Das Original-Gehäuse sieht für OP und UP je
einen PE-Anschluss über eine eingelötete Fahne (Flachstecker 6,3mm) an der rechten Schmalseite vor. Das Originalgehäuse stellt an diesen Stellen eine Verbindung nach außen zur geerdeten Automaten-Schiene her.

Dort abzuleitender Strom soll nicht über die gesamte Pla5ne Rießen. Daher ist am Lötpad
J61(OP) | und | J63(UP) | der | PE | der
Spannungsversorgung unterbrochen.

Beim Einbau in ein beliebiges Gehäuse muss darauf geachtet werden, entweder den ungekürzten Flachstecker passend mit PE zu verbinden, oder diese PE-Brücken A (J61-J62) und B (J63-J64) mit einer Kabelbrücke 1mm² zu schließen. Beides gleichzei5g ist zu
vermeiden, | da | PE | auch | über | Das
Versorgungsterminal | J9 | angeschlossen
werden muss.

Die beiden Flachstecker auf OP und UP bieten
allerdings | besseren | Kontakt | zu | PE.
Daher ist die Empfehlung, die Brücke A und B nicht zu setzen und den PE-Anschluss J9, sowie die Flachstecker zu nutzen.

Ab V3 wurde die Posi5on der Flachstecker für PE op5miert. Auf der OP+UP gibt es nun eine Einbauop5on der PE-Flachstecker-Fahne, die
einen | ungekürzten | Einbau | in | das
Originalgehäuse erlaubt.

### 48 myT40-PLC C.Niesen CC-BY-NC-SA 2026

myT40-PLC Documenta5on | Anhang

## 9 Anhang

### 9.1 Op1onale Nutzung von Q0.5, Q0.6 und Q0.7 als Status-LED

In der Variante mit Analog als 5/8 Digital-Out sind die Ausgänge Q0.5, Q0.6 und Q0.7 nicht nutzbar. Mit der folgenden Anpassung können D67, D68, D69 jedoch als Status-LED genutzt werden. Es emp4elt sich hier eine andere Farbe. Ich habe Orange gewählt, weil Strom und Spannungsabfall bei ähnlicher Helligkeit vergleichbar zu den roten LEDs sind.

Mit der FFC-Version V5 M44 Rev3.3 wurden die Ausgangs-LED wieder hinter die Optokoppler gesetzt.

Bei Verwendung der Ausgänge Q0.7, Q0.6 und Q0.5 als Status-LED enSallen die BSP-452 U27, U28, U29.

Da dieser einen Innenwiderstand am Eingang von ca. 2800 Ohm besitzt, müssen die Widerstände R142-R144 durch 750 Ohm ersetzt werden, damit etwa 2,5mA bei ca. 24V Rießen können.

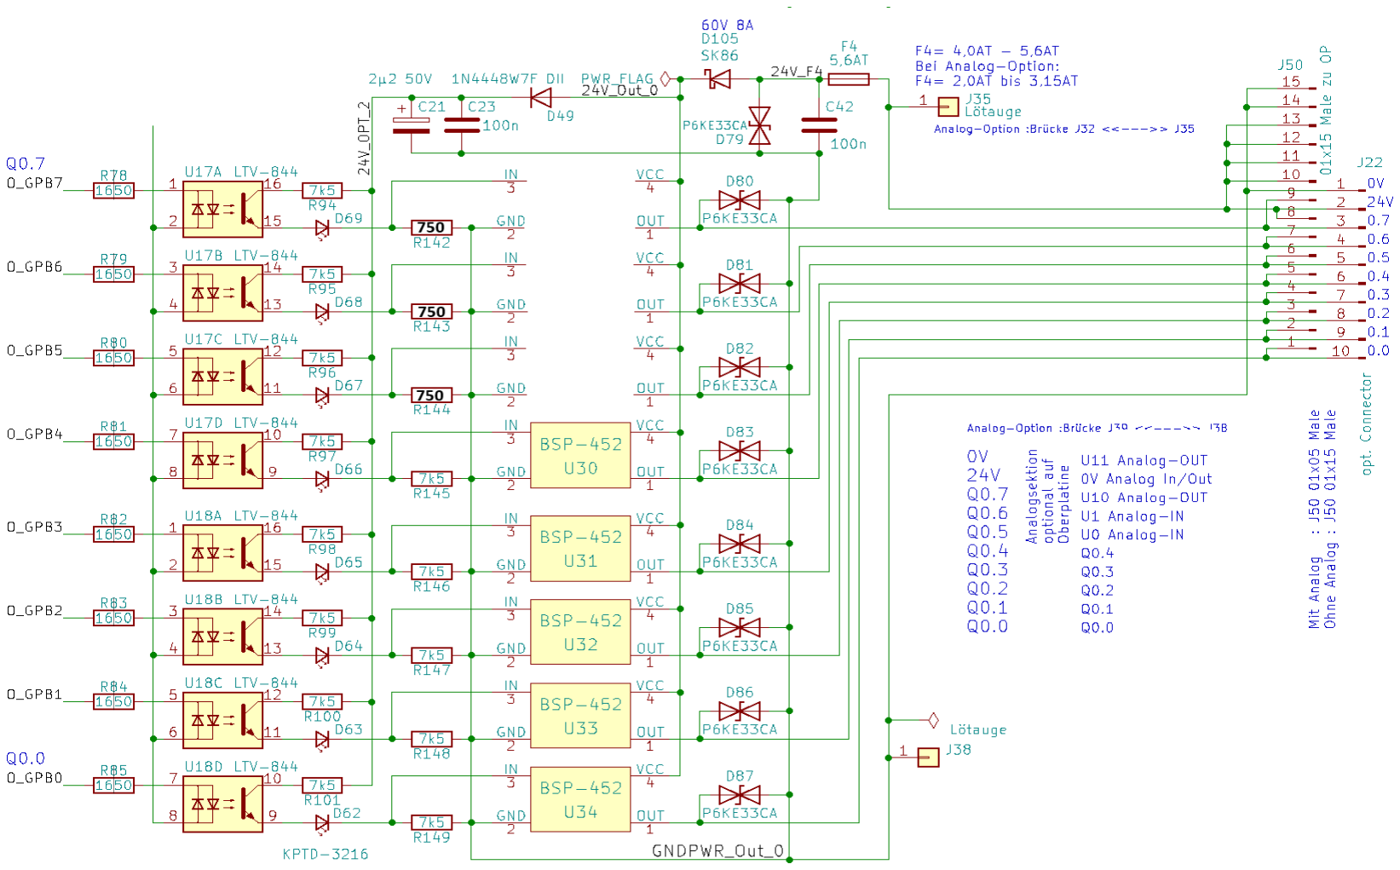
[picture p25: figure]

### 49 myT40-PLC C.Niesen CC-BY-NC-SA 2025

Abbildung 43: Alterna&ve Status-LED Verdrahtung FFC/PFS Rev-3.3 M44 V5

Anhang

### 9.2 Technische Daten

Spannungsversorgung
CPU

24V DC, 30-120mA,
Absicherung F 500mA

Minimal 9V ohne ADC oder DAC
Minimal 18V mit ADC und DAC
Maximal 25,6V (bes5mmt durch TVS Diode D51)

Eingangsspannungen
Digital
24V DC (bis 33V) | Minimal 20V
Maximal 50V bei 500mW Verlustleistung der Eingangswiderstände R1-R16

Ausgangsspannung
Digital

24V DC, 500mA je Kanal

Verpolungsschutzdiode 24V
8A / Byte

500mA max

Maximal 40V (BSP-452)

Maximal 47V (BTS 4141N)

D70 bis D87 bes5mmen Maximalspannung mit 33V

Analoger Eingang | 0...10V DC
120k Eingangswiderstand
> 100pF Kapazität

realisiert mit MCP3208, ADuM1401xRW

Analoger Ausgang | 0...10V DC | realisiert mit MCP4922, LT1078, ADuM1401xRW
CAN-Bus | 5V | Terminierung mit 120Ω, zuschaltbar, realisiert mit ISO-1050
RS485 | 5V | Terminierung mit Dioden, UF<=0,25V, permanent, 16 Teilnehmer, 120Ω op5onal, realisiert mit ADM2483xRW
Pu@erba%erie Real5me Clock | 3,6V Lithium bedrahtet, oder Knopfzelle 3V | Bei Verwendung in Alterna5vgehäuse und Knopfzelle 3V wird D33 durch eine Brücke ersetzt. Sie reduziert die 3,6V der Lithium- Ba%erie auf 3V der CPU
CPU | Teensy 4.0 | CPU gesockelt •ARM Cortex-M7 at 600 MHz •Float point math unit, 64 & 32 bits •1984K Flash, 1024K RAM (512K 5ghtly coupled), 1K EEPROM (emulated) •USB device 480 Mbit/sec & USB host 480 Mbit/sec •40 digital input/output pins, 31 PWM output pins •14 analog input pins •7 serial, 3 SPI, 3 I2C ports •2 I2S/TDM and 1 S/PDIF digital audio port •3 CAN Bus (1 with CAN FD) •32 general purpose DMA channels
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

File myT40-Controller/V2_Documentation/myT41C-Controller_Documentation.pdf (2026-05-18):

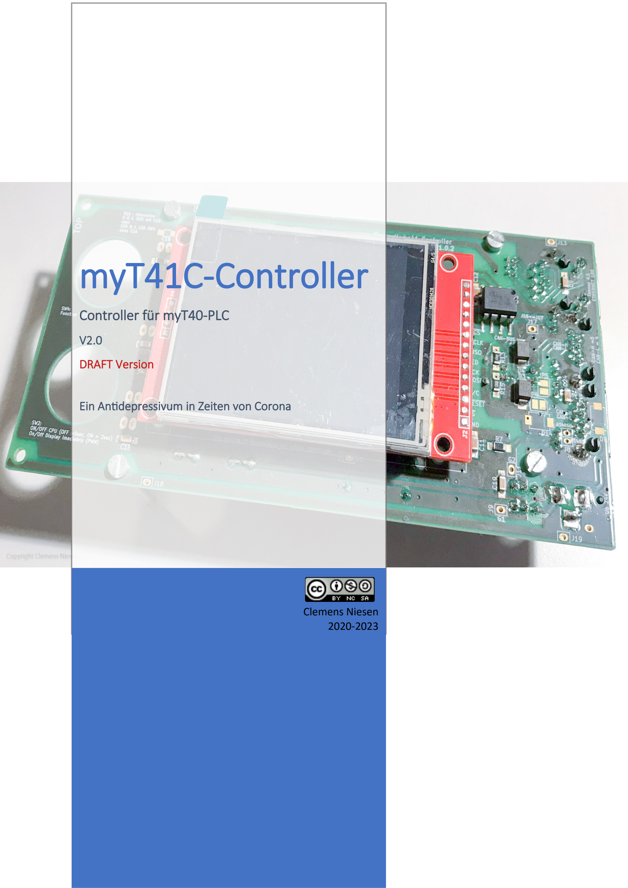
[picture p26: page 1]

# myT41C-Controller

### Controller für myT40-PLC

V2.0
DRAFT Version

Ein Antidepressivum in Zeiten von Corona

Clemens Niesen
2020-2023

myT41C-Controller | History
Version 0.1 | ab Mai 2018 | Gedankenspiele | mit | Arduino | Due
Ausprobieren von KiCad 4.x
Version 1.0 | 1.12.2020 | Steckbrett-Aufbauten mit Teensy 4.0 und 4.1
Version 1.2.1 22.4.2021 | myT41C Controller | V1.0.2 Produziert | (Prototyp1)
Version 2.6 | 10.08.2023 | myT41C Controller M8 V2.0 | | (Prototyp | Final)

Projekt umbenannt in myT40-... im August 2023

Königswinter, Germany, im August 2023

Preliminary Version: I have to think about alternative displays ...

ii
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

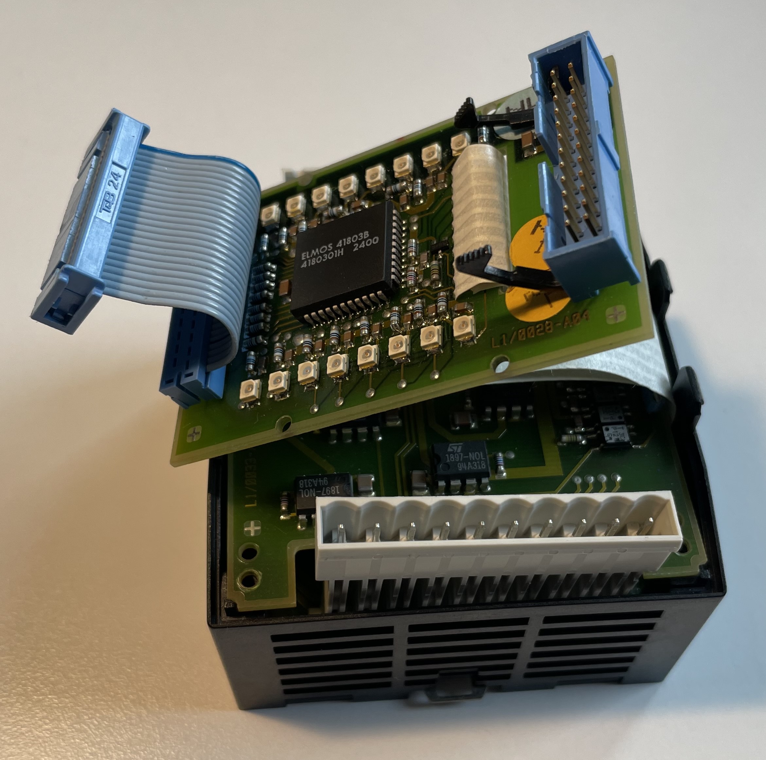
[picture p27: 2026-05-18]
myT40-EXT-116-XD1/Pictures/LE-116-XD1_Original.jpg

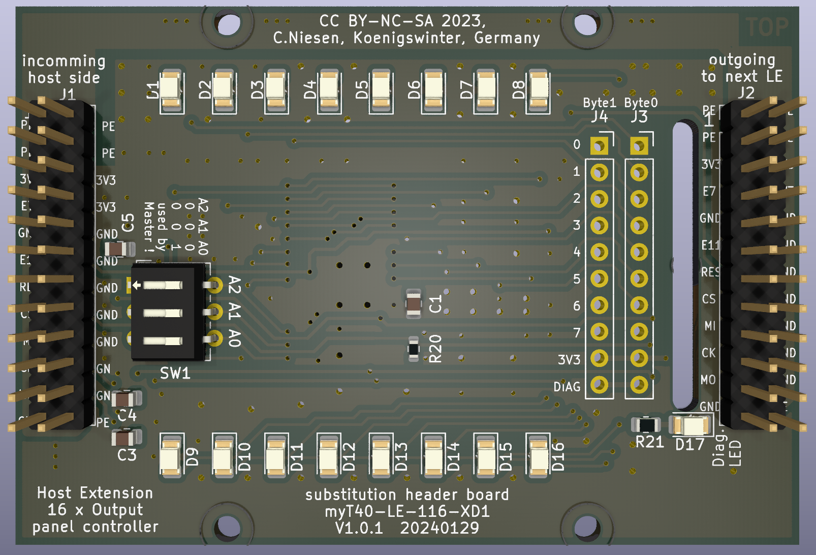
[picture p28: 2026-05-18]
myT40-EXT-116-XD1/Pictures/myT40-EXT-116-XD1_1.1_M1_TOP.png

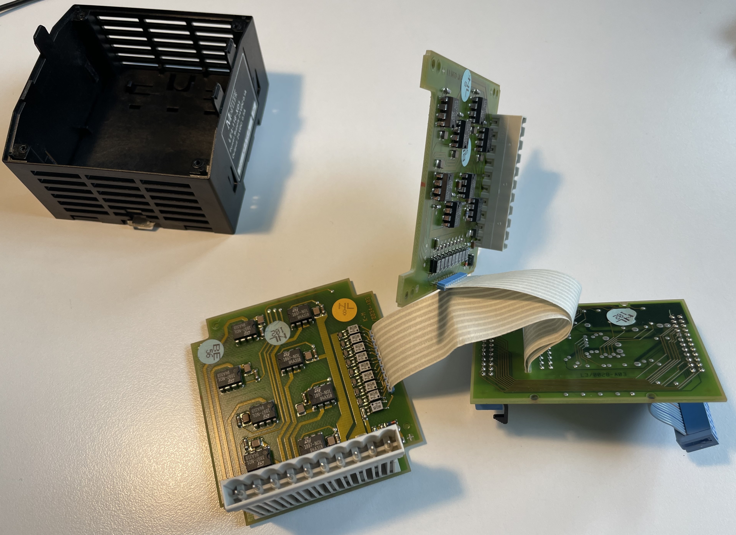
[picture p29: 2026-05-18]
myT40-EXT-116-XD1/Pictures/LE-116-XD1_Original_zerlegt.jpg

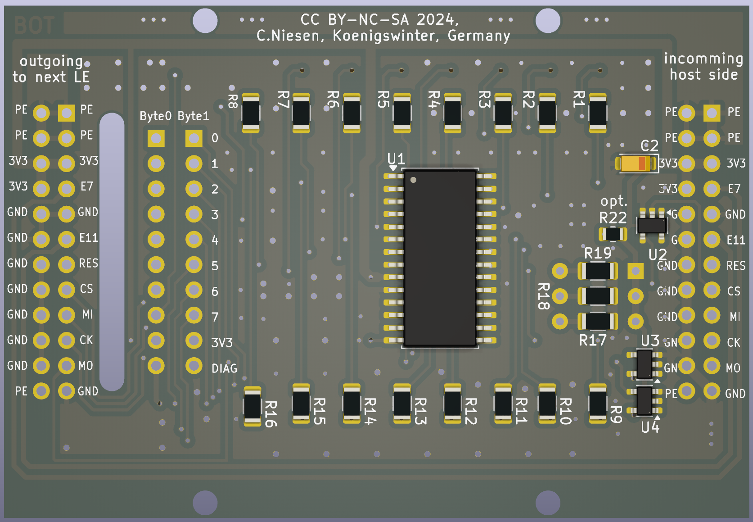
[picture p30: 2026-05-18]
myT40-EXT-116-XD1/Pictures/myT40-EXT-116-XD1_1.1_M1_BOT.png

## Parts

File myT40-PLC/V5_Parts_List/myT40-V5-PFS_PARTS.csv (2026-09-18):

Reference | Value | Datasheet | Footprint | Qty | DNP | Bezug
A1 | KiCad Symbol |  | Symbol:KiCad-Logo2_6mm_SilkScreen | 1
A2 | KiCad-Symbol |  | Symbol:KiCad-Logo_5mm_SilkScreen | 1
C1 | Siehe Text | ~ | Capacitor_Tantalum_SMD:CP_EIA-3216-18_Kemet-A | 1 | Nicht bestücken | https://www.reichelt.de/smd-tantal-100-f-10-6-3v-case-b-125-c-ve-2000-t491b-100u-6-p206458.html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
C2,C22,C23,C24,C25,C48,C52,C53,C54,C55,C56,C57,C58,C59,C60,C61,C62,C63,C64,C65,C66,C67,C68,C69,C72,C86,C97,C98,C99 | 100n | https://www.reichelt.de/index.html?ACTION=446&LA=3&nbc=1&q=kem%20x7r1206b100n,~ | Capacitor_SMD:C_1206_3216Metric | 29 |  | https://www.reichelt.de/vielschicht-kerko-100nf-50v-125-c-kem-x7r1206b100n-p207152.html?trstct=pol_1&nbc=1
C3,C4,C7,C8,C9,C10,C26,C27,C28,C30,C31,C32,C33,C34,C37,C38,C40,C44,C47,C87 | 100n | https://www.reichelt.de/index.html?ACTION=446&LA=3&nbc=1&q=kem%20x7r1206b100n,~ | myLib9:C_1206_HandSoldering | 20 |  | https://www.reichelt.de/vielschicht-kerko-100nf-50v-125-c-kem-x7r1206b100n-p207152.html?trstct=pol_1&nbc=1
C5,C6 | 4n7 | https://www.reichelt.de/keramik-kondensator-500v-4-7n-kerko-500-4-7n-p9340.html?&trstct=pol_1&nbc=1 | Capacitor_THT:C_Rect_L7.0mm_W2.5mm_P5.00mm | 2 |  | https://www.reichelt.de/keramik-kondensator-500v-4-7n-kerko-500-4-7n-p9340.html?&trstct=pol_1&nbc=1
C11,C12,C13,C35 | 10µ 50V | https://www.reichelt.de/smd-tantal-10-f-50v-125-c-t491d-10u-50-p206482.html?&trstct=pol_0&nbc=1 | Capacitor_Tantalum_SMD:CP_EIA-7343-31_Kemet-D | 4 |  | https://www.reichelt.de/smd-tantal-10-f-50v-125-c-t491d-10u-50-p206482.html?&trstct=pol_0&nbc=1
C14 | 22µ 6V3 | https://www.reichelt.de/smd-tantal-22-f-6-3v-105-c-t520-22u-6-3-p206543.html?&trstct=pol_9&nbc=1 | Capacitor_Tantalum_SMD:CP_EIA-3216-18_Kemet-A | 1 |  | https://www.reichelt.de/smd-tantal-22-f-6-3v-105-c-t520-22u-6-3-p206543.html?&trstct=pol_1&nbc=1
C15,C39 | 100n 50V |  | Capacitor_SMD:C_1206_3216Metric | 2 |  | https://www.reichelt.de/vielschicht-kerko-100nf-50v-125-c-kem-x7r1206b100n-p207152.html?trstct=pol_1&nbc=1
C16,C17,C49 | 22µ 10V | https://cdn-reichelt.de/documents/datenblatt/B300/KEM_T520_DB-EN.pdf,https://www.reichelt.de/smd-tantal-22-f-10v-125-c-t491c-22u-10-p206472.html?trstct=pol_0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 | Capacitor_Tantalum_SMD:CP_EIA-6032-28_Kemet-C | 3 |  | https://www.reichelt.de/smd-tantal-22-f-10v-125-c-t491c-22u-10-p206472.html?&trstct=pol_0&nbc=1
C18,C70,C71,C73,C75,C96,C103,C104,C105,C107 | 100n | https://www.reichelt.de/index.html?ACTION=7&LA=3&OPEN=0&INDEX=0&FILENAME=B300%2FKEM_C0XXX_X7R_DB-EN.pdf,~ | myLib9:C_0805 | 10 |  | https://www.reichelt.de/vielschicht-kerko-100nf-50v-125-c-kem-x7r0805-100n-p207073.html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
C19 | 2µ2 16V | https://cdn-reichelt.de/documents/datenblatt/B300/KEM_T494_DB-EN.pdf | Capacitor_Tantalum_SMD:CP_EIA-3216-18_Kemet-A | 1 |  | https://www.reichelt.de/smd-tantal-2-2-f-16v-125-c-t494a-2-2u-16-p206498.html?&trstct=pol_0&nbc=1
C20,C21 | 2µ2 50V |  | Capacitor_Tantalum_SMD:CP_EIA-7343-31_Kemet-D | 2 |  | https://www.reichelt.de/smd-tantal-kondensator-2-2-f-50-v-taj-7343-2-2-50-p167031.html?trstct=pol_3&nbc=1
C29,C76,C95 | 10µ 10V | https://www.reichelt.de/index.html?ACTION=7&LA=3&OPEN=0&INDEX=0&FILENAME=A900%2FAVX_TPS_DS.pdf,~ | Capacitor_Tantalum_SMD:CP_EIA-3216-18_Kemet-A | 3 |  | https://www.reichelt.de/smd-tantal-kondensator-10-f-10v-tps-3216-10-10-p167046.html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
C36 | 22µ 25V | https://www.reichelt.de/smd-tantal-22-f-25v-125-c-t494d-22u-25-p206522.html?&trstct=pol_0&nbc=1 | Capacitor_Tantalum_SMD:CP_EIA-7343-31_Kemet-D | 1 |  | https://www.reichelt.de/smd-tantal-22-f-25v-125-c-t495d-22u-25-p206534.html?&trstct=pol_1&nbc=1
C41,C42 | 100n |  | Capacitor_THT:C_Rect_L7.0mm_W2.5mm_P5.00mm | 2 |  | https://www.reichelt.de/folienkondensator-100nf-250v-rm5-mks2-250-100n-p172708.html?trstct=pol_1&nbc=1
C43,C77 | 100p | ~ | myLib9:C_0805 | 2 |  | https://www.reichelt.de/vielschicht-kerko-100pf-50v-125-c-kem-c0g0805-100p-p207035.html?trstct=pol_1&nbc=1
C45,C46 | 100n 100V |  | myLib9:C_1206_HandSoldering | 2 |  | https://www.reichelt.de/vielschicht-kerko-100nf-100v-125-c-kem-x7r1206a100n-p207151.html?trstct=pol_1&nbc=1
C50,C51 | 4µ7 16V | https://www.reichelt.de/index.html?ACTION=7&LA=3&OPEN=0&INDEX=0&FILENAME=B300%2FKEM_T494_DB-EN.pdf | Capacitor_Tantalum_SMD:CP_EIA-3216-18_Kemet-A | 2 |  | https://www.reichelt.de/smd-tantal-4-7-f-16v-125-c-t494a-4-7u-16-p206500.html?&trstct=pol_0&nbc=1
C74 | 10n | ~ | Capacitor_SMD:C_1206_3216Metric | 1 |  | https://www.reichelt.de/vielschicht-kerko-1206-10-nf-10-x7r-50-v-125-c-kem-x7r1206b10n-p207144.html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
C78,C79 | 2,2pF | ~ | myLib9:C_0805 | 2 |  | https://www.reichelt.de/smd-vielschicht-0805-2-2-pf-cog--0-25pf-50v-125-c-npo-g0805-2-2p-p13515.html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
C80,C81,C82,C83,C84,C85,C88,C89 | 100n 50V | https://www.reichelt.de/index.html?ACTION=7&LA=3&OPEN=0&INDEX=0&FILENAME=B300%2FKEM_C0XXX_X7R_DB-EN.pdf | myLib9:C_0805 | 8 |  | https://www.reichelt.de/vielschicht-kerko-100nf-50v-125-c-kem-x7r0805-100n-p207073.html?trstct=pol_1&nbc=1
C90,C91,C92,C93 | 220n 250V | ~ | myLib9:C_1812 | 4 |  | https://www.mouser.de/ProductDetail/KEMET/C1812C224KARACTU?qs=yb5u%2FZTDO8t0HeaPboTl3w%3D%3D
C94 | 220p 50V |  | Capacitor_SMD:C_1206_3216Metric | 1 |  | https://www.reichelt.de/smd-vielschicht-keramikkondensator-220p-5--npo-g1206-220p-p31890.html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
C100 | 47n | ~ | myLib9:C_0603 | 1 |  | https://www.mouser.de/ProductDetail/KEMET/C0805C153K8RACTU?qs=N1pDVoEwhSEBdRtExVr9Dw%3D%3D
C101 | 150n | ~ | myLib9:C_0603 | 1 |  | https://www.mouser.de/ProductDetail/Walsin/0805B154K100CT?qs=ZrPdAQfJ6DNb5fmyFs989Q%3D%3D
C102 | 270n | ~ | myLib9:C_0603 | 1 |  | https://www.mouser.de/ProductDetail/KEMET/C0805C105J8RACTU?qs=bVy%252B2zX3BtIPanWpdNGpuQ%3D%3D
C106 | 2µ2 | https://cdn-reichelt.de/documents/datenblatt/B300/NTS-NTF-SERIAL.pdf | Capacitor_SMD:C_1206_3216Metric | 1 |  | https://www.reichelt.de/de/de/shop/produkt/smd-vielschicht_1206_2_2_f_x7r_10_25_v_125_c-256470
D1,D2,D3,D4,D5,D6,D7,D8,D9,D10,D11,D12,D13,D14,D15,D16 | P6SMB 5,0CA SMD | https://cdn-reichelt.de/documents/datenblatt/A400/SMBJ_LITTELFUSE_DATASHEET.pdf | myLib9:DO-214AA_man | 16 |  | https://www.reichelt.de/tvs-diode-bidirectional-5-v-600-w-do-214aa-smb-p6smb-5-0ca-smd-p204337.html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
D17,D18,D19,D20,D21,D22,D23,D24,D25,D26,D27,D28,D29,D30,D31,D32,D38,D39,D40,D41 | APTD3216 | https://www.mouser.de/ProductDetail/Kingbright/APTD3216LSURCK?qs=AQlKX63v8RsLPrrQ1%252BPtxg%3D%3D | myLib9:LED_1206_HandSoldering | 20 |  | https://www.mouser.de/ProductDetail/Kingbright/APTD3216LSURCK?qs=AQlKX63v8RsLPrrQ1%252BPtxg==
D33 | 1N4448W7F DII | https://www.reichelt.de/index.html?ACTION=7&LA=3&OPEN=0&INDEX=0&FILENAME=A400%2F1N4448W_ENG_TDS.pdf | Diode_SMD:D_SOD-123 | 1 |  | https://www.reichelt.de/gleichrichterdiode-75-v-0-5-a-sod-123-1n-4448w7f-dii-p219387.html?search=1N4448
D34,D35,D36 | SZNUP2105LT1G | https://www.mouser.de/datasheet/2/308/1/NUP2105L_D-2319421.pdf | myLib9:SOT-23 | 3 |  | https://www.mouser.de/ProductDetail/onsemi/SZNUP2105LT1G?qs=PJJcWtbOkNWqqZbXH80dfQ%3D%3D
D37,D49,D88,D89,D90,D91,D92,D93,D94,D95,D96,D97,D98,D99,D100,D101,D102,D103,D106,D107,D108,D109,D110,D111,D112,D113,D114,D115,D116,D117,D118,D119,D120,D121 | 1N4448W7F DII | http://www.vishay.com/docs/88503/1n4001.pdf,https://cdn-reichelt.de/documents/datenblatt/A400/1N4448W_ENG_TDS.pdf | myLib9:Diode_DO213AB-MELF_SOD123 | 34 |  | https://www.reichelt.de/gleichrichterdiode-75-v-0-5-a-sod-123-1n-4448w7f-dii-p219387.html?search=1N4448
D42,D43 | P6SMB 5,0CA |  | myLib9:DO-214AA_man | 2 |  | https://www.reichelt.de/tvs-diode-bidirectional-5-v-600-w-do-214aa-smb-p6smb-5-0ca-smd-p204337.html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
D44,D45,D46,D47 | BAT 46 | ~ | Diode_THT:D_DO-35_SOD27_P2.54mm_Vertical_KathodeUp | 4 |  | https://www.reichelt.de/kleinsignal-schottky-diode-100-v-150-ma-do-35-bat-46-p4853.html?search=BAT+46
D48 | MBRS 1100 SMD | https://www.reichelt.de/schottkydiode-100-v-1-a-do-214aa-mbrs-1100-smd-p41974.html?trstct=pos_8&nbc=1 | myLib9:DO-214AA_Schottky_man | 1 |  | https://www.reichelt.de/schottkydiode-100-v-1-a-do-214aa-mbrs-1100-smd-p41974.html?trstct=pos_8&nbc=1
D50 | RB751V40T1G | https://www.onsemi.com/download/data-sheet/pdf/rb751v40t1-d.pdf | Diode_SMD:D_SOD-323 | 1 |  | https://www.mouser.de/ProductDetail/onsemi/NSVRB751V40T1G?qs=dbuNSGnowt2jW1ha4241mA%3D%3D
D51 | 1.5KE27CA |  | Diode_THT:D_DO-201_P12.70mm_Horizontal | 1 |  | https://www.reichelt.de/tvs-diode-bidirektional-30-v-1500-w-do-201-1-5ke30ca-tsc-p278107.html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
D53 | 1N4007 SMD | http://www.vishay.com/docs/88503/1n4001.pdf | myLib9:Diode_DO213AB-MELF_SOD123 | 1 |  | https://www.reichelt.de/gleichrichterdiode-1000-v-1-a-do-41-1n-4007-p1729.html?search=1N4007
D54,D55,D56,D57,D58,D59,D60,D61,D62,D63,D64,D65,D66,D67,D68,D69 | KPTD-3216 | https://cdn-reichelt.de/documents/datenblatt/A500/SMD-LED1206K-RT%23KIN.pdf | myLib9:D_1206_4.5 | 16 |  | https://www.reichelt.de/led-smd-3216-1206-rot-600-mcd-50--smd-led-1206k-rt-p54085.html?&nbc=1
D70,D71,D72,D73,D74,D75,D76,D77,D78,D79,D80,D81,D82,D83,D84,D85,D86,D87 | P6KE33CA |  | Diode_THT:D_DO-15_P5.08mm_Vertical_KathodeUp | 18 |  | https://www.reichelt.de/tvs-diode-bidirectional-33-v-600-w-do-204ac-do-15-p6ke-33ca-p42020.html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
D104,D105 | SK86 | https://cdn-reichelt.de/documents/datenblatt/A400/SK82-810_GER-ENG_TDS.pdf | Diode_SMD:D_SMC | 2 |  | https://www.reichelt.de/schottkydiode-60-v-8-a-do-214ab-sk-86-dio-p216773.html?&trstct=pol_3&nbc=1
D122,D123 | APTD3216 | https://www.mouser.de/ProductDetail/Kingbright/APTD3216LSURCK?qs=AQlKX63v8RsLPrrQ1%252BPtxg%3D%3D | myLib9:LED_1206_3216_big-gap | 2 |  | https://www.mouser.de/ProductDetail/Kingbright/APTD3216LSURCK?qs=AQlKX63v8RsLPrrQ1%252BPtxg==
F1 | 500mA F | https://www.conrad.de/de/p/eska-120-800h-sicherungs-haltefeder-passend-fuer-feinsicherung-5-x-20-mm-6-3-a-250-v-ac-1-st-533920.html | Fuse:Fuseholder_Clip-5x20mm_Littelfuse_111_Inline_P20.00x5.00mm_D1.05mm_Horizontal | 1 |  | https://www.reichelt.de/sicherungshalter-fuer-5-x-20-mm-10-a-litt-04450001n-p242453.html?trstct=pos_8&nbc=1
F2,F3,F6 | 50mA | https://www.reichelt.de/index.html?ACTION=7&LA=3&OPEN=0&INDEX=0 | Resistor_SMD:R_1210_3225Metric | 3 |  | https://www.reichelt.de/ptc-sicherung-smd-1210-60v-50ma-rueckstellend-ptc-fsmd0051210-p279326.html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
F4,F5 | 5,6AT |  | myLib9:Sockel_Kleinst-F | 2 |  | https://www.reichelt.de/sicherungshalter-fuer-kleinstsicherungen-pl-166600-p17544.html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
F7 | 100mA | https://www.reichelt.de/index.html?ACTION=7&LA=3&OPEN=0&INDEX=0 | Resistor_SMD:R_1210_3225Metric | 1 |  | https://www.reichelt.de/ptc-sicherung-smd-1210-60v-100ma-rueckstellend-ptc-fsmd0101210-p279329.html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
H1 | MH2,5 | ~ | myLib9:Hole_2,5mm | 1
H2 | MH3,5 | ~ | myLib9:Hole_3,5mm | 1
H3,H4,H5,H6,H7,H8,H25,H26,H27,H28,H29,H30 | MountingHole | ~ | MountingHole:MountingHole_3.2mm_M3 | 12
H9,H10,H11,H12,H13,H14,H15,H16,H17,H18,H19,H20,H21,H22,H23,H24 | LED3.2mm | ~ | myLib9:Hole_3.2mm | 16
H31,H32 | LED-Licht-Leiter_8x3mm_P5.08 |  | myLib9:MEN-LED-Lichtleiter_8x3mm_P5.08_5v8 | 2 |  | https://www.reichelt.de/lichtleiter-1x10-fach-3-mm-planar-gerade-men-12721020-p232146.html?search=MEN+12721020
J1,J2,J16,J17 | MSTBVA-2.5-10-5.08 | ~ | myLib9:TerminalBlock_Phoenix_MSTBVA-2.5-10-5.08_1x10_P5.08mm_Horizontal | 4 |  | https://www.mouser.de/ProductDetail/Phoenix-Contact/1924389
J3 | Conn_02x04_Odd_Even | ~ | Connector_PinHeader_2.54mm:PinHeader_2x04_P2.54mm_Vertical | 1
J4 | 01x08_fem | ~ | Connector_PinSocket_2.54mm:PinSocket_1x08_P2.54mm_Vertical | 1 |  | https://www.reichelt.de/buchsenleiste-2-54mm-1x8-gerade-bkl-10120949-p266674.html?trstct=pol_4&nbc=1
J5,J15 | 01x04_fem | ~ | Connector_PinSocket_2.54mm:PinSocket_1x04_P2.54mm_Vertical | 2 |  | https://www.reichelt.de/buchsenleiste-2-54mm-1x4-gerade-bkl-10120946-p266671.html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
J6,J7 | DIN-5 | Werner Elektronik | myLib9:DIN-5-180 | 2 |  | https://www.ebay.de/itm/132535527872
J8 | 02x02_fem | ~ | Connector_PinSocket_2.54mm:PinSocket_2x02_P2.54mm_Vertical | 1 |  | https://www.reichelt.de/buchsenleiste-2-54mm-1x2-gerade-bkl-10120944-p266669.html?trstct=vrt_pdn&nbc=1
J9 | Ub 0V PE | F:\Daten\ProgrammData\KiCad-Projects\datasheet\PhoenixContact_1715857_02_MKDS-1-5-3-5-08-BD-1-3_FAM.pdf | myLib9:TerminalBlock_Phoenix_MKDS-1,5-3-5.08_1x03_P5.08mm_Horizontal | 1 |  | https://www.reichelt.de/anschlussklemme-3-pol-rm-5-08-mm-90--lakl-1-5-3-5-08-p169872.html?search=1729131
J10,J13 | 01x03_fem | ~ | Connector_PinSocket_2.54mm:PinSocket_1x03_P2.54mm_Vertical | 2 |  | https://www.reichelt.de/buchsenleiste-2-54mm-1x3-gerade-bkl-10120945-p266670.html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
J11 | 01x02_fem | ~ | Connector_PinSocket_2.54mm:PinSocket_1x02_P2.54mm_Vertical | 1 |  | https://www.reichelt.de/buchsenleiste-2-54mm-1x2-gerade-bkl-10120944-p266669.html?trstct=vrt_pdn&nbc=1
J12,J14 | 01x15_fem | ~ | Connector_PinSocket_2.54mm:PinSocket_1x15_P2.54mm_Vertical | 2 |  | https://www.reichelt.de/platinensteckverbinder-gerade-weiss-10-polig-ps-25-10g-ws-p14824.html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
J18 | 01x03_Male | ~ | Connector_PinHeader_2.54mm:PinHeader_1x03_P2.54mm_Vertical | 1 |  | https://www.reichelt.de/stiftleiste-3-pol-gerade-rm-2-54-mpe-089-1-003-p225881.html?trstct=vrt_pdn&nbc=1
J19 | 01x08_Male | ~ | Connector_PinHeader_2.54mm:PinHeader_1x08_P2.54mm_Vertical | 1 |  | https://www.reichelt.de/stiftleiste-8-pol-gerade-rm-2-54-mpe-089-1-008-p225883.html?trstct=vrt_pdn&nbc=1
J20 | 01x02_Male | ~ | Connector_PinHeader_2.54mm:PinHeader_1x02_P2.54mm_Vertical | 1 |  | https://www.reichelt.de/stiftleiste-8-pol-gerade-rm-2-54-mpe-089-1-008-p225883.html?trstct=vrt_pdn&nbc=1
J21 | 02x02_Male | ~ | Connector_PinHeader_2.54mm:PinHeader_2x02_P2.54mm_Vertical | 1 |  | https://www.reichelt.de/stiftleiste-8-pol-gerade-rm-2-54-mpe-089-1-008-p225883.html?trstct=vrt_pdn&nbc=1
J22,J23 | opt. Connector | ~ | myLib9:TerminalBlock_Phoenix_MSTBVA-2.5-10-5.08_1x10_P5.08mm_Horizontal | 2 |  | opt.: https://www.phoenixcontact.com/en-pc/products/printed-circuit-board-connector-mstba-25-10-g-508-1757323
J24 | 01x05_Male | ~ | Connector_PinHeader_2.54mm:PinHeader_1x05_P2.54mm_Vertical | 1 |  | https://www.reichelt.de/stiftleiste-5-pol-gerade-rm-2-54-mpe-089-1-005-p225882.html?trstct=vrt_pdn&nbc=1
J25 | 01x05_fem | ~ | Connector_PinSocket_2.54mm:PinSocket_1x05_P2.54mm_Vertical | 1 |  | https://www.reichelt.de/buchsenleiste-2-54mm-1x5-gerade-bkl-10120947-p266672.html?trstct=pol_2&nbc=1
J26 | 01x04_Male | ~ | Connector_PinHeader_2.54mm:PinHeader_1x04_P2.54mm_Vertical | 1
J27,J44,J45,J58,J60,J65 | Lötauge | ~ | myLib9:Lötauge-Junction-2x2-1.4 | 6 |  | nichts benötigt
J28 | GND_CAN | ~ | myLib9:Lötauge-Junction-2x1.5 | 1 |  | nichts benötigt
J29,J30,J31,J41,J42,J46,J51,J53,J54,J55,J56,J57,J59 | Lötauge | ~ | myLib9:Lötauge-Junction | 13 |  | nichts benötigt
J32,J35,J38,J39,J52 | Lötauge | ~ | myLib9:Lötauge-Junction-3.5x2.5-1.6 | 5 |  | nichts benötigt
J34 | 01x01_Male | ~ | Connector_PinHeader_2.54mm:PinHeader_1x01_P2.54mm_Vertical | 1
J36 | 01x01_fem | ~ | Connector_PinSocket_2.54mm:PinSocket_1x01_P2.54mm_Vertical | 1 |  | https://www.reichelt.de/buchsenleiste-2-54mm-1x4-gerade-bkl-10120946-p266671.html?trstct=pol_1&nbc=1
J37 | Lötauge | ~ | myLib9:Lötauge-Junction-2x1.5 | 1 |  | nichts benötigt
J40 | Extention | ~ | Connector_PinHeader_2.54mm:PinHeader_2x12_P2.54mm_Vertical | 1 |  | https://www.mouser.de/ProductDetail/Samtec/ZW-12-14-F-D-980-118
J43,J66 | Flachstecker | ~ | myLib9:Lötauge-Junction-2x2-1.4 | 2 |  | https://www.reichelt.de/flachstecker-fuer-printmontage-breite-6-35mm-vt-fs-pw-6-35-p231355.html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
J49,J50 | 01x15 Male zu OP | ~ | Connector_PinHeader_2.54mm:PinHeader_1x15_P2.54mm_Vertical | 2
J61,J62,J63,J64 | Lötauge | ~ | myLib9:Lötauge-Junction-3.5x2.0-1.6 | 4 |  | nichts benötigt
JP1 | WP_ | ~ | Connector_PinHeader_2.54mm:PinHeader_1x03_P2.54mm_Vertical | 1 |  | https://www.reichelt.de/stiftleiste-3-pol-gerade-rm-2-54-mpe-089-1-003-p225881.html?trstct=vrt_pdn&nbc=1
JP2 | Jumper_NC_Small | https://cdn-reichelt.de/documents/datenblatt/C140/152-3.pdf | Connector_PinHeader_2.54mm:PinHeader_2x01_P2.54mm_Vertical_SMD | 1 |  | https://www.reichelt.de/2x10pol-smd-stiftleiste-gerade-rm-2-00-sl-2x10g-smd2-00-p51716.html?trstct=pol_2&nbc=1
JP3 | jumper field | https://www.reichelt.de/de/de/shop/produkt/2x20pol_-smd-stiftleiste_gerade_rm_2_00-51719 | myLib9:SAMTEC_TMMH-103-01-G-DV-A_PinHeader-02x03-SMD | 1
JP6 | GND-DEF-J7 | ~ | Connector_PinHeader_2.00mm:PinHeader_1x03_P2.00mm_Vertical | 1 |  | https://www.reichelt.de/de/de/shop/produkt/stiftleiste_1_27mm_1x3_gerade-262729
L1 | PIS2812-271M-04 | https://www.reichelt.de/index.html?ACTION=7&LA=3&OPEN=0&INDEX=0&FILENAME=B400%2FPIS2812.pdf | myLib9:L_7.3x7.3_H3.5_handsoldered | 1 |  | https://www.reichelt.de/index.html?ACTION=446&LA=0&nbc=1&q=pis2812-271m-04
L2 | 47µH |  | Inductor_SMD:L_1210_3225Metric | 1 |  | https://www.reichelt.de/chip-induktivitaet-1210f-47-h-l-1210f-47--p138578.html?&trstct=pol_3&nbc=1
L3 | L-1812AF 330µ 100mA | https://www.reichelt.de/index.html?ACTION=7&LA=3&OPEN=0&INDEX=0&FILENAME=B400%2FDS_1812AF-1.pdf | Inductor_SMD:L_1812_4532Metric | 1 |  | https://www.reichelt.de/chip-induktivitaet-1812af-330-h-l-1812af-330--p138596.html?trstct=pol_0&nbc=1
P1,P2 | 1,0K lin | https://www.reichelt.de/praezisionspotentiometer-trimmer-liegend-1-0-kohm-6-6-mm-75h-1-0k-p3475.html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 | myLib9:Trimmer_Vishay_T7YA | 2 |  | https://www.reichelt.de/praezisionspotentiometer-trimmer-liegend-1-0-kohm-6-6-mm-75h-1-0k-p3475.html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
Q1 | IRLML 2244 | https://www.reichelt.de/index.html?ACTION=7&LA=3&OPEN=0&INDEX=0&FILENAME=A200%2FDS_IRLML2244-IR.pdf | myLib9:SOT-23 | 1 |  | https://www.reichelt.de/mosfet-p-ch-20v-4-3a-1-3w-sot-23-irlml-2244-p132143.html?&trstct=pol_8&nbc=1
Q2 | IRLML 2244 | https://www.reichelt.de/index.html?ACTION=7&LA=3&OPEN=0&INDEX=0&FILENAME=A200%2FDS_IRLML2244-IR.pdf | Package_TO_SOT_SMD:SOT-23 | 1 |  | https://www.reichelt.de/mosfet-p-ch-20v-4-3a-1-3w-sot-23-irlml-2244-p132143.html?&trstct=pol_8&nbc=1
R1,R2,R3,R4,R5,R6,R7,R8,R9,R10,R11,R12,R13,R14,R15,R16 | 6k8 500mW | ESR18EZPF6801 | Resistor_SMD:R_1206_3216Metric | 16 |  | https://www.mouser.de/ProductDetail/ROHM-Semiconductor/ESR18EZPF6801
R17,R18,R19,R20,R21,R22,R23,R24,R25,R26,R27,R28,R29,R30,R31,R32 | 1k1 |  | Resistor_SMD:R_1206_3216Metric | 16 |  | https://www.reichelt.de/smd-widerstand-1206-1-2-kohm-250-mw-1--wal-wr12x1201ftl-p346655.html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
R33,R34,R35,R36,R37,R38,R39,R40,R41,R42,R43,R44,R45,R46,R47,R48 | 3k3 |  | Resistor_SMD:R_1206_3216Metric | 16 |  | https://www.reichelt.de/widerstand-metallschicht-3-30-kohm-0207-0-6-w-1--metall-3-30k-p11693.html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
R49,R52,R61,R67,R118,R119 | 10k | ~ | Resistor_SMD:R_1206_3216Metric | 6 |  | https://www.reichelt.de/smd-widerstand-1206-10-kohm-250-mw-1--vis-crcw120610k-p238102.html?trstct=pol_2&nbc=1
R50,R126 | 220 |  | myLib9:R_0805 | 2 |  | https://www.reichelt.de/smd-widerstand-1206-10-kohm-250-mw-1--vis-crcw120610k-p238102.html?trstct=pol_2&nbc=1
R51,R123 | 680k |  | Resistor_SMD:R_1206_3216Metric | 2
R53,R54,R55,R56,R57,R58,R59,R60 | 120 | RND 1206 1 120 SMD-Widerstand, 1206, 120 Ohm, 250 mW, 1% | myLib9:R_1206_HandSoldering | 8 |  | https://www.reichelt.de/smd-widerstand-1206-120-ohm-250-mw-1--rnd-1206-1-120-p183350.html?trstct=pol_0&nbc=1
R62,R68 | 10k | ~ | myLib9:R_1206_HandSoldering | 2 |  | https://www.reichelt.de/smd-widerstand-1206-10-kohm-250-mw-1--vis-crcw120610k-p238102.html?trstct=pol_2&nbc=1
R63,R64,R65,R66,R70,R71,R72,R73,R74,R75,R76,R77,R78,R79,R80,R81,R82,R83,R84,R85 | 1650 | SMD 1206 1/4W 1,6K 5% | Resistor_SMD:R_1206_3216Metric | 20 |  | https://www.reichelt.de/smd-widerstand-1206-1-6-kohm-250-mw-5--smd-1-4w-1-6k-p18236.html?trstct=pol_0&nbc=1
R69,R120 | 1k 0,1% | ~ | Resistor_THT:R_Axial_DIN0207_L6.3mm_D2.5mm_P2.54mm_Vertical | 2 |  | https://www.reichelt.de/widerstand-metallschicht-1-0-kohm-axial-250-mw-0-1--irc-r5dlf1k0bb-p237466.html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
R86,R87,R88,R89,R90,R91,R92,R93,R94,R95,R96,R97,R98,R99,R100,R101,R102,R103,R104,R105,R106,R107,R108,R109,R110,R111,R112,R113,R114,R115,R116,R117,R134,R135,R136,R137,R138,R139,R140,R141,R142,R143,R144,R145,R146,R147,R148,R149 | 7k5 |  | Resistor_SMD:R_1206_3216Metric | 48
R121,R122 | 3k0 0,1% | ~ | Resistor_THT:R_Axial_DIN0207_L6.3mm_D2.5mm_P2.54mm_Vertical | 2 |  | https://www.mouser.de/ProductDetail/TE-Connectivity-Holsworthy/H83K0BYA/
R124,R170 | 10k | ~ | myLib9:R_0805 | 2
R125,R127 | 30k 0,1% | ~ | Resistor_SMD:R_1206_3216Metric | 2 |  | https://www.reichelt.de/smd-widerstand-1206-30-kohm-125-mw-0-1--spr-1206-30-0k-p123445.html?trstct=pol_1&nbc=1
R128 | 47k | ~ | myLib9:R_0805 | 1
R129,R130 | 90k 0,1% | https://www.vishay.com/doc?28700 | Resistor_SMD:R_1206_3216Metric | 2 |  | https://www.mouser.de/ProductDetail/Vishay-Beyschlag/MCA12060D9002BP500
R131,R132,R150,R151,R152,R153,R154,R155,R156,R157,R158,R159,R160,R161,R162 | 51 |  | myLib9:R_0603 | 15
R133 | 220k | ~ | Resistor_SMD:R_1206_3216Metric | 1
R163,R165,R169,R171 | 10 | ~ | myLib9:R_0603 | 4
R164,R166,R167,R168 | 120 | SMD 1206 1/4W 120 1% | Resistor_SMD:R_1206_3216Metric | 4 |  | https://www.reichelt.de/smd-widerstand-1206-120-ohm-250-mw-1--vis-crcw1206120-p238104.html?trstct=pol_3&nbc=1
R172 | 1k | ~ | myLib9:R_1206_vertical | 1
R174 | 1650 | SMD 1206 1/4W 1,6K 5% | Resistor_SMD:R_0805_2012Metric | 1 |  | https://www.reichelt.de/smd-widerstand-1206-1-6-kohm-250-mw-5--smd-1-4w-1-6k-p18236.html?trstct=pol_0&nbc=1
R175 | 3k3 | SMD 1206 1/4W 1,6K 5% | Resistor_SMD:R_0805_2012Metric | 1 |  | https://www.reichelt.de/smd-widerstand-1206-1-6-kohm-250-mw-5--smd-1-4w-1-6k-p18236.html?trstct=pol_0&nbc=1
R176 | 10k | SMD 1206 1/4W 1,6K 5% | Resistor_SMD:R_0603_1608Metric | 1 |  | https://www.reichelt.de/smd-widerstand-1206-1-6-kohm-250-mw-5--smd-1-4w-1-6k-p18236.html?trstct=pol_0&nbc=1
RV1,RV2,RV3 | 31VDC | https://www.reichelt.de/index.html?ACTION=7&LA=3&OPEN=0&INDEX=0&FILENAME=B300%2FMCEPCOS_SMD-VARISTOREN_EN.pdf | Resistor_SMD:R_1210_3225Metric | 3 |  | https://www.reichelt.de/smd-varistor-1206-25-v-epc-b72520t0250-p240011.html?&trstct=pol_6&nbc=1
SW1,SW2 | SW_DIP_x02 | https://www.reichelt.de/dip-schalter-liegend-2-polig-nt-02-p36464.html?&trstct=pol_6&nbc=1 | Button_Switch_THT:SW_DIP_SPSTx02_Slide_6.7x6.64mm_W7.62mm_P2.54mm_LowProfile | 2 |  | https://www.reichelt.de/dip-schalter-liegend-2-polig-nt-02-p36464.html?&trstct=pol_6&nbc=1
SW3 | GDS0204 | https://eu.mouser.com/datasheet/2/418/NG_CD_1825006_R-678889.pdf | Button_Switch_THT:SW_DIP_SPSTx02_Slide_6.7x6.64mm_W7.62mm_P2.54mm_LowProfile | 1 |  | https://eu.mouser.com/ProductDetail/TE-Connectivity-PB/GDS0204?qs=W6FIH8d5%2F%2F0xcDIoBknPEQ%3D%3D
SW4 | OnOff | ~ | myLib9:switch-tactil_OMRON_B3U-3000P | 1 |  | https://eu.mouser.com/ProductDetail/Omron-Electronics/B3U-3000P?qs=AO7BQMcsEu4un9I7hS23xg%3D%3D
SW5 | Prog | ~ | myLib9:switch-tactil_OMRON_B3U-3000P | 1 |  | https://eu.mouser.com/ProductDetail/Omron-Electronics/B3U-3000P?qs=AO7BQMcsEu4un9I7hS23xg%3D%3D
TP1 | 3V3 | ~ | myLib9:TestPoint_SMD | 1
TP2 | TR | ~ | myLib9:TestPoint_SMD | 1
TP3 | Q | ~ | Connector_PinHeader_2.00mm:PinHeader_1x01_P2.00mm_Vertical | 1
TP4 | WDI | ~ | Connector_PinHeader_2.00mm:PinHeader_1x01_P2.00mm_Vertical | 1
TP5 | GNDD | ~ | Connector_PinHeader_2.00mm:PinHeader_1x01_P2.00mm_Vertical | 1
TP6 | EN_WD | ~ | myLib9:TestPoint_SMD | 1
U1,U2,U3,U4,U15,U16,U17,U18 | LTV-844 |  | myLib9:DIP-16_W7.62mm_cut | 8 |  | https://www.reichelt.de/4-fach-optokoppler-ac-5kv-35v-50ma-20-300-dip-16-ltv-844-p96808.html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
U5,U14 | MCP23S17 | http://ww1.microchip.com/downloads/en/DeviceDoc/20001952C.pdf | Package_DIP:DIP-28_W7.62mm | 2 |  | https://www.reichelt.de/bus-controller-push-pull-s-dil-28-mcp-23s17-e-sp-p90047.html?search=MCP23S17
U6,U8 | ISO1050 | http://www.ti.com/lit/ds/symlink/iso1050.pdf | myLib9:SOP-8 | 2 |  | https://www.reichelt.de/isolierter-can-transceiver-3-0-5-5v-sop-8-iso-1050-dub-p188663.html?trstct=pos_0&nbc=1
U7 | Teensy4.0 |  | myLib9:Teensy40wo34_0.9 | 1 |  | https://www.reichelt.de/teensy-4-0-usb-teensy-4-0-p269006.html?search=Teensy
U9 | 25LC512 | http://ww1.microchip.com/downloads/en/DeviceDoc/21832H.pdf | Package_DIP:DIP-8_W7.62mm | 1 |  | https://www.reichelt.de/eeprom-512-kb-64-k-x-8-spi-20-mhz-2-5--5-5-v-dip-8-25lc512-i-p-p96669.html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
U10 | ADM2483xRW | https://www.analog.com/media/en/technical-documentation/data-sheets/adm2483.pdf | myLib9:SOIC-16W_7.5x10.3mm_Pitch1.27mm_handsoldered | 1 |  | https://www.mouser.de/ProductDetail/Analog-Devices/ADM2483BRWZ?qs=BpaRKvA4VqH5Kim10agOlw%3D%3D
U11,U12 | 2S7WA_2405_S3RP | F:\Daten\ProgrammData\KiCad-Projects\datasheet\2S7WA_3RP_DS_EN.pdf | myLib9:SIP-7_2S7WA | 2 |  | https://www.reichelt.de/dc-dc-wandler-2-w-5-v-sil-7-2s7wa-2405s3rp-p242953.html?&trstct=pol_3&nbc=1
U13,U37 | LT1086 3.3 | http://www.st.com/st-web-ui/static/active/en/resource/technical/document/datasheet/CD00000544.pdf | Package_TO_SOT_THT:TO-220-3_Vertical | 2 |  | https://www.reichelt.de/ldo-spannungsregler-fix-3-3-v-1-5-a-to-220-3-lm-1086-ct-3-3-p187589.html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
U19,U20,U21,U22,U23,U24,U25,U26,U27,U28,U29,U30,U31,U32,U33,U34 | BSP-452 |  | Package_TO_SOT_SMD:SOT-223 | 16 |  | https://www.reichelt.de/analog-schalter-ic-1-kanal-pg-sot-223-bsp-452-smd-p41420.html?search=BSP-452
U35,U39 | ADuM1401xRW | https://www.analog.com/media/en/technical-documentation/data-sheets/ADUM1400_1401_1402.pdf | myLib9:SOIC-16W_7.5x10.3mm_Pitch1.27mm_handsoldered | 2 |  | https://www.reichelt.de/digitaler-isolator-4-kanal-so-16-adum-1401-crwz-p185568.html?trstct=pos_2&nbc=1
U36 | MCP3204 | http://ww1.microchip.com/downloads/en/DeviceDoc/21298c.pdf | myLib9:DIL-14-SMD | 1 |  | https://www.reichelt.de/12-bit-serieller-a-d-wandler-4-kanal-2-7v-spi-dip-14-mcp-3204-ci-p-p90076.html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
U38 | MCP4922 | http://ww1.microchip.com/downloads/en/devicedoc/21897a.pdf | Package_DIP:DIP-14_W7.62mm_Socket_LongPads | 1 |  | https://www.reichelt.de/d-a-wandler-12-bit-2-kanal-spi-2-7--5-5-v-dip-14-mcp-4922-e-p-p90090.html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
U40 | ADM-803S | https://www.analog.com/media/en/technical-documentation/data-sheets/ADM803_809_810.pdf | Package_TO_SOT_SMD:SOT-23 | 1 |  | https://www.mouser.de/ProductDetail/Analog-Devices/ADM803SAKSZ-REEL?qs=BpaRKvA4VqGi4JmhyG9lWA%3D%3D
U41 | LT 1078 | https://www.reichelt.de/operationsverstaerker-2-4-fach-dip-8-lt-1078-cn8-p10888.html?trstct=pol_3&nbc=1 | Package_DIP:DIP-8_W7.62mm_Socket | 1 |  | https://www.reichelt.de/operationsverstaerker-2-4-fach-dip-8-lt-1078-cn8-p10888.html?trstct=pol_3&nbc=1
U42,U43 | LM4040 AIM3-2.5 | http://www.ti.com/lit/ds/symlink/lm4040-n.pdf | myLib9:SOT-23 | 2 |  | https://www.reichelt.de/shunt-spannungsreferenz-fest-10-0-v-1-0-sot-23-3-lm-4040-dim3-10-p187746.html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
U44 | 2S7WB_2415S3RP | F:\Daten\ProgrammData\KiCad-Projects\datasheet\2S7WA_3RP_DS_EN.pdf | myLib9:SIP-7_2S7WA | 1 |  | https://www.reichelt.de/dc-dc-wandler-2-w-5-v-sil-7-2s7wa-2405s3rp-p242953.html?&trstct=pol_3&nbc=1
U45 | ADR03ARZ | https://www.analog.com/media/en/technical-documentation/data-sheets/ADR4520_4525_4530_4533_4540_4550.pdf | Package_SO:SOIC-8_3.9x4.9mm_P1.27mm | 1 |  | https://www.reichelt.de/spannungsreferenz-fest-2-5-v-3-ppm-c-so-8-adr-03-arz-p185546.html?search=ADR03ARZ
U46 | LCN78_05-1.0 | https://cdn-reichelt.de/documents/datenblatt/D400/LME78_10_DS_EN.pdf | myLib9:SIP-3-LC78 | 1 |  | https://www.reichelt.de/dc-dc-wandler-5-w-5-v-1000-ma-to-220-lme78-05-1-0-p242853.html?trstct=pol_7&nbc=1
U47 | ADM-809Z | https://www.analog.com/media/en/technical-documentation/data-sheets/ADM803_809_810.pdf | myLib9:SOT-23 | 1 |  | https://www.mouser.de/ProductDetail/Analog-Devices/ADM809ZARTZ-REEL7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
U48 | TPS3431 | https://www.ti.com/lit/ds/symlink/tps3431-q1.pdf?ts=1724652374995 | myLib9:VSON-8_EP_2.8x2.8_Pitch0.65mm | 1 |  | https://eu.mouser.com/ProductDetail/Texas-Instruments/TPS3431SDRBR?qs=w%2Fv1CP2dgqr73oCnz11srA%3D%3D
U49 | SN74LV1T32 | http://www.ti.com/lit/sg/scyt129e/scyt129e.pdf | Package_TO_SOT_SMD:SOT-23-5 | 1 |  | https://eu.mouser.com/ProductDetail/Texas-Instruments/SN74LV1T32DBVRG4?qs=vdi0iO8H4N3PxPbXDpMYbg%3D%3D
U50 | NE555DRG4 | http://www.ti.com/lit/ds/symlink/ne555.pdf | Package_SO:SOIC-8_3.9x4.9mm_P1.27mm | 1 |  | ????
U51 | SN74LV1T08 | http://www.ti.com/lit/sg/scyt129e/scyt129e.pdf | Package_TO_SOT_SMD:SOT-23-5 | 1 |  | https://www.mouser.de/ProductDetail/Texas-Instruments/SN74LV1T08DBVRG4?qs=vdi0iO8H4N0dPmKl30OCjQ%3D%3D
U52 | S-80929CNMC | https://eu.mouser.com/datasheet/2/1490/SIIS_S_A0001381435_1-3425320.pdf | Package_TO_SOT_SMD:SOT-23-5 | 1 |  | https://eu.mouser.com/ProductDetail/ABLIC/S-80929CNMC-G8ZT2U?qs=0lQeLiL1qyby2Jl2PY%252BoeQ%3D%3D
U53,U54 | BD7LS04G-C | https://fscdn.rohm.com/en/products/databook/datasheet/ic/logic_switch/standard_logic/bd7ls04g-c-e.pdf | Package_TO_SOT_SMD:SOT-23-5 | 2 |  | https://www.mouser.de/ProductDetail/ROHM-Semiconductor/BD7LS04G-CTL
U55 | F-RAM SPI SOIC-8 |  |  | 1

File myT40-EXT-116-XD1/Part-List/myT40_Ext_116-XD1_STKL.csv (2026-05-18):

Source: | F:\Daten\ProgrammData\KiCad-Projects\CASA\myT40_Ext_116-XD1-V1_prod\myT40_Ext_116-XD1.kicad_sch
Date: | 30.03.2024 19:53:37
Tool: | Eeschema 7.0.11
Generator: | D:\KiCad7\bin\scripting\plugins\bom_csv_grouped_by_value.py
Component Count: | 58
Collated Components:
Item | Qty | Reference(s) | Value | LibPart | Footprint | Datasheet | DNP | Bezug
1 | 4 | C1, C3, C4, C5 | 100n | Device:C | Capacitor_SMD:C_0805_2012Metric | ~
2 | 1 | C2 | 1µ5 | Device:C_Polarized | Capacitor_Tantalum_SMD:CP_EIA-3216-18_Kemet-A | https://cdn-reichelt.de/documents/datenblatt/A900/AVX_TAJ_DS.pdf |  | https://www.reichelt.de/smd-tantal-kondensator-1-5-f-25-v-taj-3516-1-5-25-p166996.html?trstct=pol_2&nbc=1
3 | 17 | D1, D2, D3, D4, D5, D6, D7, D8, D9, D10, D11, D12, D13, D14, D15, D16, D17 | KPTD-3216 | Device:LED_Small | LED_SMD:LED_1206_3216Metric | ~ |  | https://www.reichelt.de/led-smd-3216-1206-rot-600-mcd-50--smd-led-1206k-rt-p54085.html?trstct=pos_0&nbc=1
4 | 4 | H1, H2, H3, H4 | MountingHole | Mechanical:MountingHole | MountingHole:MountingHole_2.5mm | ~
5 | 1 | H5 | MountingHole | :MountingHole_1 | MountingHole:MountingHole_2.5mm | ~
6 | 1 | J1 | Ext-In 2x12 | Connector_Generic:Conn_02x12_Odd_Even | Connector_PinHeader_2.54mm:PinHeader_2x12_P2.54mm_Vertical | https://www.reichelt.de/flachbandkabel-awg28-24-pol-farb-3m-ring-awg-28-24f-3m-p47672.html?trstct=pol_3&nbc=1 |  | https://www.mouser.de/ProductDetail/HARTING/09181249622?qs=FeiuqfHlVTsgftAM1UBfXg%3D%3D
7 | 1 | J2 | Ext-Out 2x12 | Connector_Generic:Conn_02x12_Odd_Even | Connector_PinHeader_2.54mm:PinHeader_2x12_P2.54mm_Vertical | ~ |  | https://www.mouser.de/ProductDetail/Samtec/TSS-112-04-G-D-RA?qs=rU5fayqh%252BE15IrLNqbXScQ%3D%3D
8 | 1 | J3 | Byte0 01x10 | Connector_Generic:Conn_01x10 | Connector_PinSocket_2.54mm:PinSocket_1x10_P2.54mm_Vertical | 10 x 3" |  | https://www.mouser.de/ProductDetail/TE-Connectivity/FSN-23A-10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
9 | 1 | J4 | Byte1 01x10 | Connector_Generic:Conn_01x10 | Connector_PinSocket_2.54mm:PinSocket_1x10_P2.54mm_Vertical | 15 x 4" (10 genutzt f. untere Platine) |  | https://www.mouser.de/ProductDetail/TE-Connectivity/FSN-24A-15
10 | 16 | R1, R2, R3, R4, R5, R6, R7, R8, R9, R10, R11, R12, R13, R14, R15, R16 | 270 | Device:R | Resistor_SMD:R_1206_3216Metric | ~ |  | https://www.reichelt.de/smd-widerstand-1206-270-ohm-250-mw-1--wal-wr12x2700ftl-p346664.html?trstct=pol_1&nbc=1
11 | 3 | R17, R18, R19 | 10k | Device:R | Resistor_SMD:R_1206_3216Metric | ~
12 | 1 | R20 | 51 | Device:R | Resistor_SMD:R_0603_1608Metric | ~ |  | https://www.reichelt.de/smd-widerstand-0603-51-ohm-100-mw-1--rnd-0603-1-51-p183008.html?trstct=pol_1&nbc=1
13 | 1 | R21 | 470 | Device:R | Resistor_SMD:R_0805_2012Metric | ~ |  | https://www.reichelt.de/smd-widerstand-0805-470-ohm-125-mw-1--smd-0805-470-p32882.html?trstct=pol_2&nbc=1
14 | 1 | R22 | 68k | Device:R | Resistor_SMD:R_0805_2012Metric | ~ |  | https://www.reichelt.de/smd-widerstand-0603-51-ohm-100-mw-1--rnd-0603-1-51-p183008.html?trstct=pol_1&nbc=1
15 | 1 | SW1 | SW_DIP_x03 | Switch:SW_DIP_x03 | Button_Switch_THT:SW_DIP_SPSTx03_Slide_6.7x9.18mm_W7.62mm_P2.54mm_LowProfile | ~ |  | https://www.reichelt.de/dip-schalter-liegend-3-polig-nt-03-p36465.html?&trstct=pol_0&nbc=1
16 | 1 | U1 | MCP23S17_SO | Interface_Expansion:MCP23S17_SO | Package_SO:SOIC-28W_7.5x17.9mm_P1.27mm | http://ww1.microchip.com/downloads/en/DeviceDoc/20001952C.pdf |  | https://www.mouser.de/ProductDetail/Microchip-Technology/MCP23S17-E-SO?qs=usxtMOJb1RzJScThsWtScg%3D%3D
17 | 3 | U2, U3, U4 | SN74LVC1G17DBVTE4 | 74xGxx:74LVC1G17 | Package_TO_SOT_SMD:SOT-23-5 | https://www.ti.com/lit/ds/symlink/sn74lvc1g17.pdf |  | https://www.mouser.de/ProductDetail/Texas-Instruments/SN74LVC1G17DBVTE4

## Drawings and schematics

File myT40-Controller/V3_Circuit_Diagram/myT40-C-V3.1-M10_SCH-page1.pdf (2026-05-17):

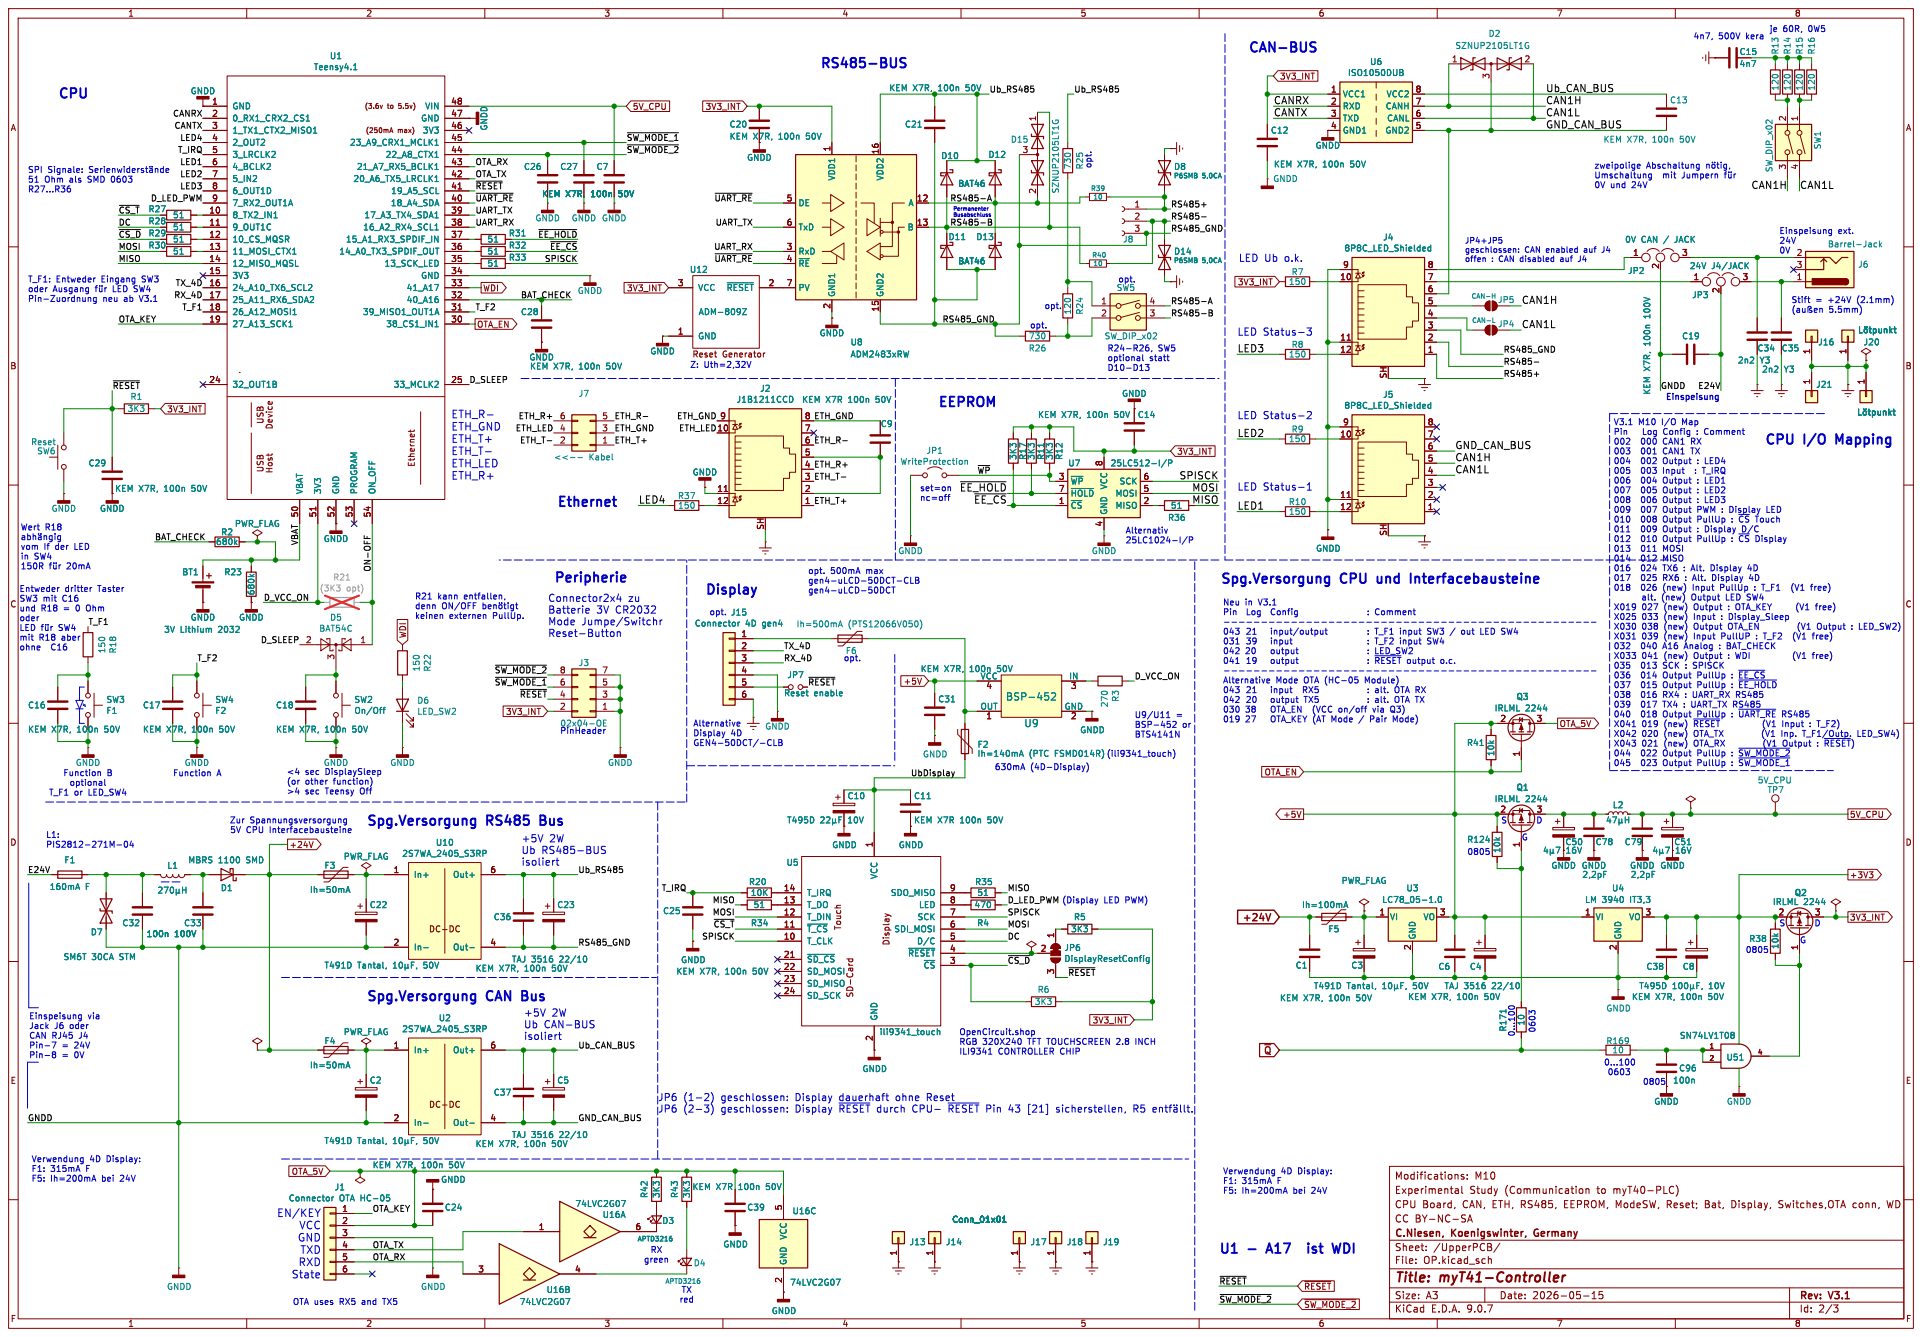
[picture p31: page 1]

LED Ub o.k. set=on

þÿ(außen 5.5mm) Alternative Display 4D GEN4-50DCT/-CLB +5V 2W

4 SCK 6 MOSI 5 MISO 2 U7 25LC512-I/P GNDD

vom If der LED

Spg.Versorgung CPU und Interfacebausteine

Spg.Versorgung CAN Bus

C5 TAJ 3516 22/10 C37 KEM X7R, 100n 50V DC-DC

Id: 2/3 Title: myT41-Controller File: OP.kicad_sch Sheet: /UpperPCB/

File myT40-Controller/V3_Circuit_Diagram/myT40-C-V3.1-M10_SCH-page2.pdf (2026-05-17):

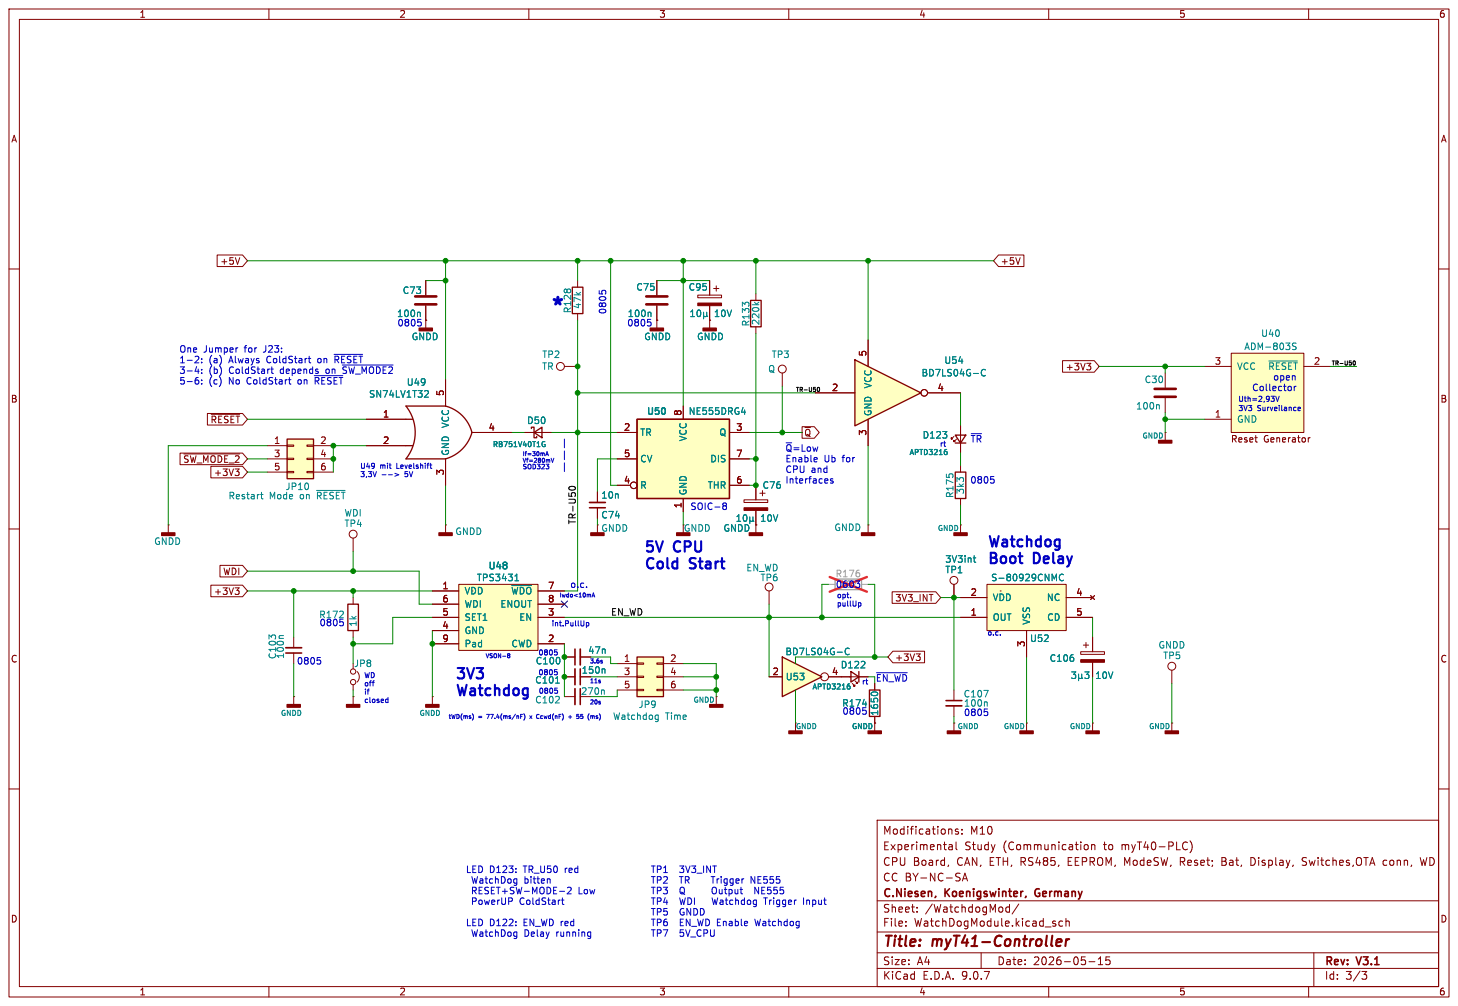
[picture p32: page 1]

0805 ~{Q}=Low
Enable Ub for CPU and

PowerUP ColdStart LED D122: EN_WD red WatchDog Delay running

Id: 3/3 Title: myT41-Controller File: WatchDogModule.kicad_sch Sheet: /WatchdogMod/

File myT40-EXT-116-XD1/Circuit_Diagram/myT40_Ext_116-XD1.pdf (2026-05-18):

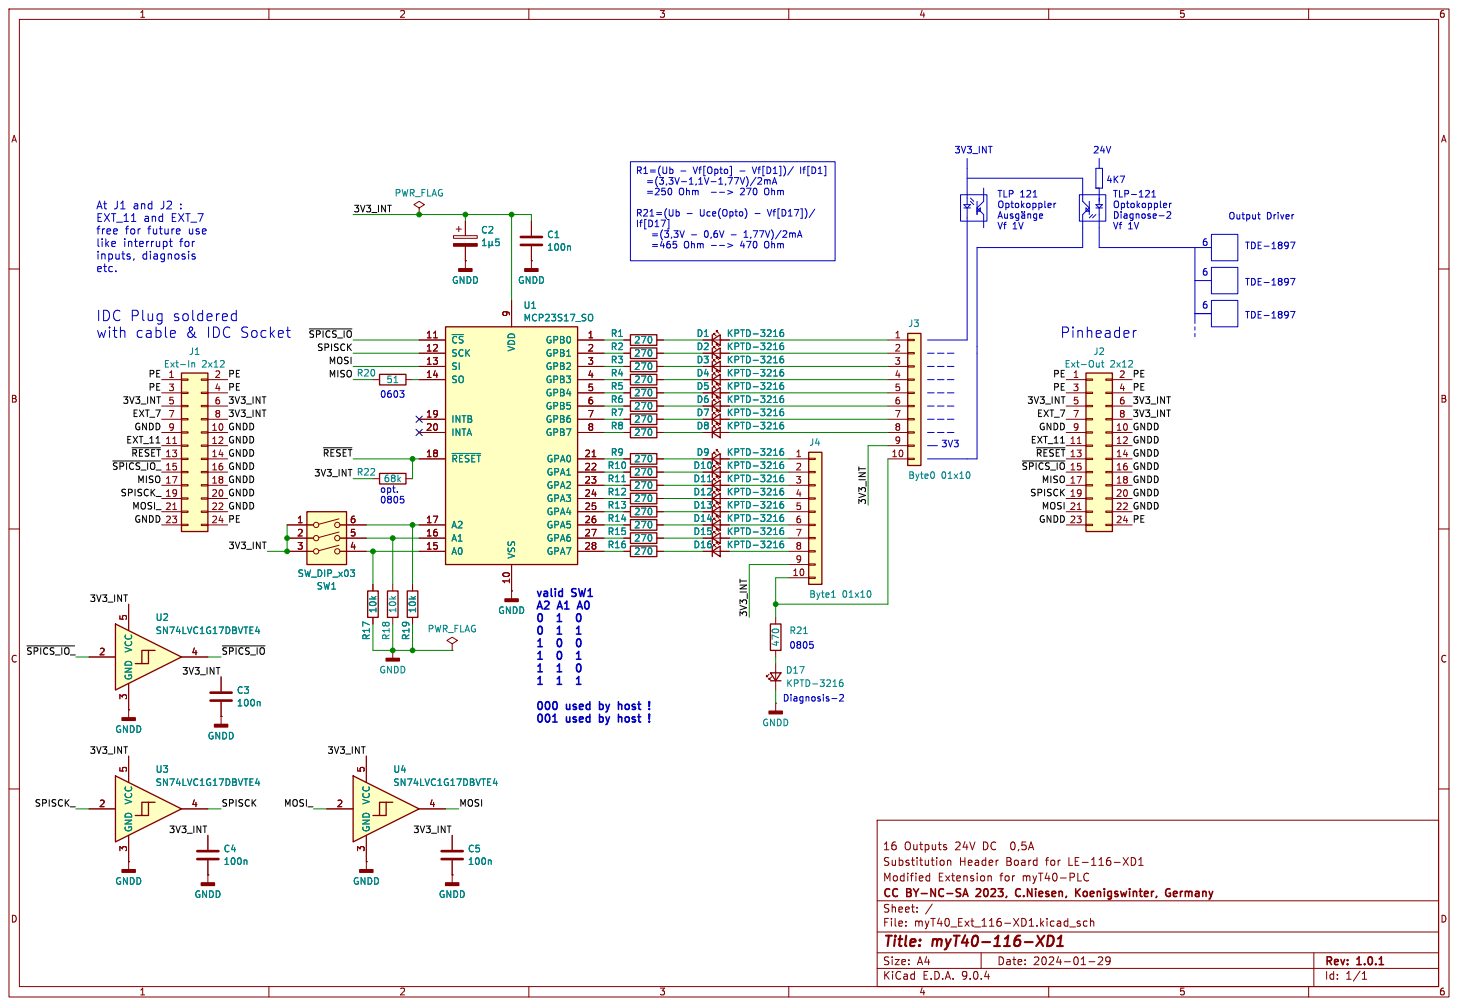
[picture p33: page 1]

free for future use

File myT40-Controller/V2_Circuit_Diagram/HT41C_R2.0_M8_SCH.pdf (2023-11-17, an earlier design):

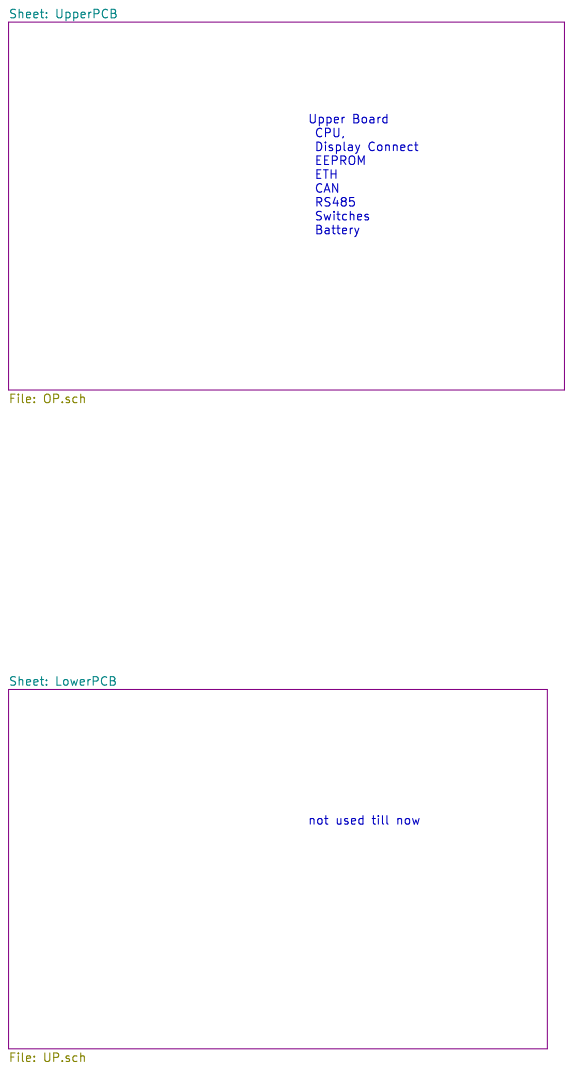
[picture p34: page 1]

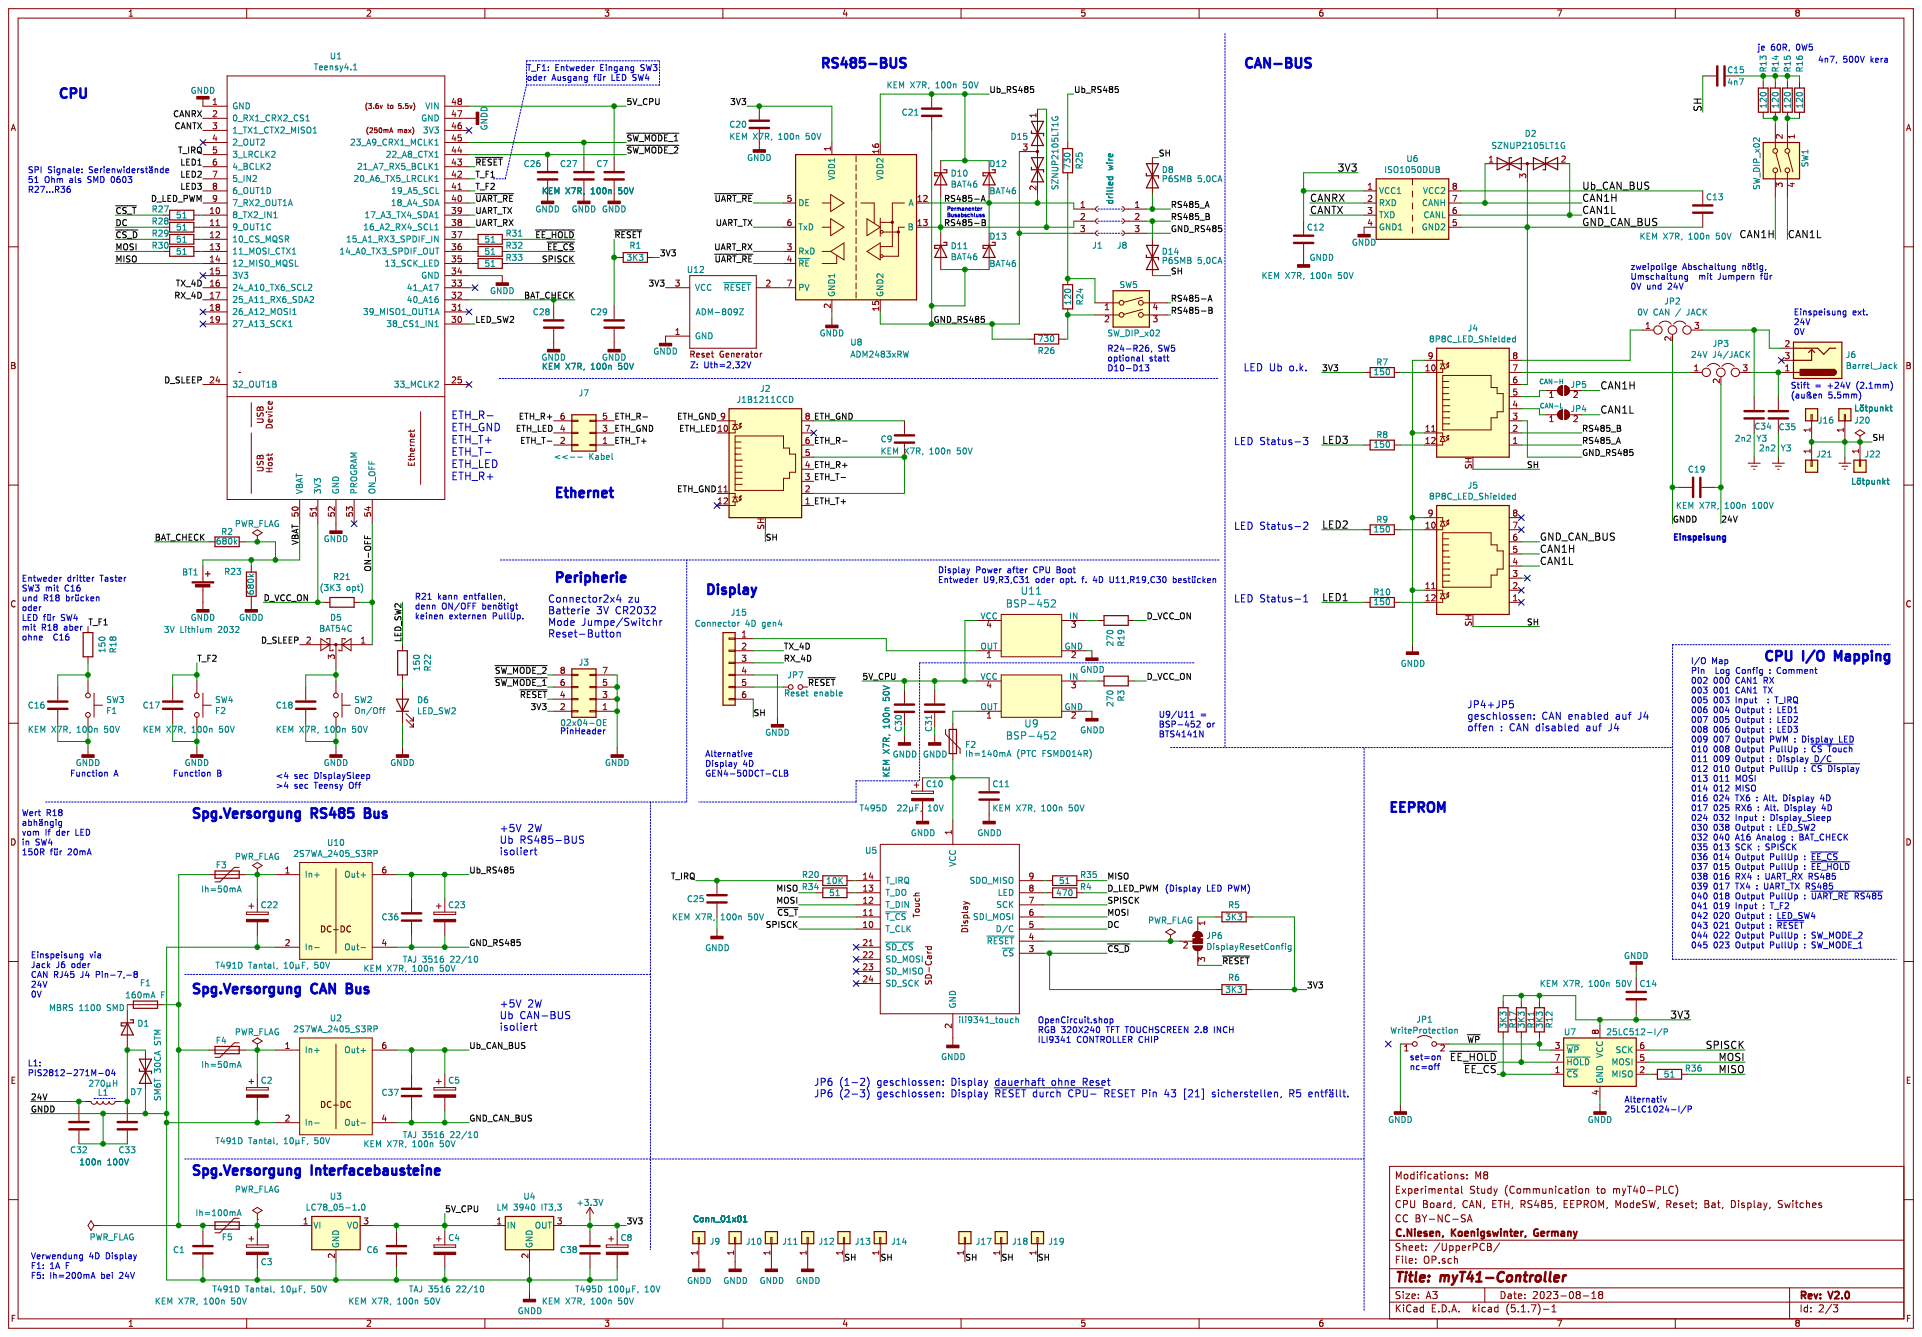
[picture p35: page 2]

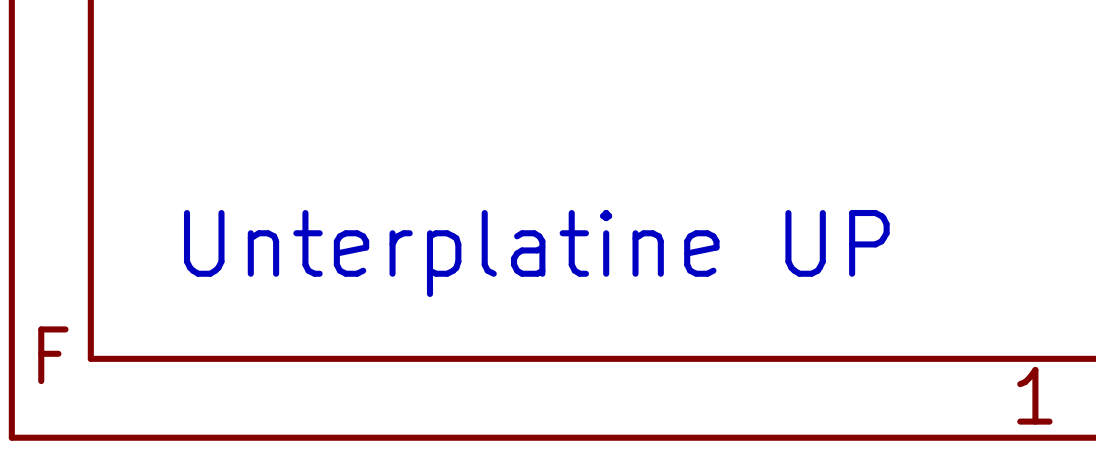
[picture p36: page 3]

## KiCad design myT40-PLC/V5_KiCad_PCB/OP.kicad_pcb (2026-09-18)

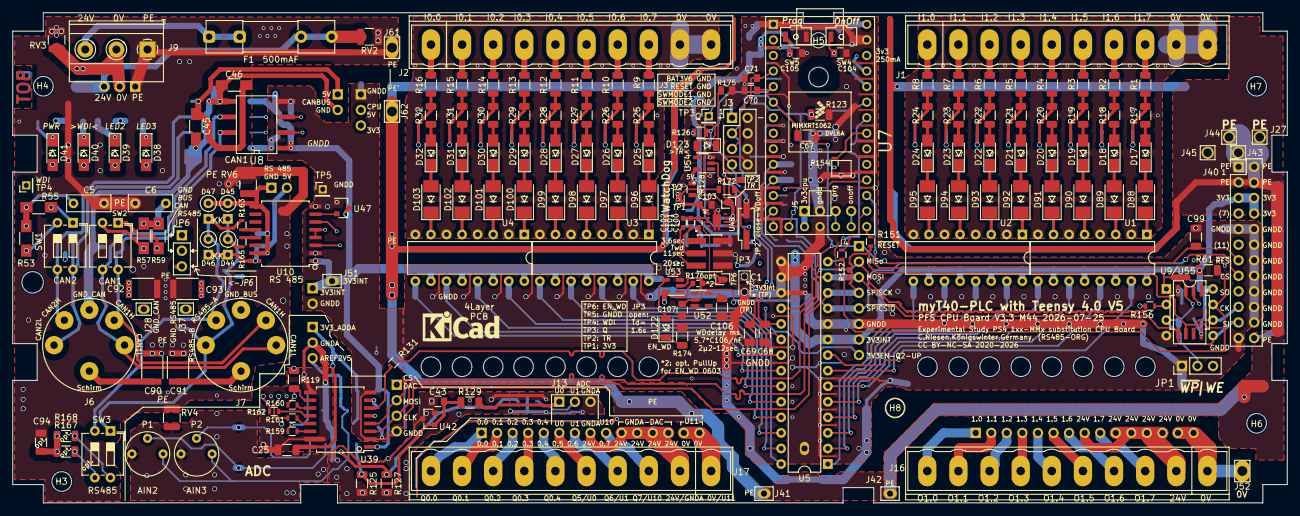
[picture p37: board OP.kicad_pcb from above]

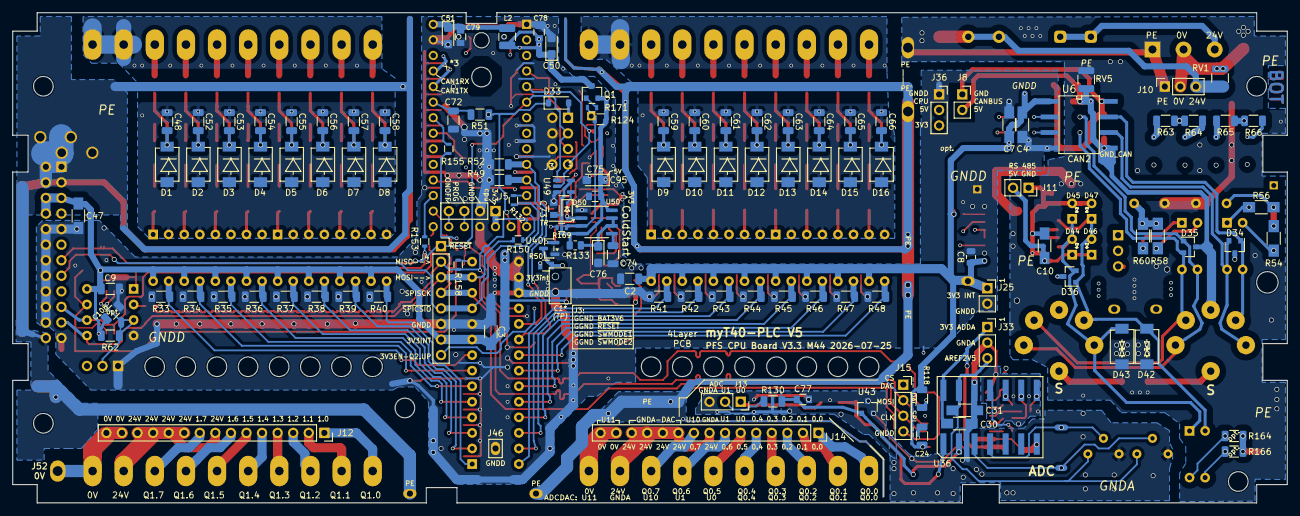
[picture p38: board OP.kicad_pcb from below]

Board: 4 copper layers, 208.0 x 80.0 mm, 341 parts (127 on the bottom side), 234 nets.

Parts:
A2: KiCad-Symbol; KiCad-Logo_5mm_SilkScreen
C1: Siehe Text; CP_EIA-3216-18_Kemet-A
C2, C9, C24, C25, C48, C52, C53, C54, C55, C56, C57, C58, C59, C60, C61, C62, C63, C64, C65, C66, C67, C68, C69, C72, C99, C108: 100n; C_1206_3216Metric
C3, C4, C7, C10, C30, C31, C47: 100n; C_1206_HandSoldering
C5, C6: 4n7; C_Rect_L7.0mm_W2.5mm_P5.00mm
C8: 100n; C_0805_2012Metric
C43, C77: 100p; C_0805
C45, C46: 100n 100V; C_1206_HandSoldering
C50, C51: 4µ7 16V; CP_EIA-3216-18_Kemet-A
C70, C71, C73, C75, C103, C104, C105, C107: 100n; C_0805
C74: 10n; C_1206_3216Metric
C76, C95: 10µ 10V; CP_EIA-3216-18_Kemet-A
C78, C79: 2,2pF; C_0805
C90, C91, C92, C93: 220n 250V; C_1812
C94: 220p 50V; C_1206_3216Metric
C100: 47n; C_0603
C101: 150n; C_0603
C102: 270n; C_0603
C106: 2µ2; C_1206_3216Metric
D1, D2, D3, D4, D5, D6, D7, D8, D9, D10, D11, D12, D13, D14, D15, D16: P6SMB 5,0CA SMD; DO-214AA_man
D17, D18, D19, D20, D21, D22, D23, D24, D25, D26, D27, D28, D29, D30, D31, D32, D38, D39, D40, D41: APTD3216; LED_1206_HandSoldering
D33: 1N4448W7F DII; D_SOD-123
D34, D35, D36: SZNUP2105LT1G; SOT-23
D42, D43: P6SMB 5,0CA; DO-214AA_man
D44, D45, D46, D47: BAT 46; D_DO-35_SOD27_P2.54mm_Vertical_KathodeUp
D50: RB751V40T1G; D_SOD-323
D88, D89, D90, D91, D92, D93, D94, D95, D96, D97, D98, D99, D100, D101, D102, D103: 1N4448W7F DII; Diode_DO213AB-MELF_SOD123
D122, D123: APTD3216; LED_1206_3216_big-gap
F1: 500mA F; Fuseholder_Clip-5x20mm_Littelfuse_111_Inline_P20.00x5.00mm_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
H1: MH2,5; Hole_2,5mm
H2: MH3,5; Hole_3,5mm
H3, H4, H5, H6, H7, H8: MountingHole; MountingHole_3.2mm_M3
H9, H10, H11, H12, H13, H14, H15, H16, H17, H18, H19, H20, H21, H22, H23, H24: LED3.2mm; Hole_3.2mm
J1, J2, J16, J17: MSTBVA-2.5-10-5.08; TerminalBlock_Phoenix_MSTBVA-2.5-10-5.08_1x10_P5.08mm_Horiz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
J3: 02x04; PinHeader_2x04_P2.54mm_Vertical
J4: 01x08_fem; PinSocket_1x08_P2.54mm_Vertical
J5, J15: 01x04_fem; PinSocket_1x04_P2.54mm_Vertical
J6, J7: DIN-5; DIN-5-180
J8, J11, J25: 01x02_fem; PinSocket_1x02_P2.54mm_Vertical
J9: Ub 0V PE; TerminalBlock_Phoenix_MKDS-1,5-3-5.08_1x03_P5.08mm_Horizont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
J10, J13, J33, J36: 01x03_fem; PinSocket_1x03_P2.54mm_Vertical
J12, J14: 01x15_fem; PinSocket_1x15_P2.54mm_Vertical
J27, J44, J45: Lötauge; Lötauge-Junction-2x2-1.4
J28: GND_CAN; Lötauge-Junction-2x1.5
J37: Lötauge; Lötauge-Junction-2x1.5
J40: Extention; PinHeader_2x12_P2.54mm_Vertical
J41, J42, J46, J51: Lötauge; Lötauge-Junction
J43: Flachstecker; Lötauge-Junction-2x2-1.4
J52: Lötauge; Lötauge-Junction-3.5x2.5-1.6
J61, J62: Lötauge; Lötauge-Junction-3.5x2.0-1.6
JP1: WP_; PinHeader_1x03_P2.54mm_Vertical
JP2: Jumper_NC_Small; PinHeader_2x01_P2.54mm_Vertical_SMD
JP3: jumper field; SAMTEC_TMMH-103-01-G-DV-A_PinHeader-02x03-SMD
JP6: GND-DEF.J7; PinHeader_1x03_P2.54mm_Vertical
L2: 47µH; L_1210_3225Metric
P1, P2: 1,0K lin; Trimmer_Vishay_T7YA
Q1: IRLML 2244; SOT-23
R1, R2, R3, R4, R5, R6, R7, R8, R9, R10, R11, R12, R13, R14, R15, R16: 6k8 500mW; R_1206_3216Metric
R17, R18, R19, R20, R21, R22, R23, R24, R25, R26, R27, R28, R29, R30, R31, R32: 1k1; R_1206_3216Metric
R33, R34, R35, R36, R37, R38, R39, R40, R41, R42, R43, R44, R45, R46, R47, R48: 3k3; R_1206_3216Metric
R49, R52, R61, R62, R118, R119: 10k; R_1206_3216Metric
R50, R126: 220; R_0805
R51, R123: 680k; R_1206_3216Metric
R53, R54, R55, R56, R57, R58, R59, R60: 120; R_1206_HandSoldering
R63, R64, R65, R66, R174: 1650; R_1206_3216Metric
R124: 10k; R_0805
R125, R127: 30k 0,1%; R_1206_3216Metric
R128: 47k; R_0805
R129, R130: 90k 0,1%; R_1206_3216Metric
R131, R132, R150, R151, R152, R153, R154, R155, R156, R158, R159, R160, R161, R162: 51; R_0603
R133: 220k; R_0805_2012Metric
R163, R165, R169, R171: 10; R_0603
R164, R166, R167, R168: 120; R_1206_3216Metric
R172: 1k; R_1206_vertical
R175: 3k3; R_0805_2012Metric
R176: 10k; R_0603_1608Metric
RV1, RV2, RV3: 31VDC; R_1210_3225Metric
RV4, RV5, RV6: 46VAC; R_1210_3225Metric
SW1, SW2: SW_DIP_x02; SW_DIP_SPSTx02_Slide_6.7x6.64mm_W7.62mm_P2.54mm_LowProfile
SW3: GDS0204; SW_DIP_SPSTx02_Slide_6.7x6.64mm_W7.62mm_P2.54mm_LowProfile
SW4: OnOff; switch-tactil_OMRON_B3U-3000P
SW5: Prog; switch-tactil_OMRON_B3U-3000P
TP1: 3V3; TestPoint_SMD
TP2: TR; TestPoint_SMD
TP3: Q; PinHeader_1x01_P2.00mm_Vertical
TP4: WDI; PinHeader_1x01_P2.00mm_Vertical
TP5: GNDD; PinHeader_1x01_P2.00mm_Vertical
TP6: EN_WD; TestPoint_SMD
U1, U2, U3, U4: LTV-844; DIP-16_W7.62mm_cut
U5: MCP23S17; DIP-28_W7.62mm
U6, U8: ISO1050; SOP-8
U7: Teensy4.0; Teensy40wo34_0.9
U9: 25LC512; DIP-8_W7.62mm
U10: ADM2483xRW; SOIC-16W_7.5x10.3mm_Pitch1.27mm_handsoldered
U36: MCP3204; DIL-14-SMD
U39: ADuM1401xRW; SOIC-16W_7.5x10.3mm_Pitch1.27mm_handsoldered
U40: ADM-803S; SOT-23
U42, U43: LM4040 AIM3-2.5; SOT-23
U47: ADM-809Z; SOT-23
U48: TPS3431; VSON-8_EP_2.8x2.8_Pitch0.65mm
U49: SN74LV1T32; SOT-23-5
U50: NE555DRG4; SOIC-8_3.9x4.9mm_P1.27mm
U52: S-80929CNMC; SOT-23-5
U53, U54: BD7LS04G-C; SOT-23-5
U55: FM25V10; SOIC-8_5.3x6.2mm_P1.27mm

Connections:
3V3: C103.1, J36.3, R50.1, R126.2, R172.1, R176.1, TP1.1, U40.3 (VCC), U48.1 (VDD), U53.5 (3V3)
5V_CPU: C73.2, C75.2, C95.1, J36.2, Q1.2 (S), R124.2, R128.2, R133.2, U49.5 (5V_CPU), U50.4 (R), U50.8 (VCC), U54.5 (5V_CPU)
/3V3EN_Q2_UP: J4.8, R169.2
/3V3_ADDA: C25.2, C30.2, J33.1, R119.2, U36.14 (Vdd), U39.16 (VDD2)
/3V3_CPU: J5.1, U7.16 (3V3)
/3V3_INT: C1.1, C2.1, C3.2, C4.1, C7.2, C8.1, C9.2, C24.2, C47.2, C107.1, C108.2, D41.2 (A), J4.7, J25.1, J40.5, J40.6, J40.8, J51.1, R61.1, R62.1, R118.2, U1.10, U1.12, U1.14, U1.16, U2.10, U2.12, U2.14, U2.16, U3.10, U3.12, U3.14, U3.16, U4.10, U4.12, U4.14, U4.16, U5.9 (VDD), U6.1 (VCC1), U8.1 (VCC1), U9.8 (VCC), U10.1 (VDD1), U39.1 (VDD1), U47.3 (VCC), U52.2 (VDD), U55.8 (VCC)
/5V_CPU_final: C51.1, C79.1, L2.2, U7.33 (VIN)
/AIN0: J13.1, R129.1
/AIN1: J13.2, R130.1
/AREF_2V5: C31.2, J33.3, P1.3, P2.3, U36.13 (Vref)
/BAT3V6: D33.2 (A), J3.1
/BAT_CHECK: C72.1, R51.2, U7.28 (21_A7_RX5_BCLK1)
/CAN1H: D35.2 (A2), J6.5, J7.5, SW2.4, U8.7 (CANH)
/CAN1L: D35.1 (A1), J6.3, J7.3, SW2.3, U8.6 (CANL)
/CAN1RX: U7.30 (23_A9_CRX1_MCLK1), U8.2 (RXD)
/CAN1TX: U7.29 (22_A8_CTX1), U8.3 (TXD)
/CAN2H: D34.1 (A1), J6.4, SW1.3, U6.7 (CANH)
/CAN2L: D34.2 (A2), J6.1, SW1.4, U6.6 (CANL)
/CAN2RX: U6.2 (RXD), U7.2 (0_RX1_CRX2)
/CAN2TX: U6.3 (TXD), U7.3 (1_TX1_CTX2)
/CH0: C43.1, R125.1, R129.2, U36.1 (CH0), U42.1 (K)
/CH1: C77.1, R127.1, R130.2, U36.2 (CH1), U43.1 (K)
/CH2: P1.2, U36.3 (CH2)
/CH3: P2.2, U36.4 (CH3)
/CLK: R159.2, U36.11 (CLK)
/Din: R161.2, U36.9 (Din)
/Dout: R160.2, U36.10 (Dout)
/EN_WD: R176.2, TP6.1, U48.3 (EN), U52.1 (OUT), U53.2
/GND_CAN_BUS: C45.2, C46.1, C92.1, D34.3 (common), D35.3 (common), J6.2, J8.2, J28.1, JP6.1 (A), RV5.2, U6.5 (GND2), U8.5 (GND2)
/GND_RS485_BUS: C10.1, C93.2, D36.3 (common), D45.2 (A), D47.2 (A), J11.1, J37.1, JP6.3 (B), RV6.2, U10.9 (GND2), U10.15 (GND2)
/INTA: C69.1, R52.1, U5.20 (INTA), U7.10 (8_TX2_IN1)
/INTB: C68.1, R49.1, U5.19 (INTB), U7.11 (9_OUT1C)
/I_GPA0: R48.2, U4.9, U5.21 (GPA0)
/I_GPA1: R47.2, U4.11, U5.22 (GPA1)
/I_GPA2: R46.2, U4.13, U5.23 (GPA2)
/I_GPA3: R45.2, U4.15, U5.24 (GPA3)
/I_GPA4: R44.2, U3.9, U5.25 (GPA4)
/I_GPA5: R43.2, U3.11, U5.26 (GPA5)
/I_GPA6: R42.2, U3.13, U5.27 (GPA6)
/I_GPA7: R41.2, U3.15, U5.28 (GPA7)
/I_GPB0: R40.2, U2.9, U5.1 (GPB0)
/I_GPB1: R39.2, U2.11, U5.2 (GPB1)
/I_GPB2: R38.2, U2.13, U5.3 (GPB2)
/I_GPB3: R37.2, U2.15, U5.4 (GPB3)
/I_GPB4: R36.2, U1.9, U5.5 (GPB4)
/I_GPB5: R35.2, U1.11, U5.6 (GPB5)
/I_GPB6: R34.2, U1.13, U5.7 (GPB6)
/I_GPB7: R33.2, U1.15, U5.8 (GPB7)
/LED1: D40.2 (A), TP4.1, U7.7 (5_IN2), U48.6 (WDI)
/LED2: D39.2 (A), U7.8 (6_OUT1D)
/LED3: D38.2 (A), U7.9 (7_RX2_OUT1A)
/MISO: J4.2, J40.17, R131.1, R156.2, R158.2, U7.14 (12_MISO_MQSL)
/MISO_0: R156.1, U9.2 (MISO), U55.2 (MISO)
/MOSI: J4.3, J15.2, J40.21, R150.1, U5.13 (SI), U9.5 (MOSI), U39.4 (VIB), U55.5 (MOSI)
/ONOFF: C104.1, J5.4, SW4.2, U7.19 (ON_OFF)
/PROGRAM: C105.1, J5.3, SW5.2, U7.18 (PROGRAM)
/Q: R124.1, R169.1, R171.1, TP3.1, U50.3 (Q)
/RS485_A: D36.1 (A1), D42.2 (A2), D46.2 (A), D47.1 (K), J7.4, R163.1, SW3.2
/RS485_B: D36.2 (A2), D43.2 (A2), D44.2 (A), D45.1 (K), J7.1, R165.1, SW3.1
/SPISCK: J4.4, J15.3, J40.19, R151.1, U5.12 (SCK), U9.6 (SCK), U39.3 (VIA), U55.6 (SCK)
/TR-U50: D50.2 (A), R128.1, TP2.1, U40.2 (~RESET), U48.7 (~WDO), U50.2 (TR), U54.2
/U0V: J9.2, J10.2, RV1.1, RV3.2
/U24V: F1.2, J10.3, RV1.2, RV2.2
/UART_RX: U7.23 (16_A2_RX4_SCL1), U10.3 (RxD)
/UART_TX: U7.24 (17_A3_TX4_SDA1), U10.6 (TxD)
/Ub_5V_RS485_BUS: C10.2, D44.1 (K), D46.1 (K), J11.2, U10.16 (VDD2)
/Ub_CAN_BUS: C45.1, C46.2, J8.1, U6.8 (VCC2), U8.8 (VCC2)
/VBAT: D33.1 (K), R51.1, R123.1, U7.15 (VBAT)
/~CS: R162.2, U36.8 (~CS/SHDN)
/~EE_HOLD: R61.2, R152.1, U9.7 (~HOLD), U55.7 (~HOLD)
/~RESET: C67.1, C99.2, J3.3, J4.1, J40.13, R50.2, U5.18 (~RESET), U7.6 (4_BCLK2), U49.1
/~SPICS_ADC: R154.1, U39.5 (VIC)
/~SPICS_DAC: J15.1, R155.1
/~SPICS_EE: R153.1, U9.1 (~CS), U55.1 (~CS)
/~SPICS_IO: J4.5, J40.15, R132.1, U5.11 (~CS)
/~SW_MODE_1: C71.1, J3.5, U7.4 (2_OUT2)
/~SW_MODE_2: C70.1, J3.7, R126.1, U7.5 (3_LRCLK2), U49.2
/~UART_RE: U7.25 (18_A4_SDA0), U10.4 (~RE), U10.5 (DE)
/~WP: JP1.2 (C), R62.2, U9.3 (~WP), U55.3 (~WP)
GNDA: C25.1, C30.1, C31.1, C43.2, C77.2, J13.3, J33.2, P1.1, P2.1, R125.2, R127.2, RV4.2, U36.7 (DGND), U36.12 (AGND), U39.9 (GND2), U39.15 (GND2), U42.2 (A), U42.3 (3(A)), U43.2 (A), U43.3 (3(A))
GNDD: C1.2, C2.2, C3.1, C4.2, C7.1, C8.2, C9.1, C24.1, C47.1, C50.2, C51.2, C67.2, C68.2, C69.2, C70.2, C71.2, C72.2, C73.1, C74.1, C75.1, C76.2, C78.2, C79.2, C95.2, C99.1, C103.2, C104.2, C105.2, C106.2, C107.2, C108.1, J3.2, J3.4, J3.6, J3.8, J4.6, J5.2, J15.4, J25.2, J36.1, J40.9, J40.10, J40.12, J40.14, J40.16, J40.18, J40.20, J40.22, J40.23, J46.1, JP1.1 (A), JP2.2, JP3.02, JP3.04, JP3.06, R33.1, R34.1, R35.1, R36.1, R37.1, R38.1, R39.1, R40.1, R41.1, R42.1, R43.1, R44.1, R45.1, R46.1, R47.1, R48.1, R49.2, R52.2, R63.1, R64.1, R65.1, R66.1, R123.2, R174.1, R175.1, SW4.1, SW5.1, TP5.1, U5.10 (VSS), U5.15 (A0), U5.16 (A1), U5.17 (A2), U6.4 (GND1), U7.1 (GND), U7.17 (GND), U7.32 (GND), U8.4 (GND1), U9.4 (GND), U10.2 (GND1), U10.8 (GND1), U39.2 (GND1), U39.8 (GND1), U40.1 (GND), U47.1 (GND), U48.4 (GND), U48.9 (Pad), U49.3 (GNDD), U50.1 (GND), U52.3 (VSS), U53.3 (GNDD), U54.3 (GNDD), U55.4 (GND)
unnamed: C5.2, R53.1, R54.1, R55.1, R56.1
unnamed: C6.2, R57.1, R58.1, R59.1, R60.1
unnamed: C90.2, J6.S
unnamed: C91.2, J7.S
unnamed: C94.2, R164.2, R166.2, R167.2, R168.2
unnamed: C100.2, JP3.01
unnamed: C101.1, JP3.03
unnamed: C102.1, JP3.05
unnamed: C48.1, C52.1, C53.1, C54.1, C55.1, C56.1, C57.1, C58.1, D1.1 (A1), D2.1 (A1), D3.1 (A1), D4.1 (A1), D5.1 (A1), D6.1 (A1), D7.1 (A1), D8.1 (A1), J1.9, J1.10, U1.2, U1.4, U1.6, U1.8, U2.2, U2.4, U2.6, U2.8
unnamed: C48.2, D1.2 (A2), R1.1, R17.2
unnamed: C52.2, D2.2 (A2), R2.1, R18.2
unnamed: C53.2, D3.2 (A2), R3.1, R19.2
unnamed: C54.2, D4.2 (A2), R4.1, R20.2
unnamed: C55.2, D5.2 (A2), R5.1, R21.2
unnamed: C56.2, D6.2 (A2), R6.1, R22.2
unnamed: C57.2, D7.2 (A2), R7.1, R23.2
unnamed: C58.2, D8.2 (A2), R8.1, R24.2
unnamed: C59.2, D9.2 (A2), R9.1, R25.2
unnamed: C59.1, C60.1, C61.1, C62.1, C63.1, C64.1, C65.1, C66.1, D9.1 (A1), D10.1 (A1), D11.1 (A1), D12.1 (A1), D13.1 (A1), D14.1 (A1), D15.1 (A1), D16.1 (A1), J2.9, J2.10, U3.2, U3.4, U3.6, U3.8, U4.2, U4.4, U4.6, U4.8
unnamed: C60.2, D10.2 (A2), R10.1, R26.2
unnamed: C61.2, D11.2 (A2), R11.1, R27.2
unnamed: C62.2, D12.2 (A2), R12.1, R28.2
unnamed: C63.2, D13.2 (A2), R13.1, R29.2
unnamed: C64.2, D14.2 (A2), R14.1, R30.2
unnamed: C65.2, D15.2 (A2), R15.1, R31.2
unnamed: C66.2, D16.2 (A2), R16.1, R32.2
unnamed: D17.2 (A), R17.1
unnamed: D17.1 (K), D88.2 (A)
unnamed: D18.2 (A), R18.1
unnamed: D18.1 (K), D89.2 (A)
unnamed: D19.2 (A), R19.1
unnamed: D19.1 (K), D90.2 (A)
unnamed: D20.2 (A), R20.1
unnamed: D20.1 (K), D91.2 (A)
unnamed: D21.2 (A), R21.1
unnamed: D21.1 (K), D92.2 (A)
unnamed: D22.2 (A), R22.1
unnamed: D22.1 (K), D93.2 (A)
unnamed: D23.2 (A), R23.1
unnamed: D23.1 (K), D94.2 (A)
unnamed: D24.2 (A), R24.1
unnamed: D24.1 (K), D95.2 (A)
unnamed: D25.2 (A), R25.1
unnamed: D25.1 (K), D96.2 (A)
unnamed: D26.2 (A), R26.1
unnamed: D26.1 (K), D97.2 (A)
unnamed: D27.2 (A), R27.1
unnamed: D27.1 (K), D98.2 (A)
unnamed: D28.2 (A), R28.1
unnamed: D28.1 (K), D99.2 (A)
unnamed: D29.2 (A), R29.1
unnamed: D30.2 (A), R30.1
unnamed: D31.2 (A), R31.1
unnamed: D32.2 (A), R32.1
unnamed: D38.1 (K), R63.2
unnamed: D39.1 (K), R64.2
unnamed: D40.1 (K), R65.2
unnamed: D41.1 (K), R66.2
unnamed: D50.1 (K), U49.4
unnamed: D88.1 (K), U1.1
unnamed: D89.1 (K), U1.3
unnamed: D90.1 (K), U1.5
unnamed: D91.1 (K), U1.7
unnamed: D92.1 (K), U2.1
unnamed: D93.1 (K), U2.3
unnamed: D94.1 (K), U2.5
unnamed: D95.1 (K), U2.7
unnamed: D96.1 (K), U3.1
unnamed: D97.1 (K), U3.3
unnamed: D98.1 (K), U3.5
unnamed: D99.1 (K), U3.7
unnamed: D29.1 (K), D100.2 (A)
unnamed: D100.1 (K), U4.1
unnamed: D30.1 (K), D101.2 (A)
unnamed: D101.1 (K), U4.3
unnamed: D31.1 (K), D102.2 (A)
unnamed: D102.1 (K), U4.5
unnamed: D32.1 (K), D103.2 (A)
unnamed: D103.1 (K), U4.7
unnamed: D122.2 (A), U53.4
unnamed: D122.1 (K), R174.2
unnamed: D123.2 (A), U54.4
unnamed: D123.1 (K), R175.2
unnamed: J1.1, R8.2
unnamed: J1.2, R7.2
unnamed: J1.3, R6.2
unnamed: J1.4, R5.2
unnamed: J1.5, R4.2
unnamed: J1.6, R3.2
unnamed: J1.7, R2.2
unnamed: J1.8, R1.2
unnamed: J2.1, R16.2
unnamed: J2.2, R15.2
unnamed: J2.3, R14.2
unnamed: J2.4, R13.2
unnamed: J2.5, R12.2
unnamed: J2.6, R11.2
unnamed: J2.7, R10.2
unnamed: J2.8, R9.2
unnamed: F1.1, J9.3
unnamed: J12.1, J16.10
unnamed: J12.2, J16.9
unnamed: J12.3, J16.8
unnamed: J12.4, J16.7
unnamed: J12.5, J16.6
unnamed: J12.6, J16.5
unnamed: J12.7, J16.4
unnamed: J12.9, J16.3
unnamed: J12.8, J12.10, J12.11, J12.12, J12.13, J16.2
unnamed: J12.14, J12.15, J16.1, J52.1
unnamed: J14.1, J17.10
unnamed: J14.2, J17.9
unnamed: J14.3, J17.8
unnamed: J14.4, J17.7
unnamed: J14.5, J17.6
unnamed: J14.6, J17.5
unnamed: J14.7, J17.4
unnamed: J14.9, J17.3
unnamed: J14.8, J14.10, J14.11, J14.12, J14.13, J17.2
unnamed: J14.14, J14.15, J17.1
unnamed: J7.2, JP6.2 (C)
unnamed: C50.1, C78.1, L2.1, Q1.3 (D)
unnamed: Q1.1 (G), R171.2
unnamed: R53.2, R54.2, SW1.2
unnamed: R55.2, R56.2, SW1.1
unnamed: R57.2, R58.2, SW2.2
unnamed: R59.2, R60.2, SW2.1
unnamed: R164.1, R168.1, SW3.4
unnamed: R166.1, R167.1, SW3.3
unnamed: R158.1, U5.14 (SO)
unnamed: R132.2, U7.12 (10_CS_MQSR)
unnamed: R150.2, U7.13 (11_MOSI_CTX1)
unnamed: R151.2, U7.20 (13_SCK_CRX1_LED)
unnamed: R152.2, U7.21 (14_A0_TX3_SPDIF_OUT)
unnamed: R153.2, U7.22 (15_A1_RX3_SPDIF_IN)
unnamed: R154.2, U7.26 (19_A5_SCL0)
unnamed: R155.2, U7.27 (20_A6_TX5_LRCLK1)
unnamed: R163.2, U10.12 (A)
unnamed: R165.2, U10.13 (B)
unnamed: U10.7 (PV), U47.2 (~RESET)
unnamed: R118.1, U39.7 (VE1)
unnamed: R119.1, U39.10 (VE2)
unnamed: R160.1, U39.11 (VID)
unnamed: R159.1, U39.14 (VOA)
unnamed: R161.1, U39.13 (VOB)
unnamed: R162.1, U39.12 (VOC)
unnamed: R131.2, U39.6 (VOD)
unnamed: C100.1, C101.2, C102.2, U48.2 (CWD)
unnamed: JP2.1, R172.2, U48.5 (SET1)
unnamed: C74.2, U50.5 (CV)
unnamed: C76.1, R133.1, U50.6 (THR), U50.7 (DIS)
unnamed: C106.1, U52.5 (CD)
PE: C5.1, C6.1, C90.1, C91.1, C92.2, C93.1, C94.1, D42.1 (A1), D43.1 (A1), J9.1, J10.1, J27.1, J40.1, J40.2, J40.3, J40.4, J40.24, J41.1, J42.1, J43.1, J44.1, J45.1, J61.1, J62.1, RV2.1, RV3.1, RV4.1, RV5.1, RV6.1

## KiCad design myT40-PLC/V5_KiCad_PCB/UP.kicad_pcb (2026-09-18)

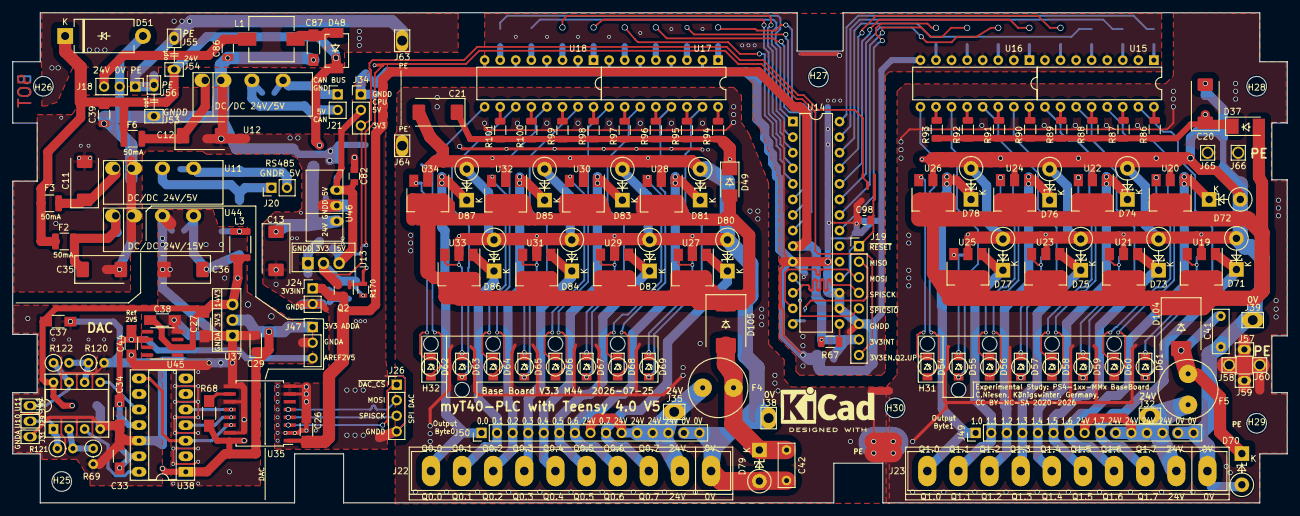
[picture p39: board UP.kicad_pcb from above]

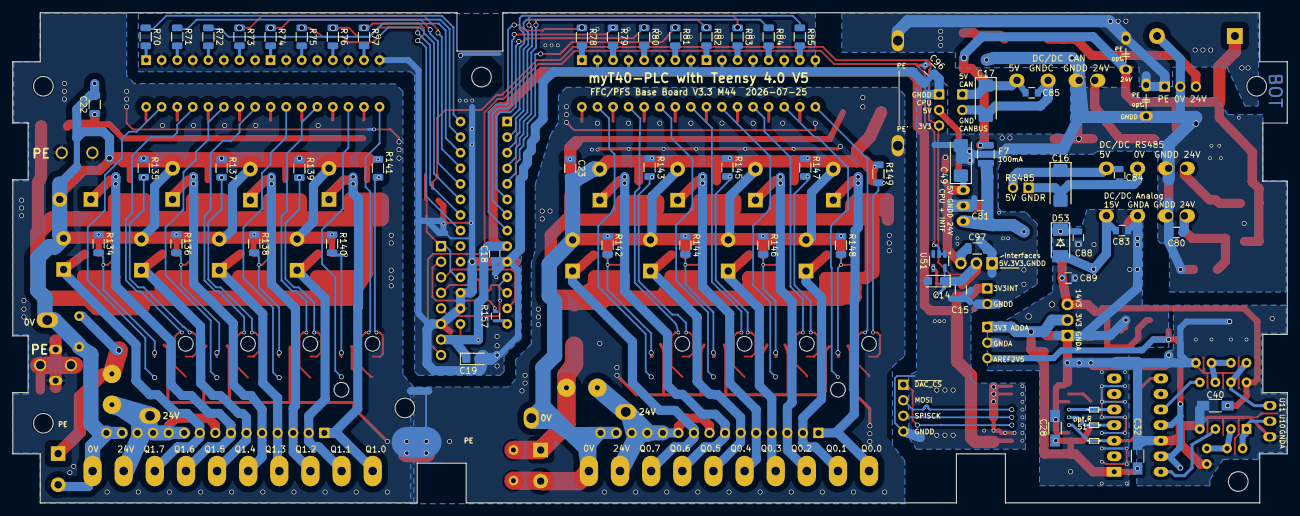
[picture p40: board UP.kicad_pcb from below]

Board: 2 copper layers, 208.0 x 80.0 mm, 221 parts (57 on the bottom side), 148 nets.

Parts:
A1: KiCad Symbol; KiCad-Logo2_6mm_SilkScreen
C11, C12, C13, C35: 10µ 50V; CP_EIA-7343-31_Kemet-D
C14: 22µ 6V3; CP_EIA-3216-18_Kemet-A
C15, C39: 100n 50V; C_1206_3216Metric
C16, C17, C49: 22µ 10V; CP_EIA-6032-28_Kemet-C
C18, C96: 100n; C_0805
C19: 2µ2 16V; CP_EIA-3216-18_Kemet-A
C20, C21: 2µ2 50V; CP_EIA-7343-31_Kemet-D
C22, C23, C86, C97: 100n; C_1206_3216Metric
C26, C27, C28, C32, C33, C34, C37, C38, C40, C44, C87: 100n; C_1206_HandSoldering
C29: 10µ 10V; CP_EIA-3216-18_Kemet-A
C36: 22µ 25V; CP_EIA-7343-31_Kemet-D
C41, C42: 100n; C_Rect_L7.0mm_W2.5mm_P5.00mm
C80, C81, C82, C83, C84, C85, C88, C89: 100n 50V; C_0805
C98: 100n; C_0805_2012Metric
D37, D49: 1N4448W7F DII; Diode_DO213AB-MELF_SOD123
D48: MBRS 1100 SMD; DO-214AA_Schottky_man
D51: 1.5KE27CA; D_DO-201_P12.70mm_Horizontal
D53: 1N4007 SMD; Diode_DO213AB-MELF_SOD123
D54, D55, D56, D57, D58, D59, D60, D61, D62, D63, D64, D65, D66, D67, D68, D69: KPTD-3216; D_1206_4.5
D70, D71, D72, D73, D74, D75, D76, D77, D78, D79, D80, D81, D82, D83, D84, D85, D86, D87: P6KE33CA; D_DO-15_P5.08mm_Vertical_KathodeUp
D104, D105: SK86; D_SMC
F2, F3, F6: 50mA; R_1210_3225Metric
F4, F5: 5,6AT; Sockel_Kleinst-F
F7: 100mA; R_1210_3225Metric
H25, H26, H27, H28, H29, H30: MountingHole; MountingHole_3.2mm_M3
H31, H32: LED-Licht-Leiter_8x3mm_P5.08; MEN-LED-Lichtleiter_8x3mm_P5.08_5v8
J18, J34, J47: 01x03_Male; PinHeader_1x03_P2.54mm_Vertical
J19: 01x08_Male; PinHeader_1x08_P2.54mm_Vertical
J20, J21, J24: 01x02_Male; PinHeader_1x02_P2.54mm_Vertical
J22, J23: opt. Connector; TerminalBlock_Phoenix_MSTBVA-2.5-10-5.08_1x10_P5.08mm_Horiz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
J26: 01x04_Male; PinHeader_1x04_P2.54mm_Vertical
J29: DAC 3pol J29-J31; Lötauge-Junction
J30, J31, J53, J54, J55, J56, J57, J59: Lötauge; Lötauge-Junction
J32, J35, J38, J39: Lötauge; Lötauge-Junction-3.5x2.5-1.6
J49, J50: 01x15 Male zu OP; PinHeader_1x15_P2.54mm_Vertical
J58, J60, J65: Lötauge; Lötauge-Junction-2x2-1.4
J63, J64: Lötauge; Lötauge-Junction-3.5x2.0-1.6
J66: Flachstecker; Lötauge-Junction-2x2-1.4
L1: PIS2812-271M-04; L_7.3x7.3_H3.5_handsoldered
L3: L-1812AF 330µ 100mA; L_1812_4532Metric
Q2: IRLML 2244; SOT-23
R67: 10k; R_1206_3216Metric
R68: 10k; R_1206_HandSoldering
R69, R120: 1k 0,1%; R_Axial_DIN0207_L6.3mm_D2.5mm_P2.54mm_Vertical
R70, R71, R72, R73, R74, R75, R76, R77, R78, R79, R80, R81, R82, R83, R84, R85: 1650; R_1206_3216Metric
R86, R87, R88, R89, R90, R91, R92, R93, R94, R95, R96, R97, R98, R99, R100, R101, R134, R135, R136, R137, R138, R139, R140, R141, R142, R143, R144, R145, R146, R147, R148, R149: 7k5; R_1206_3216Metric
R121, R122: 3k0 0,1%; R_Axial_DIN0207_L6.3mm_D2.5mm_P2.54mm_Vertical
R157: 51; R_0603
R170: 10k; R_0805
U11, U12: 2S7WA_2405_S3RP; SIP-7_2S7WA
U13, U37: LT1086 3.3; TO-220-3_Vertical
U14: MCP23S17; DIP-28_W7.62mm
U15, U16, U17, U18: LTV-844; DIP-16_W7.62mm_cut
U19, U20, U21, U22, U23, U24, U25, U26, U27, U28, U29, U30, U31, U32, U33, U34: BSP-452; SOT-223
U35: ADuM1401xRW; SOIC-16W_7.5x10.3mm_Pitch1.27mm_handsoldered
U38: MCP4922; DIP-14_W7.62mm_Socket_LongPads
U41: LT 1078; DIP-8_W7.62mm_Socket
U44: 2S7WB_2415S3RP; SIP-7_2S7WA
U45: ADR03ARZ; SOIC-8_3.9x4.9mm_P1.27mm
U46: LCN78_05-1.0; SIP-3-LC78
U51: SN74LV1T08; SOT-23-5

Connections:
3V3: C14.1, C15.1, J34.3, Q2.2 (S), R170.2, U13.2 (VO), U51.5 (3V3)
/3V3EN_Q2_UP: C96.1, J19.8, U51.1, U51.2
/3V3_ADDA: C28.2, C29.1, C32.2, J47.1, R68.1, U35.16 (VDD2), U37.2 (VO), U38.1 (VDD)
/3V3_INT: C18.2, C19.1, C26.2, J19.7, J24.1, Q2.3 (D), R67.1, U14.9 (VDD), U35.1 (VDD1)
/5V_CPU: C49.1, C82.1, C97.1, J34.2, U13.3 (VI), U46.3 (OUT)
/12V_ADDA: C27.2, C37.2, C38.2, C40.2, C89.1, L3.1, U37.3 (VI), U41.8 (V+), U45.2 (IN)
/24V: C39.1, D48.1 (K), D51.1 (A1), F2.2, F3.2, F6.2, F7.2, J54.1
/24V_F4: C42.1, D79.1 (A1), D105.2 (A), F4.2
/24V_F5: C41.1, D70.1 (A1), D104.2 (A), F5.2
/24V_OPT_1: C20.1, C22.1, D37.1 (K), R86.1, R87.1, R88.1, R89.1, R90.1, R91.1, R92.1, R93.1
/24V_OPT_2: C21.1, C23.1, D49.1 (K), R94.1, R95.1, R96.1, R97.1, R98.1, R99.1, R100.1, R101.1
/24V_Out_0: D49.2 (A), D105.1 (K), U27.4 (VCC), U28.4 (VCC), U29.4 (VCC), U30.4 (VCC), U31.4 (VCC), U32.4 (VCC), U33.4 (VCC), U34.4 (VCC)
/24V_Out_1: D37.2 (A), D104.1 (K), U19.4 (VCC), U20.4 (VCC), U21.4 (VCC), U22.4 (VCC), U23.4 (VCC), U24.4 (VCC), U25.4 (VCC), U26.4 (VCC)
/AREF_2V5: C33.2, C34.2, C44.2, J47.3, U38.11 (VrefB), U38.13 (VrefA), U45.6 (OUT)
/DAC_A: U38.14 (VoutA), U41.3 (+)
/DAC_B: U38.10 (VoutB), U41.5 (+)
/DAC_OUT_A: J29.1, R121.1, U41.1
/DAC_OUT_B: J30.1, R122.1, U41.7
/GNDPWR_Out_0: C21.2, C23.2, C42.2, D79.2 (A2), D80.2 (A2), D81.2 (A2), D82.2 (A2), D83.2 (A2), D84.2 (A2), D85.2 (A2), D86.2 (A2), D87.2 (A2), J22.1, J38.1, J50.14, J50.15, R142.1, R143.1, R144.1, R145.1, R146.1, R147.1, R148.1, R149.1, U27.2 (GND), U28.2 (GND), U29.2 (GND), U30.2 (GND), U31.2 (GND), U32.2 (GND), U33.2 (GND), U34.2 (GND)
/GNDPWR_Out_1: C20.2, C22.2, C41.2, D70.2 (A2), D71.2 (A2), D72.2 (A2), D73.2 (A2), D74.2 (A2), D75.2 (A2), D76.2 (A2), D77.2 (A2), D78.2 (A2), J23.1, J39.1, J49.14, J49.15, R134.1, R135.1, R136.1, R137.1, R138.1, R139.1, R140.1, R141.1, U19.2 (GND), U20.2 (GND), U21.2 (GND), U22.2 (GND), U23.2 (GND), U24.2 (GND), U25.2 (GND), U26.2 (GND)
/GND_CAN_BUS: C17.2, C85.2, J21.2, U12.4 (Out-)
/GND_RS485_BUS: C16.2, C84.2, J20.1, U11.4 (Out-)
/MISO: J19.2, R157.1
/MOSI: J19.3, J26.2, U14.13 (SI), U35.5 (VIC)
/O_GPA0: R77.1, U14.21 (GPA0)
/O_GPA1: R76.1, U14.22 (GPA1)
/O_GPA2: R75.1, U14.23 (GPA2)
/O_GPA3: R74.1, U14.24 (GPA3)
/O_GPA4: R73.1, U14.25 (GPA4)
/O_GPA5: R72.1, U14.26 (GPA5)
/O_GPA6: R71.1, U14.27 (GPA6)
/O_GPA7: R70.1, U14.28 (GPA7)
/O_GPB0: R85.1, U14.1 (GPB0)
/O_GPB1: R84.1, U14.2 (GPB1)
/O_GPB2: R83.1, U14.3 (GPB2)
/O_GPB3: R82.1, U14.4 (GPB3)
/O_GPB4: R81.1, U14.5 (GPB4)
/O_GPB5: R80.1, U14.6 (GPB5)
/O_GPB6: R79.1, U14.7 (GPB6)
/O_GPB7: R78.1, U14.8 (GPB7)
/PE: J18.1, J55.1, J56.1, J57.1, J58.1, J59.1, J60.1, J63.1, J64.1, J65.1, J66.1
/SPISCK: J19.4, J26.3, U14.12 (SCK), U35.4 (VIB)
/Ub_5V_RS485_BUS: C16.1, C84.1, J20.2, U11.6 (Out+)
/Ub_CAN_BUS: C17.1, C85.1, J21.1, U12.6 (Out+)
/~RESET: C98.2, J19.1, U14.18 (~RESET)
/~SPICS_DAC: J26.1, U35.3 (VIA)
/~SPICS_IO: J19.5, U14.11 (~CS)
GNDA: C27.1, C28.1, C29.2, C32.1, C33.1, C34.1, C36.2, C37.1, C38.1, C40.1, C44.1, C83.2, C88.2, C89.2, J31.1, J47.2, R69.2, R120.2, U35.9 (GND2), U35.11 (VID), U35.15 (GND2), U37.1 (GND), U38.12 (AVSS), U41.4 (V-), U44.4 (Out-), U45.4 (GND)
GNDD: C11.2, C12.2, C13.2, C14.2, C15.2, C18.1, C19.2, C26.1, C35.2, C39.2, C49.2, C80.2, C81.2, C82.2, C86.1, C87.1, C96.2, C97.2, C98.1, D51.2 (A2), J18.2, J19.6, J24.2, J26.4, J34.1, J53.1, U11.2 (In-), U12.2 (In-), U13.1 (GND), U14.10 (VSS), U14.16 (A1), U14.17 (A2), U15.2, U15.4, U15.6, U15.8, U16.2, U16.4, U16.6, U16.8, U17.2, U17.4, U17.6, U17.8, U18.2, U18.4, U18.6, U18.8, U35.2 (GND1), U35.7 (VE1), U35.8 (GND1), U44.2 (In-), U46.2 (GND), U51.3 (GNDD)
unnamed: C87.2, D48.2 (A), L1.1
unnamed: C36.1, C83.1, D53.2 (A), U44.6 (Out+)
unnamed: C88.1, D53.1 (K), L3.2
unnamed: D54.2 (A), U16.9
unnamed: D54.1 (K), R141.2, U26.3 (IN)
unnamed: D55.2 (A), U16.11
unnamed: D55.1 (K), R140.2, U25.3 (IN)
unnamed: D56.2 (A), U16.13
unnamed: D56.1 (K), R139.2, U24.3 (IN)
unnamed: D57.2 (A), U16.15
unnamed: D57.1 (K), R138.2, U23.3 (IN)
unnamed: D58.2 (A), U15.9
unnamed: D58.1 (K), R137.2, U22.3 (IN)
unnamed: D59.2 (A), U15.11
unnamed: D59.1 (K), R136.2, U21.3 (IN)
unnamed: D60.2 (A), U15.13
unnamed: D60.1 (K), R135.2, U20.3 (IN)
unnamed: D61.2 (A), U15.15
unnamed: D61.1 (K), R134.2, U19.3 (IN)
unnamed: D62.2 (A), U18.9
unnamed: D62.1 (K), R149.2, U34.3 (IN)
unnamed: D63.2 (A), U18.11
unnamed: D63.1 (K), R148.2, U33.3 (IN)
unnamed: D64.2 (A), U18.13
unnamed: D64.1 (K), R147.2, U32.3 (IN)
unnamed: D65.2 (A), U18.15
unnamed: D65.1 (K), R146.2, U31.3 (IN)
unnamed: D66.2 (A), U17.9
unnamed: D66.1 (K), R145.2, U30.3 (IN)
unnamed: D67.2 (A), U17.11
unnamed: D67.1 (K), R144.2, U29.3 (IN)
unnamed: D68.2 (A), U17.13
unnamed: D68.1 (K), R143.2, U28.3 (IN)
unnamed: D69.2 (A), U17.15
unnamed: D69.1 (K), R142.2, U27.3 (IN)
unnamed: D71.1 (A1), J23.3, J49.9, U19.1 (OUT)
unnamed: D72.1 (A1), J23.4, J49.7, U20.1 (OUT)
unnamed: D73.1 (A1), J23.5, J49.6, U21.1 (OUT)
unnamed: D74.1 (A1), J23.6, J49.5, U22.1 (OUT)
unnamed: D75.1 (A1), J23.7, J49.4, U23.1 (OUT)
unnamed: D76.1 (A1), J23.8, J49.3, U24.1 (OUT)
unnamed: D77.1 (A1), J23.9, J49.2, U25.1 (OUT)
unnamed: D78.1 (A1), J23.10, J49.1, U26.1 (OUT)
unnamed: D80.1 (A1), J22.3, J50.9, U27.1 (OUT)
unnamed: D81.1 (A1), J22.4, J50.7, U28.1 (OUT)
unnamed: D82.1 (A1), J22.5, J50.6, U29.1 (OUT)
unnamed: D83.1 (A1), J22.6, J50.5, U30.1 (OUT)
unnamed: D84.1 (A1), J22.7, J50.4, U31.1 (OUT)
unnamed: D85.1 (A1), J22.8, J50.3, U32.1 (OUT)
unnamed: D86.1 (A1), J22.9, J50.2, U33.1 (OUT)
unnamed: D87.1 (A1), J22.10, J50.1, U34.1 (OUT)
unnamed: C86.2, J18.3, L1.2
unnamed: F4.1, J22.2, J35.1, J50.8, J50.10, J50.11, J50.12, J50.13
unnamed: F5.1, J23.2, J32.1, J49.8, J49.10, J49.11, J49.12, J49.13
unnamed: Q2.1 (G), R170.1, U51.4
unnamed: R70.2, U15.1
unnamed: R71.2, U15.3
unnamed: R72.2, U15.5
unnamed: R73.2, U15.7
unnamed: R74.2, U16.1
unnamed: R75.2, U16.3
unnamed: R76.2, U16.5
unnamed: R77.2, U16.7
unnamed: R78.2, U17.1
unnamed: R79.2, U17.3
unnamed: R80.2, U17.5
unnamed: R81.2, U17.7
unnamed: R82.2, U18.1
unnamed: R83.2, U18.3
unnamed: R84.2, U18.5
unnamed: R85.2, U18.7
unnamed: R86.2, U15.16
unnamed: R87.2, U15.14
unnamed: R88.2, U15.12
unnamed: R89.2, U15.10
unnamed: R90.2, U16.16
unnamed: R91.2, U16.14
unnamed: R92.2, U16.12
unnamed: R93.2, U16.10
unnamed: R94.2, U17.16
unnamed: R95.2, U17.14
unnamed: R96.2, U17.12
unnamed: R97.2, U17.10
unnamed: R98.2, U18.16
unnamed: R99.2, U18.14
unnamed: R100.2, U18.12
unnamed: R101.2, U18.10
unnamed: C11.1, F3.1, U11.1 (In+)
unnamed: C12.1, F6.1, U12.1 (In+)
unnamed: R67.2, U14.15 (A0)
unnamed: R157.2, U14.14 (SO)
unnamed: R68.2, U35.10 (VE2)
unnamed: U35.14 (VOA), U38.3 (~CS), U38.8 (~LDAC)
unnamed: U35.13 (VOB), U38.4 (SCK)
unnamed: U35.12 (VOC), U38.5 (SDI)
unnamed: R69.1, R121.2, U41.2 (-)
unnamed: R120.1, R122.2, U41.6 (-)
unnamed: C35.1, C80.1, F2.1, U44.1 (In+)
unnamed: C13.1, C81.1, F7.1, U46.1 (IN)

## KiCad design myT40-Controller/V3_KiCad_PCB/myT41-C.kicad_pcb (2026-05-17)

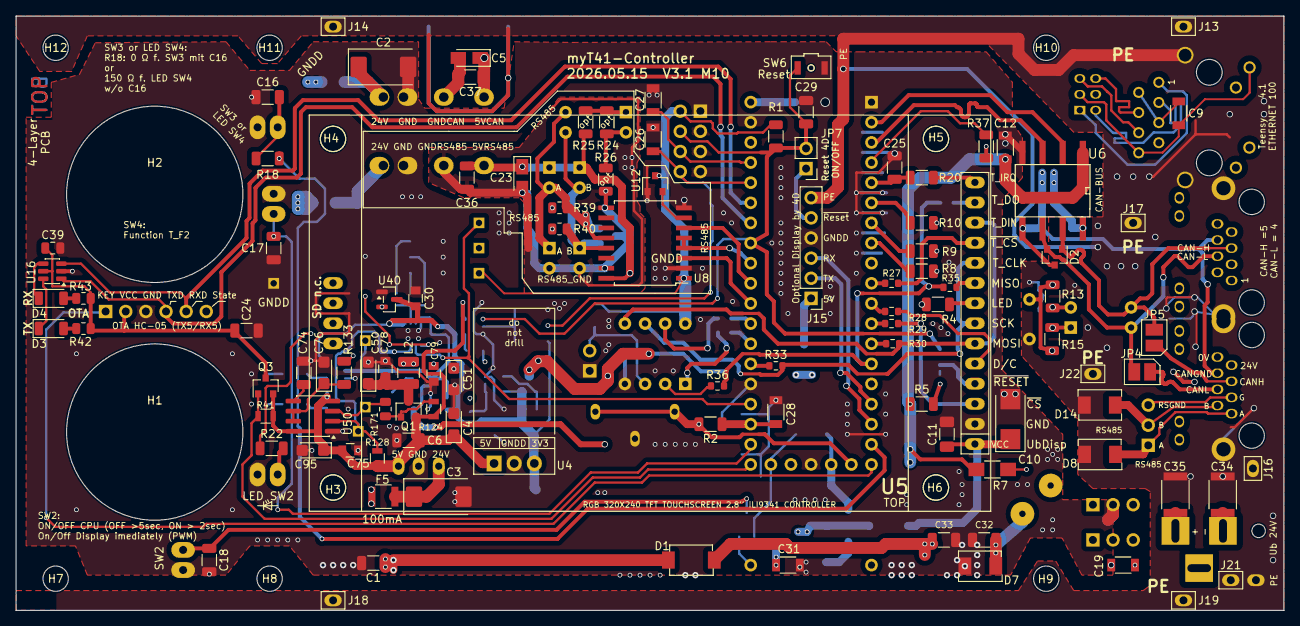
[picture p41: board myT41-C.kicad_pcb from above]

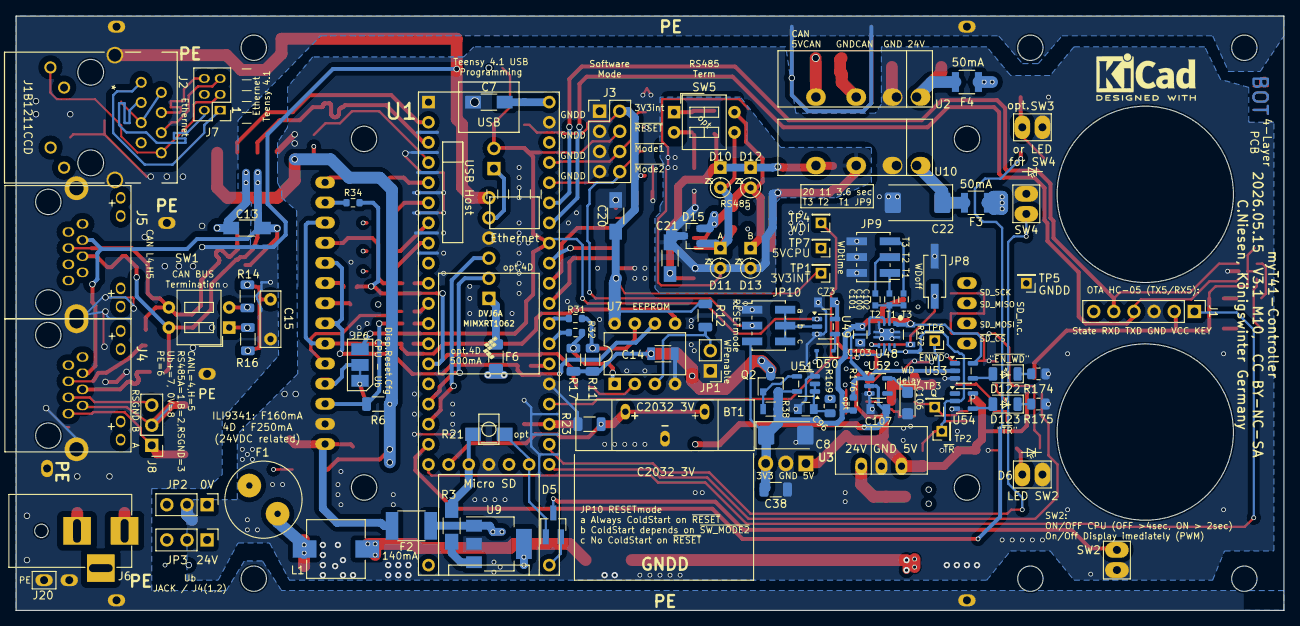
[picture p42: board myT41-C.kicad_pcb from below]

Board: 4 copper layers, 160.0 x 75.0 mm, 209 parts (94 on the bottom side), 132 nets.

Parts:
A1: mySymbol; KiCad-Logo2_6mm_SilkScreen
BT1: 3V Lithium 2032; BAT_2032
C1, C6, C16, C17, C18, C24, C25, C29, C36, C37, C38: KEM X7R, 100n 50V; C_1206_3216Metric
C2, C3, C22: T491D Tantal, 10µF, 50V; CP_EIA-7343-31_Kemet-D
C4: TAJ 3516 22/10; CP_EIA-3216-18_Kemet-A
C5, C23: TAJ 3516 22/10; CP_Tantalum_Case-A_EIA-3216-18_Reflow
C7, C13, C20, C21: KEM X7R, 100n 50V; C_1206_HandSoldering
C8: T495D 100µF, 10V; CP_EIA-6032-28_Kemet-C
C9: KEM X7R 100n 50V; C_1206
C10: T495D 22µF 10V; CP_Tantalum_Case-C_EIA-6032-28_Reflow
C11: KEM X7R 100n 50V; C_1206_3216Metric_Pad1.33x1.80mm_HandSolder
C12, C14, C26, C27, C28, C31: KEM X7R, 100n 50V; C_1206
C15: 4n7; C_Rect_L7.0mm_W2.5mm_P5.00mm
C19: KEM X7R, 100n 100V; C_1206
C30, C73, C75, C96, C103, C107: 100n; C_0805
C32, C33: 100n 100V; C_1206_3216Metric
C34, C35: 2n2 Y3; C_1812
C39: KEM X7R 100n 50V; C_0805_2012Metric
C50, C51: 4µ7 16V; CP_EIA-3216-18_Kemet-A
C74: 10n; C_1206_3216Metric
C76, C95: 10µ 10V; CP_EIA-3216-18_Kemet-A
C78, C79: 2,2pF; C_0805
C100: 47n; C_0603
C101: 150n; C_0603
C102: 270n; C_0603
C106: 3µ3 10V; CP_EIA-3216-18_Kemet-A
D1: MBRS 1100 SMD; DO-214AA_Schottky_man
D2, D15: SZNUP2105LT1G; SOT-23
D3, D4, D122, D123: APTD3216; LED_1206_3216_big-gap
D5: BAT54C; SOT-23_Handsoldering
D6: LED_SW2; Lötauge-Junction-Dual-3x2
D7: SM6T 30CA STM; DO-214AA
D8, D14: P6SMB 5,0CA; DO-214AA
D10, D11, D12, D13: BAT46; D_DO-35_SOD27_P2.54mm_Vertical_KathodeUp
D50: RB751V40T1G; D_SOD-323
F1: 160mA F; Sockel_Kleinst-F
F2: Ih=140mA (PTC FSMD014R); R_1812
F3, F4: Ih=50mA; R_1210
F5: Ih=100mA; R_1210
F6: Ih=500mA (PTS12066V050); C_1206_3216Metric_Pad1.33x1.80mm_HandSolder
H1, H2, H3, H4, H5: MountingHole; MountingHole_3mm
H6, H7, H8, H9, H10, H11, H12: MountingHole; MountingHole_3.2mm_M3_DIN965
J1: Connector OTA HC-05; PinHeader_1x06_P2.54mm_Vertical
J2: J1B1211CCD; RJ45_J1B1211CCD
J3: 02x04-OE; PinHeader_2x04_P2.54mm_Vertical
J4, J5: 8P8C_LED_Shielded; RJ45-LED
J6: Barrel-Jack; BARREL_JACK_5.5_2.1
J7: <<-- Kabel; PinHeader_2x03_P2.00mm_Vertical
J8: drilled wire; PinHeader_1x03_P2.54mm_Vertical
J13, J14, J17, J18, J19: Conn_01x01; Lötauge-Junction
J15: Connector 4D gen4; PinHeader_1x06_P2.54mm_Vertical
J16, J20, J21, J22: Lötpunkt; Lötauge-Junction
JP1: WriteProtection; PinHeader_1x02_P2.54mm_Vertical
JP2: 0V CAN / JACK; PinHeader_1x03_P2.54mm_Vertical
JP3: 24V J4/JACK; PinHeader_1x03_P2.54mm_Vertical
JP4: CAN-L; Solder-Junction-2,2x1,5
JP5: CAN-H; Solder-Junction-2,2x1,5
JP6: DisplayResetConfig; Solder-Junction-3x2.2x1.5_1-2-closed
JP7: Reset enable; PinHeader_1x02_P2.54mm_Vertical
JP8: Jumper_NC_Small; PinHeader_2x01_P2.54mm_Vertical_SMD
JP9: Watchdog Time; PinHeader_2x03_P2.00mm_Vertical_SMD
JP10: Restart Mode on ~{RESET}; PinHeader_2x03_P2.00mm_Vertical_SMD
L1: 270µH; L_7.3x7.3_H3.5_handsoldered
L2: 47µH; L_1210_3225Metric
Q1, Q2, Q3: IRLML 2244; SOT-23
R1, R5, R6, R11, R12, R17: 3K3; R_1206_3216Metric
R2, R23: 680k; R_1206_3216Metric
R3: 270; R_1206_HandSoldering
R4: 470; R_1206_3216Metric
R7: 150; R_1206_HandSoldering
R8, R9, R10, R18, R22, R37: 150; R_1206_3216Metric
R13, R14, R15, R16, R24: 120; R_1206_3216Metric
R20: 10K; R_1206_3216Metric
R21: (3K3 opt); R_1206_HandSoldering
R25, R26: 730; R_1206_3216Metric
R27, R28, R29, R30, R31, R32, R33, R34, R35, R36: 51; R_0603_1608Metric
R38, R41, R124: 10k; R_0805
R39, R40, R169, R171: 10; R_0805_2012Metric
R42, R43: 3K3; R_0805_2012Metric
R128: 47k; R_0805
R133: 220k; R_1206_3216Metric
R172: 1k; R_1206_vertical
R174: 1650; R_0805_2012Metric
R175: 3k3; R_0805_2012Metric
R176: 10k; R_0603_1608Metric
SW1, SW5: SW_DIP_x02; SW_DIP_x2_W7.62mm_Slide_LowProfile
SW2: On/Off; Lötauge-Junction-Dual-3x2
SW3: F1; Lötauge-Junction-Dual-3x2
SW4: F2; Lötauge-Junction-Dual-3x2
SW6: Reset; switch-tactil_OMRON_B3U-3000P
TP1: 3V3int; PinHeader_1x01_P2.00mm_Vertical
TP2: TR; PinHeader_1x01_P2.00mm_Vertical
TP3: Q; PinHeader_1x01_P2.00mm_Vertical
TP4: WDI; PinHeader_1x01_P2.00mm_Vertical
TP5: GNDD; PinHeader_1x01_P2.00mm_Vertical
TP6: EN_WD; PinHeader_1x01_P2.00mm_Vertical
TP7: 5V_CPU; PinHeader_1x01_P2.00mm_Vertical
U1: Teensy4.1; Teensy41_mod
U2, U10: 2S7WA_2405_S3RP; SIP-7_2S7WA
U3: LC78_05-1.0; SIP-3-LC78
U4: LM 3940 IT3,3; TO-220-3_Vertical
U5: ili9341_touch; ILI9341
U6: ISO1050DUB; SOP-8
U7: 25LC512-I/P; DIP-8_W7.62mm
U8: ADM2483xRW; SOIC-16W_7.5x10.3mm_Pitch1.27mm_handsoldered
U9: BSP-452; SOT-223
U12: ADM-809Z; SOT-23
U16: 74LVC2G07; SOT-23-6
U40: ADM-803S; SOT-23
U48: TPS3431; VSON-8_EP_2.8x2.8_Pitch0.65mm
U49: SN74LV1T32; SOT-23-5
U50: NE555DRG4; SOIC-8_3.9x4.9mm_P1.27mm
U51: SN74LV1T08; SOT-23-5
U52: S-80929CNMC; SOT-23-5
U53, U54: BD7LS04G-C; SOT-23-5

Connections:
3V3_INT: C12.1, C14.2, C20.1, C107.1, J3.2, Q2.3 (D), R1.1, R5.1, R6.1, R7.1, R11.1, R12.1, R17.1, TP1.1, U6.1 (VCC1), U7.8 (VCC), U8.1 (VDD1), U12.3 (VCC), U52.2 (VDD)
5V_CPU: C7.1, C51.1, C79.1, L2.2, TP7.1, U1.48 (VIN)
+3V3: C8.1, C30.2, C38.1, C103.2, JP10.5, Q2.2 (S), R38.2, R172.1, R176.1, U4.3 (VO), U40.3 (VCC), U48.1 (VDD), U51.5 (VCC), U53.5 (VCC)
+5V: C4.1, C6.1, C31.1, C73.2, C75.2, C95.1, Q1.2 (S), Q3.2 (S), R41.1, R124.1, R128.2, R133.2, U3.3 (VO), U4.1 (VI), U9.4 (VCC), U49.5 (VCC), U50.4 (R), U50.8 (VCC), U54.5 (VCC)
+24V: C1.1, D1.1 (K), F3.1, F4.1, F5.1
/UpperPCB/BAT_CHECK: C28.1, R2.1, U1.32 (40_A16)
/UpperPCB/CAN1H: D2.1 (A1), J5.5, JP5.2 (B), SW1.3, U6.7 (CANH)
/UpperPCB/CAN1L: D2.2 (A2), J5.4, JP4.2 (B), SW1.4, U6.6 (CANL)
/UpperPCB/CANRX: U1.2 (0_RX1_CRX2_CS1), U6.2 (RXD)
/UpperPCB/CANTX: U1.3 (1_TX1_CTX2_MISO1), U6.3 (TXD)
/UpperPCB/DC: R28.2, U5.5 (D/C)
/UpperPCB/D_LED_PWM: R4.1, U1.9 (7_RX2_OUT1A)
/UpperPCB/D_SLEEP: D5.2, U1.25 (33_MCLK2)
/UpperPCB/D_VCC_ON: R3.1, R21.1, U1.51 (3V3)
/UpperPCB/E24V: C19.1, F1.2, JP3.2
/UpperPCB/ETH_GND: C9.1, J2.8, J2.9, J7.3
/UpperPCB/ETH_LED: J2.10, J7.4
/UpperPCB/ETH_R+: J2.4, J7.6
/UpperPCB/ETH_R-: J2.6, J7.5
/UpperPCB/ETH_T+: J2.1, J7.1
/UpperPCB/ETH_T-: J2.3, J7.2
/UpperPCB/GND_CAN_BUS: C5.2, C13.2, C37.2, D2.3 (common), J4.6, J5.6, U2.4 (Out-), U6.5 (GND2)
/UpperPCB/LED1: R10.1, U1.6 (4_BCLK2)
/UpperPCB/LED2: R9.1, U1.7 (5_IN2)
/UpperPCB/LED3: R8.1, U1.8 (6_OUT1D)
/UpperPCB/LED4: R37.1, U1.4 (2_OUT2)
/UpperPCB/MISO: R34.2, R35.1, R36.1, U1.14 (12_MISO_MQSL)
/UpperPCB/MOSI: R30.2, U5.6 (SDI_MOSI), U5.12 (T_DIN), U7.5 (MOSI)
/UpperPCB/ON-OFF: D5.1, R21.2, U1.54 (ON_OFF)
/UpperPCB/OTA_KEY: J1.1, U1.19 (27_A13_SCK1)
/UpperPCB/OTA_RX: J1.5, U1.43 (21_A7_RX5_BCLK1), U16.3
/UpperPCB/OTA_TX: J1.4, U1.42 (20_A6_TX5_LRCLK1), U16.1
/UpperPCB/RS485+: D8.2 (A2), J4.1, J8.1, R39.2
/UpperPCB/RS485-: D14.1 (A1), J4.2, J8.2, R40.2
/UpperPCB/RS485-A: D12.2 (A), D13.1 (K), D15.2 (A2), R39.1, SW5.4, U8.12 (A)
/UpperPCB/RS485-B: D10.2 (A), D11.1 (K), D15.1 (A1), R40.1, SW5.3, U8.13 (B)
/UpperPCB/RS485_GND: C21.2, C23.2, C36.2, D11.2 (A), D13.2 (A), D15.3 (common), J4.3, J8.3, R26.1, U8.9 (GND2), U8.15 (GND2), U10.4 (Out-)
/UpperPCB/RX_4D: J15.3, U1.17 (25_A11_RX6_SDA2)
/UpperPCB/SPISCK: R33.1, U5.7 (SCK), U5.10 (T_CLK), U7.6 (SCK)
/UpperPCB/TX_4D: J15.2, U1.16 (24_A10_TX6_SCL2)
/UpperPCB/T_F1: R18.1, U1.18 (26_A12_MOSI1)
/UpperPCB/T_F2: C17.1, SW4.1, U1.31 (39_MISO1_OUT1A)
/UpperPCB/T_IRQ: C25.1, R20.2, U1.5 (3_LRCLK2)
/UpperPCB/UART_RX: U1.38 (16_A2_RX4_SCL1), U8.3 (RxD)
/UpperPCB/UART_TX: U1.39 (17_A3_TX4_SDA1), U8.6 (TxD)
/UpperPCB/UbDisplay: C10.1, C11.1, F2.2, U5.1 (VCC)
/UpperPCB/Ub_CAN_BUS: C5.1, C13.1, C37.1, U2.6 (Out+), U6.8 (VCC2)
/UpperPCB/Ub_RS485: C21.1, C23.1, C36.1, D10.1 (K), D12.1 (K), R25.2, U8.16 (VDD2), U10.6 (Out+)
/UpperPCB/VBAT: BT1.1 (+), R2.2, R23.2, U1.50 (VBAT)
/UpperPCB/~CS_D: R6.2, R29.2, U5.3 (~CS)
/UpperPCB/~CS_T: R27.2, U5.11 (~T_CS)
/UpperPCB/~EE_CS: R17.2, R32.1, U7.1 (~CS)
/UpperPCB/~EE_HOLD: R11.2, R31.1, U7.7 (~HOLD)
/UpperPCB/~SW_MODE_1: C27.1, J3.6, U1.45 (23_A9_CRX1_MCLK1)
/UpperPCB/~UART_RE: U1.40 (18_A4_SDA), U8.4 (~RE), U8.5 (DE)
/UpperPCB/~WP: JP1.2 (B), R12.2, U7.3 (~WP)
/WatchdogMod/EN_WD: R176.2, TP6.1, U48.3 (EN), U52.1 (OUT), U53.2
/WatchdogMod/TR-U50: D50.2 (A), R128.1, TP2.1, U40.2 (~RESET), U48.7 (~WDO), U50.2 (TR), U54.2
Earth: C15.2, C34.1, C35.2, D8.1 (A1), D14.2 (A2), J2.SH, J4.SH, J5.SH, J13.1, J14.1, J15.6, J16.1, J17.1, J18.1, J19.1, J20.1, J21.1, J22.1
GNDD: BT1.2 (-), C1.2, C2.2, C3.2, C4.2, C6.2, C7.2, C8.2, C10.2, C11.2, C12.2, C14.1, C16.2, C17.2, C18.2, C19.2, C20.2, C22.2, C24.2, C25.2, C26.2, C27.2, C28.2, C29.2, C30.1, C31.2, C32.2, C33.2, C38.2, C39.1, C50.2, C51.2, C73.1, C74.1, C75.1, C76.2, C78.2, C79.2, C95.2, C96.2, C103.1, C106.2, C107.2, D6.1 (K), D7.1 (A1), J1.3, J2.11, J3.1, J3.3, J3.5, J3.7, J4.9, J4.11, J5.9, J5.11, J15.4, JP1.1 (A), JP2.2, JP8.2, JP9.2, JP9.4, JP9.6, JP10.1, R23.1, R174.1, R175.1, SW2.2, SW3.2, SW4.2, SW6.1, TP5.1, U1.1 (GND), U1.34 (GND), U1.47 (GND), U1.52 (GND), U2.2 (In-), U3.2 (GND), U4.2 (GND), U5.2 (GND), U6.4 (GND1), U7.4 (GND), U8.2 (GND1), U8.8 (GND1), U9.2 (GND), U10.2 (In-), U12.1 (GND), U16.2 (GND), U40.1 (GND), U48.4 (GND), U48.9 (Pad), U49.3 (GND), U50.1 (GND), U51.3 (GND), U52.3 (VSS), U53.3 (GND), U54.3 (GND)
unnamed: C9.2, J2.2, J2.5
unnamed: C15.1, R13.1, R14.1, R15.1, R16.1
unnamed: C16.1, R18.2, SW3.1
unnamed: C18.1, D5.3, SW2.1
unnamed: C34.2, J6.2, JP2.3
unnamed: C35.1, J6.1, JP3.3
unnamed: C96.1, R169.2, U51.1, U51.2
unnamed: C33.1, D1.2 (A), L1.1
unnamed: D3.2 (A), R42.2
unnamed: D3.1 (K), U16.6
unnamed: D4.2 (A), R43.2
unnamed: D4.1 (K), U16.4
unnamed: D6.2 (A), R22.2
unnamed: C32.1, D7.2 (A2), F1.1, L1.2
unnamed: D50.1 (K), U49.4
unnamed: D122.2 (A), U53.4
unnamed: D122.1 (K), R174.2
unnamed: D123.2 (A), U54.4
unnamed: D123.1 (K), R175.2
unnamed: J2.12, R37.2
unnamed: J4.7, JP3.1
unnamed: J4.8, JP2.1
unnamed: J4.10, R7.2
unnamed: J4.12, R8.2
unnamed: J5.10, R9.2
unnamed: J5.12, R10.2
unnamed: F6.1, J15.1
unnamed: J15.5, JP7.1
unnamed: J4.4, JP4.1 (A)
unnamed: J4.5, JP5.1 (A)
unnamed: JP6.1 (A), R5.2
unnamed: JP6.2 (C), U5.4 (~RESET)
unnamed: C100.2, JP9.1
unnamed: C101.1, JP9.3
unnamed: C102.1, JP9.5
unnamed: JP10.2, JP10.4, JP10.6, U49.2
unnamed: C50.1, C78.1, L2.1, Q1.3 (D)
unnamed: Q1.1 (G), R124.2, R171.2
unnamed: Q2.1 (G), R38.1, U51.4
unnamed: R13.2, R14.2, SW1.2
unnamed: R15.2, R16.2, SW1.1
unnamed: R24.1, R25.1, SW5.1
unnamed: R24.2, R26.2, SW5.2
unnamed: R27.1, U1.10 (8_TX2_IN1)
unnamed: R28.1, U1.11 (9_OUT1C)
unnamed: R29.1, U1.12 (10_CS_MQSR)
unnamed: R30.1, U1.13 (11_MOSI_CTX1)
unnamed: R33.2, U1.35 (13_SCK_LED)
unnamed: R32.2, U1.36 (14_A0_TX3_SPDIF_OUT)
unnamed: R31.2, U1.37 (15_A1_RX3_SPDIF_IN)
unnamed: C2.1, F4.2, U2.1 (In+)
unnamed: C3.1, F5.2, U3.1 (VI)
unnamed: R4.2, U5.8 (LED)
unnamed: R35.2, U5.9 (SDO_MISO)
unnamed: R34.1, U5.13 (T_DO)
unnamed: R20.1, U5.14 (T_IRQ)
unnamed: R36.2, U7.2 (MISO)
unnamed: R3.2, U9.3 (IN)
unnamed: F2.1, F6.2, U9.1 (OUT)
unnamed: C22.1, F3.2, U10.1 (In+)
unnamed: U8.7 (PV), U12.2 (~RESET)
unnamed: C100.1, C101.2, C102.2, U48.2 (CWD)
unnamed: JP8.1, R172.2, U48.5 (SET1)
unnamed: C74.2, U50.5 (CV)
unnamed: C76.1, R133.1, U50.6 (THR), U50.7 (DIS)
unnamed: C106.1, U52.5 (CD)
OTA_5V: C24.1, C39.2, J1.2, Q3.3 (D), R42.1, R43.1, U16.5 (VCC)
OTA_EN: Q3.1 (G), R41.2, U1.30 (38_CS1_IN1)
WDI: R22.1, TP4.1, U1.33 (41_A17), U48.6 (WDI)
~Q: R169.1, R171.1, TP3.1, U50.3 (Q)
~RESET: C29.1, J3.4, JP6.3 (B), JP7.2, R1.2, SW6.2, U1.41 (19_A5_SCL), U49.1
~SW_MODE_2: C26.1, J3.8, JP10.3, U1.44 (22_A8_CTX1)

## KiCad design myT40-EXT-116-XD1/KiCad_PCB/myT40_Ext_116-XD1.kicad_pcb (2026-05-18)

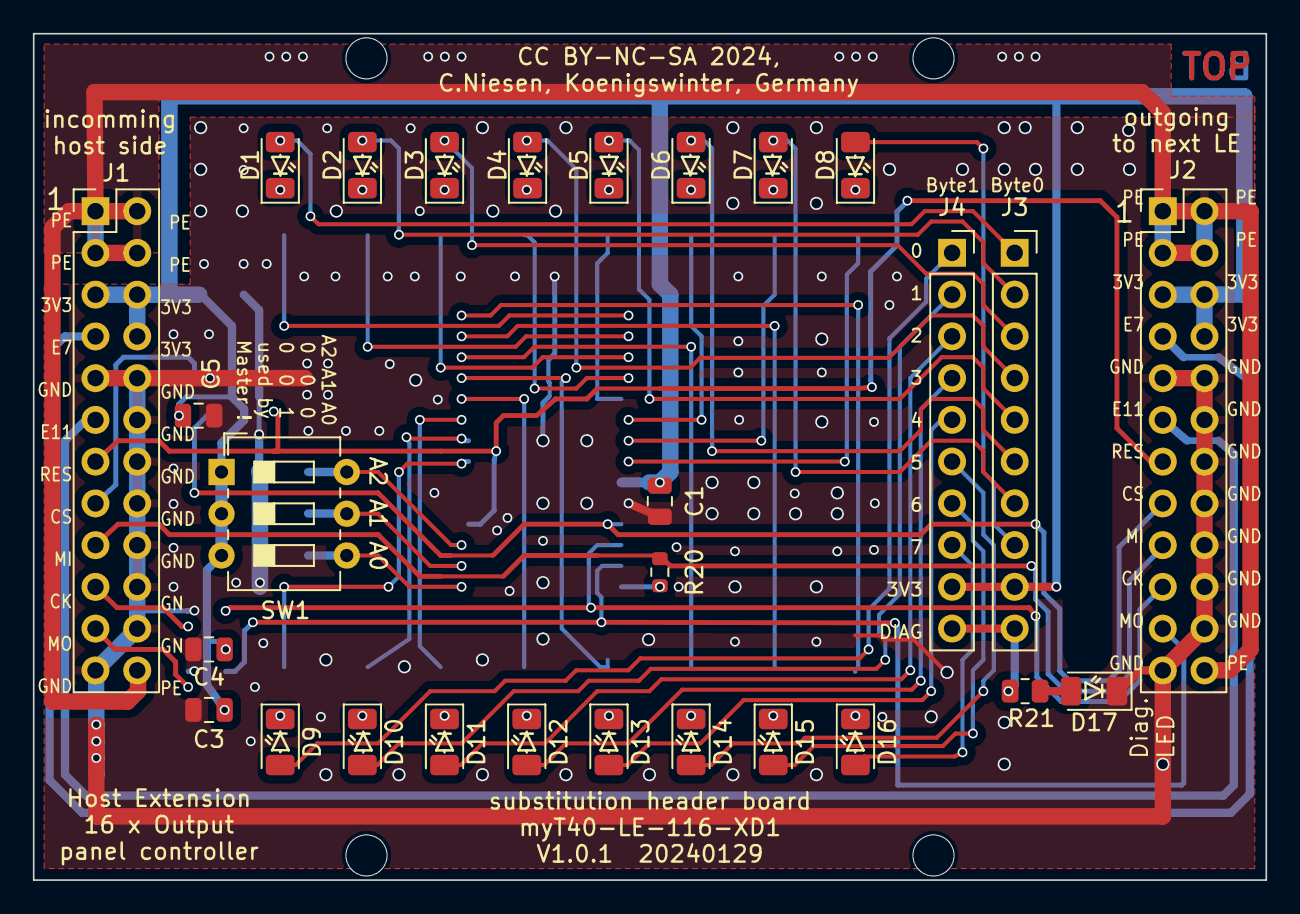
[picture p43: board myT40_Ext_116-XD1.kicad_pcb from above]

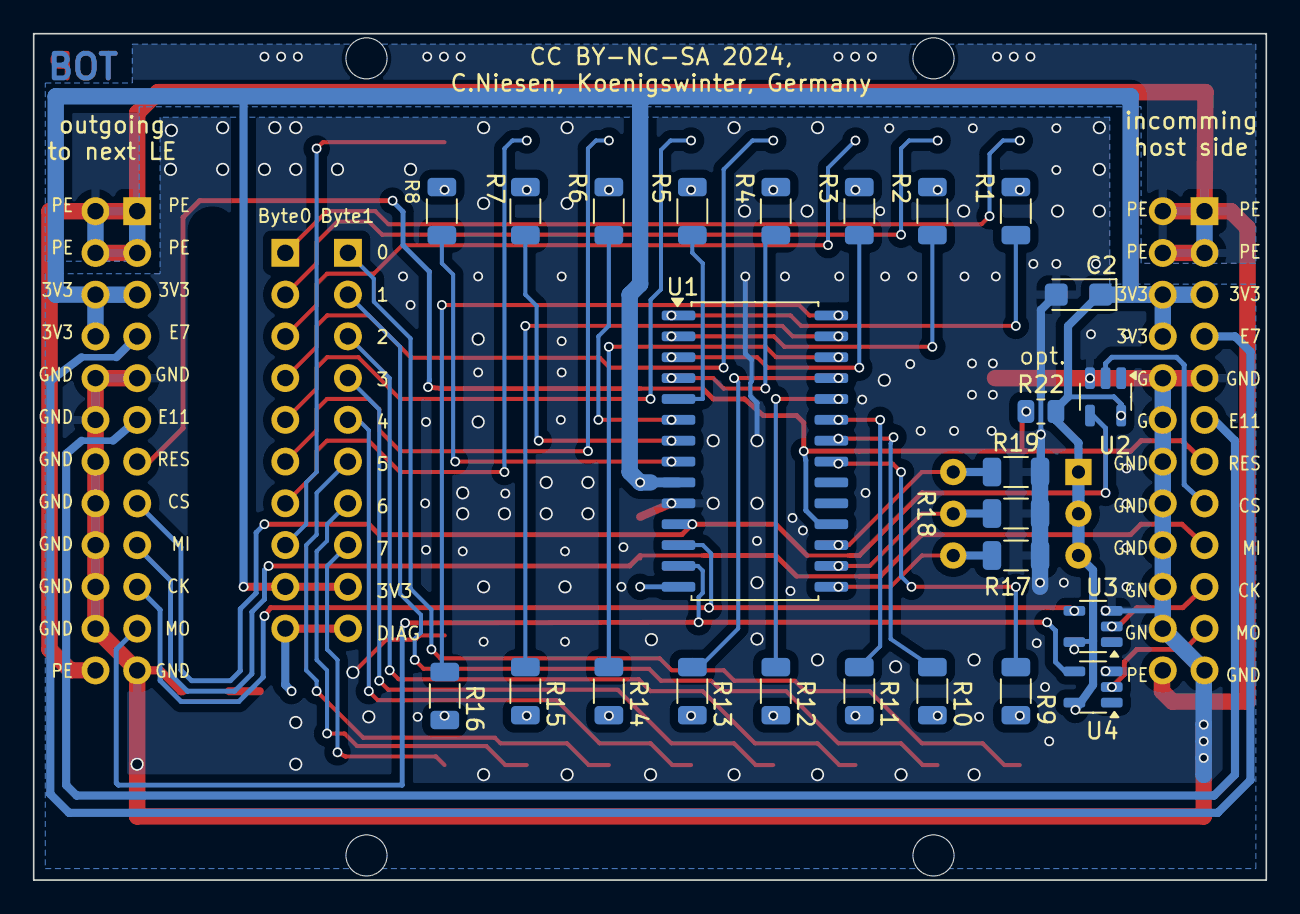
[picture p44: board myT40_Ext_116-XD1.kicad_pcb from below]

Board: 2 copper layers, 75.0 x 51.5 mm, 58 parts (25 on the bottom side), 67 nets.

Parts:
C1, C3, C4, C5: 100n; C_0805_2012Metric
C2: 1µ5; CP_EIA-3216-18_Kemet-A
D1, D2, D3, D4, D5, D6, D7, D8, D9, D10, D11, D12, D13, D14, D15, D16, D17: KPTD-3216; LED_1206_3216Metric
H1, H2, H3, H4, H5: MountingHole; MountingHole_2.5mm
J1: Ext-In 2x12; PinHeader_2x12_P2.54mm_Vertical
J2: Ext-Out 2x12; PinHeader_2x12_P2.54mm_Vertical
J3: Byte0 01x10; PinSocket_1x10_P2.54mm_Vertical
J4: Byte1 01x10; PinSocket_1x10_P2.54mm_Vertical
R1, R2, R3, R4, R5, R6, R7, R8, R9, R10, R11, R12, R13, R14, R15, R16: 270; R_1206_3216Metric
R17, R18, R19: 10k; R_1206_3216Metric
R20: 51; R_0603_1608Metric
R21: 470; R_0805_2012Metric
R22: 68k; R_0805_2012Metric
SW1: SW_DIP_x03; SW_DIP_SPSTx03_Slide_6.7x9.18mm_W7.62mm_P2.54mm_LowProfile
U1: MCP23S17_SO; SOIC-28W_7.5x17.9mm_P1.27mm
U2, U3, U4: SN74LVC1G17DBVTE4; SOT-23-5

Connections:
/3V3_INT: C1.1, C2.1, C3.1, C4.1, C5.1, J1.5, J1.6, J1.8, J2.5, J2.6, J2.8, J3.9, J4.9, R22.2, SW1.1, SW1.2, SW1.3, U1.9 (VDD), U2.5 (VCC), U3.5 (VCC), U4.5 (VCC)
/EXT_7: J1.7, J2.7
/EXT_11: J1.11, J2.11
/MISO: J1.17, J2.17, R20.2
/MOSI: J2.21, U1.13 (SI), U4.4
/MOSI_: J1.21, U4.2
/PE: J1.1, J1.2, J1.3, J1.4, J1.24, J2.1, J2.2, J2.3, J2.4, J2.24
/SPISCK: J2.19, U1.12 (SCK), U3.4
/SPISCK_: J1.19, U3.2
/~RESET: J1.13, J2.13, R22.1, U1.18 (~RESET)
/~SPICS_IO_: J1.15, U2.2
/~SPICS_IO: J2.15, U1.11 (~CS), U2.4
GNDD: C1.2, C2.2, C3.2, C4.2, C5.2, D17.1 (K), J1.9, J1.10, J1.12, J1.14, J1.16, J1.18, J1.20, J1.22, J1.23, J2.9, J2.10, J2.12, J2.14, J2.16, J2.18, J2.20, J2.22, J2.23, R17.1, R18.1, R19.1, U1.10 (VSS), U2.3 (GND), U3.3 (GND), U4.3 (GND)
unnamed: D1.2 (A), J3.1
unnamed: D1.1 (K), R1.2
unnamed: D2.2 (A), J3.2
unnamed: D2.1 (K), R2.2
unnamed: D3.2 (A), J3.3
unnamed: D3.1 (K), R3.2
unnamed: D4.2 (A), J3.4
unnamed: D4.1 (K), R4.2
unnamed: D5.2 (A), J3.5
unnamed: D5.1 (K), R5.2
unnamed: D6.2 (A), J3.6
unnamed: D6.1 (K), R6.2
unnamed: D7.2 (A), J3.7
unnamed: D7.1 (K), R7.2
unnamed: D8.2 (A), J3.8
unnamed: D8.1 (K), R8.2
unnamed: D9.2 (A), J4.1
unnamed: D9.1 (K), R9.2
unnamed: D10.2 (A), J4.2
unnamed: D10.1 (K), R10.2
unnamed: D11.2 (A), J4.3
unnamed: D11.1 (K), R11.2
unnamed: D12.2 (A), J4.4
unnamed: D12.1 (K), R12.2
unnamed: D13.2 (A), J4.5
unnamed: D13.1 (K), R13.2
unnamed: D14.2 (A), J4.6
unnamed: D14.1 (K), R14.2
unnamed: D15.2 (A), J4.7
unnamed: D15.1 (K), R15.2
unnamed: D16.2 (A), J4.8
unnamed: D16.1 (K), R16.2
unnamed: D17.2 (A), R21.1
unnamed: J3.10, J4.10, R21.2
unnamed: R17.2, SW1.4, U1.15 (A0)
unnamed: R18.2, SW1.5, U1.16 (A1)
unnamed: R19.2, SW1.6, U1.17 (A2)
unnamed: R9.1, U1.21 (GPA0)
unnamed: R10.1, U1.22 (GPA1)
unnamed: R11.1, U1.23 (GPA2)
unnamed: R12.1, U1.24 (GPA3)
unnamed: R13.1, U1.25 (GPA4)
unnamed: R14.1, U1.26 (GPA5)
unnamed: R15.1, U1.27 (GPA6)
unnamed: R16.1, U1.28 (GPA7)
unnamed: R1.1, U1.1 (GPB0)
unnamed: R2.1, U1.2 (GPB1)
unnamed: R3.1, U1.3 (GPB2)
unnamed: R4.1, U1.4 (GPB3)
unnamed: R5.1, U1.5 (GPB4)
unnamed: R6.1, U1.6 (GPB5)
unnamed: R7.1, U1.7 (GPB6)
unnamed: R8.1, U1.8 (GPB7)
unnamed: R20.1, U1.14 (SO)

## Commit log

2023-11-17 First Upload myT40-...
    [OP.kicad_pcb, UP.kicad_pcb, myT41-Controller.kicad_pcb]
2023-11-25 Dokumentation Readme, Ankündigung der Überarbeitung und M37
2023-12-04 V2.6 M37 PFS
    [OP.kicad_pcb, UP.kicad_pcb, myT40-PLC_PFS_2.6_M37_STKL.csv]
2023-12-05 Edit Doc and PartsList
    [OP.kicad_pcb, UP.kicad_pcb, myT40-PLC_PFS_2.6_M37_STKL.csv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]
2023-12-06 Ansteuerung Q2 verändert
    Ansteuerung auf UP über Brücke J34 J36 ist entfallen.
    [UP.kicad_pcb]
2023-12-06 STKL angepasst
    [myT40-PLC_PFS_2.6_M37_STKL_ALL.csv]
2023-12-15 OP routing optimized
    [OP.kicad_pcb]
2023-12-15 OP PCB mods CPU
    [OP.kicad_pcb]
2023-12-15 OP variant 4 Layer PCB
    [OP.kicad_pcb]
2023-12-15 Edit comment PCB
2023-12-15 PCB V2.6 M37 vom 15.12.2023
    see readme
2023-12-22 Kaltstart Überarbeitung
    [OP.kicad_pcb, UP.kicad_pcb, myT40-PLC_PFS_2.6_M37_STKL_ALL.csv]
2023-12-29 Überarbeitung 4-Layer-Layout und Dokumentation
    [OP.kicad_pcb, UP.kicad_pcb]
2024-03-01 V2.6 R38 final PFS
    M38 final Version for PFS variant
    [OP.kicad_pcb, UP.kicad_pcb, myT40-PLC_PFS_2.6_M37_STKL_ALL.csv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]
2024-05-27 V2.8 M40 Coldstart Issues
    Coldstart issues, some PullUps to high dimensioned, no high logic resulting together with switched-off Teensy and its input impedances.
    [OP.kicad_pcb, UP.kicad_pcb]
2024-07-04 Update README.md
    continuing developement of Prototype4 /M38
2024-07-05 Final version V2.9 M41
    Cold start issues solved.
    [OP.kicad_pcb, UP.kicad_pcb, myT40-PLC_PFS_2.6_M38_STKL_ALL.csv]
2025-11-20 V5 is ready
    V5 is ready.
    Doc in writing.
    New is: external watchdog plus delay for this watchdog.
    [OP.kicad_pcb, UP.kicad_pcb]
2025-11-27 Version-5-Final Dokumentation Draft
    Dokumentation Draft Version-5-final (V3.1.M43) PFS
    [myT40_STKL_V3.1_M43_Version-5.csv]
2026-05-17 Final V5 Upload
    Uploading final Version May 2026 V5
    PCB, Partslist, Sheets.
    Doku outstanding
    [OP.kicad_pcb, UP.kicad_pcb, myT40-V5-PFS_PARTS.csv]
2026-05-17 myT41-Controller V3.1
    [myT41-C.kicad_pcb]
2026-05-18 Docu and extention
    [OP.kicad_pcb, UP.kicad_pcb, myT40-PLC_PFS_2.6_M38_STKL_ALL.csv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]
2026-09-18 myT40-PLC V5 ready to production
    myT40-PLC Rev3.3 M44 V5
    Documentation reduced to V5
    [OP.kicad_pcb, UP.kicad_pcb, myT40-PLC_PFS_2.6_M38_STKL_ALL.csv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]
2026-09-18 Further correction of Intro an provisioning of Circuit diagrams based on format SVG
2026-09-18 und nochmal

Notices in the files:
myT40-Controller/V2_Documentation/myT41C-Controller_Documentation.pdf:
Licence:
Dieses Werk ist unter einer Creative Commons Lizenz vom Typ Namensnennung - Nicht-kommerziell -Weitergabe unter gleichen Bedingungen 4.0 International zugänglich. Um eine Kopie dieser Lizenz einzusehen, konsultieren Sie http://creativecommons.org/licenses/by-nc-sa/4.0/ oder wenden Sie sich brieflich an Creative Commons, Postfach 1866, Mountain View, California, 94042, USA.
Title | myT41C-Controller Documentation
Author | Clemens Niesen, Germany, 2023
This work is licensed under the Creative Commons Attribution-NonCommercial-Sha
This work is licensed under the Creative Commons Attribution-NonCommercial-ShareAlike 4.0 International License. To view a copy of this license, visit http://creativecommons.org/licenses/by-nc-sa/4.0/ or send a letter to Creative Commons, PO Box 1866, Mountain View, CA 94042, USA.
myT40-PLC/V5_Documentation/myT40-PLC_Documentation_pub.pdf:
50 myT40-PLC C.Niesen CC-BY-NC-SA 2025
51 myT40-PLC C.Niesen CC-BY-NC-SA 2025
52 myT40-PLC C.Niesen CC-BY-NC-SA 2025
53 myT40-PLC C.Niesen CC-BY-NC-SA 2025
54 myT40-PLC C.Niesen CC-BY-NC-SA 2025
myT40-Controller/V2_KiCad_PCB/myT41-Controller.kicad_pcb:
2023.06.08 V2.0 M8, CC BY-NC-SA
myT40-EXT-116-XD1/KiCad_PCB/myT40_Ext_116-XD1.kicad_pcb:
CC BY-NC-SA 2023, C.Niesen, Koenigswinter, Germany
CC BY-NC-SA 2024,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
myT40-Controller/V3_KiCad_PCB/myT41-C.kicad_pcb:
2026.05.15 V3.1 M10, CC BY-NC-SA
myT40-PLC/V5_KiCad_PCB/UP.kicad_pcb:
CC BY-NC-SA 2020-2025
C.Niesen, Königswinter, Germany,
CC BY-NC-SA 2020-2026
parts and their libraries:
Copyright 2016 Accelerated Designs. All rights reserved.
